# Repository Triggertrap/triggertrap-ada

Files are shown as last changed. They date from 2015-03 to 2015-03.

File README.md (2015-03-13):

# triggertrap-ada

Ada source code

##Contents

1. About Ada
2. Licence Information
3. About this document
4. Adafruit files
5. Atmel Libraries
6. Arduino Libraries
7. Ada project files
8. EEPROM addresses
9. Creating a new mode
10. Notes on building firmware

##1. About Ada

Ada is a project created by Triggertrap (triggertrap.com), designed to be the world's fastest and easiest to use high-speed camera trigger. An initial prototype was created for a Kickstarter project (tri.gg/kickstarter2), and a significant of additional work was completed in order to bring the product to market. 

Triggertrap was unsuccessful in putting Ada into production, but are releasing the work completed under a GPLv3 open source licence. For full information about where to find all open-source parts of Ada, please see: http://tri.gg/adasource

The electronics and firmware for Ada was developed by Cubik Innovation (cubik-innovation.co.uk). Some additional changes to the firmware was done by Nick Johnson of Arachnid Labs (arachnidlabs.com). 

For discussion about this source code, please see the Ada forum - http://forum.triggertrap.com/categories/triggertrap-ada

##2. Licence Information

For licence information, please see Licence.txt. 

Please note: 
* **Triggertrap**  is a trademark of Triggertrap Ltd, and may not be used without prior permission from Triggertrap. 
* **Timewarp**  is a trademark of Triggertrap Ltd, and may not be used without prior permission from Triggertrap. 
* **Ada** is a trademark of Triggertrap Ltd, and may not be used *commercially* without prior permission from Triggertrap. 
* **Arduino**, **Adafruit** and other trademarks may be present in the Ada source code. Please ensure that you respect the respective trademarks and trademark owners. 

##3. About this document

This project contains all the source files needed to compile the running code on the Ada device. An outline of what each file is and does is provided below

The project has been developed using files sourced from Atmel, Arduino, Adafruit and akafugu,  plus a number of application specific files written specially for this purpose.

##4. Adafruit files

Adafruit_PCD8544.cpp
Adafruit_PCD8544.h

* From lady ada and can be located at https://github.com/adafruit/Adafruit-PCD8544-Nokia-5110-LCD-library

Adafruit_GFX.cpp and Adafruit_GFX.h and glcdfont7x5.c

* From lady ada and can be located at https://github.com/adafruit/Adafruit-GFX-Library

## 5. Atmel Libraries

rtc.c
rtc.h

* Not used in project but included as an alternative to clock.c. Requires development

Iox128a3.h

* Chip specific header file

compiler.h and parts.h

* Compiler definitions and typedefs 

TC_driver.c
TC_driver.h

* Timer and counter driver files

## 6. Arduino Libraries

Arduino.h

* Holds defines used by Arduino 

binary.h

* Holds definitions for binary numbers used by Arduino

ByteBuffer.cpp
ByteBuffer.h

* Classes that handle buffer creation and use 

Client.h

* Arduino files for using internet protocols

HardwareSerial.h

* UART header file 

IPAddress.cpp

IPAddress.h

* Contains functions to handle IP addresses used by Arduino

main.cpp

* main program entry, just calls application main

new.cpp and new.h

* Contains new and delete operators for dynamic memory allocation

pins_arduino.h

* Pin mapping of the hardware against Arduino standard definitions

Print.cpp and Print.h

* Contains functions such as print() and println()

Printable.h

* Interface class that allows printing of complex types

Server.h

* Function headers for Ethernet related files

Stream.cpp

Stream.h

* adds parsing methods to Stream class

Tone.cpp

* Tone Generation

WCharacter.h

* Character utility functions for Wiring & Arduino

WInterupts.c

* Functions relating to interrupts of the device

Wire.h

* Two wire library for Arduino & wiring

wiring.c

* Contains low level drivers for delays initiating IO ports, ADCs etc

wiring_analog.c

* Contains functions relating to ADC and PWM

wiring_digital.c

* digital input and output functions

wiring_private.h

* definitions for wiring

EEPROM.cpp and EEPROM.h

* Arduino EEPROM library

Udp.h

* Arduino library to send/receive UDP packets
* 
* All files originated from http://arduino.cc/ but files have been modified to fit with the ATXMEGA and have therefore been based on files obtained from http://www.akafugu.jp/posts/products/akafuino_x/

###/debug (folder)

avrdude.exe

* avrdude compiler 

Makefile

* Project makefile

upload.bat

* bootloader upload batch file

## 6. Ada project files

glcdfont7x5.c

* Contains bitmaps for the 7x5 font used in the project.

AdvancedSensor.cpp

* Contains all functions relating to Advanced Sensor mode

BulbRamp.cpp

* Contains all functions relating to Bulb Ramp mode

Clock.cpp
Clock.h

* Contains all functions relating to the system clock time

eeprom_addresses.h

* Contains all addresses for the EEPROM used in the project

glcdfont.c

* Contains the pixel maps for the 5x5 font used in the project

guimenu.cpp

guimenu.h

* Contains all low level functions related to the graphical user interface

guimenu_pages.c

* Contains the data for the menu banners

guimenu_pages.h

* Contains the GUI page definitions

guimenupages.cpp

* Contains the Ada splash screen logo and the information for each page

HardwareGlobals.h

* Contains the definitions for the pins on the processor that are used in the project

Inputs.cpp
Inputs.h

* Contains all the functions related to user input from the buttons

LongExposureHDR.cpp

LongExposureHDR.h

* Contains all functions relating to the long exposure high dynamic range mode

Menu.h

* Contains all the prototypes for the functions accessed by the menu

MenuDefines.h

* Contains defines for the menu state machine along with some other misc defines

MobileTrigger.cpp

* Contains a function that sets up the PWM required for mobile out

NewMode.cpp

NewMode.h

* Contains examples for how to create your own mode within the unit

Sensor.cpp

* Contains functions relating to the sensor mode

SensorConfigs.cpp

* Contains functions for sending configurations to the sensors

SensorTimelapse.cpp

* Contains functions for sensor timelapse mode

SensorVideo.cpp

* Contains functions for sensor video mode

Settings.cpp

* Contains functions for the settings page

StarTrail.cpp

* Contains functions for startrail mode

StateMachine.cpp

* This file contains the main framework of the menu system. It must be called periodically in order to update the menu.

TriggerTrap.cppproj

* Atmel studio project file

TriggerTrap_main.cpp

* Main project entry file contains the high level operations of the system

tt_strings.dat

* Contains the strings used throughout the menu and the array that contains them

tt_strings.h

* Contains the definitions of the individual string location in the data array

Timelapse.cpp

Timelapse.h

* Contains the functions related to the timelapse mode

TimeWarp.cpp

* Contains the functions related to the timewarp mode
 
## 8. EEPROM addresses

EEPROM locations are referenced in the code using their labels, however the absolute addresses may be found in eeprom_addresses.h

###System Settings
EEPROM_STACK_CONFIG

* Data to determine if the stack is in AND/OR mode

EEPROM_LCD_CONTRAST_SET

* Determines if the contrast has been set by the user/factory yet

EEPROM_LCD_CONTRAST

* Data for the LCD contrast value

### Timelapse Settings
EEPROM_TIMELAPSE_INTERVAL_HI

EEPROM_TIMELAPSE_INTERVAL_LO

EEPROM_TIMELAPSE_INTERVAL_UNITS

* Setting for the delay between shots in timelapse mode

EEPROM_TIMELAPSE_COUNT_HI

EEPROM_TIMELAPSE_COUNT_LO

EEPROM_TIMELAPSE_COUNT_UNITS

* How many shots in the timelapse train

EEPROM_TIMELAPSE_STARTDELAY_HI

EEPROM_TIMELAPSE_STARTDELAY_LO

EEPROM_TIMELAPSE_STARTDELAY_UNITS

* Delay before the timelapse should start

EEPROM_TIMELAPSE_ACTIVE

* Defines if timelapse is limited by a time frame or not

###Timewarp Settings

EEPROM_TIMEWARP_COUNT_HI

EEPROM_TIMEWARP_COUNT_LO

* Holds data for how many shots are in timewarp

EEPROM_TIMEWARP_DURATION_HI

EEPROM_TIMEWARP_DURATION_LO

EEPROM_TIMEWARP_DURATION_UNITS

* Holds data for how the duration of the timewarp function

EEPROM_TIMEWARP_FUNCTION

* Defines if timewarp works as Quadratic/Quartic/Quintic

EEPROM_TIMEWARP_DIRECTION

* Defines the direction of the timewarp function

EEPROM_TIMEWARP_WAIT_HI

EEPROM_TIMEWARP_WAIT_LO

EEPROM_TIMEWARP_WAIT_UNITS

* Defines the wait before starting time

###Bulb Ramping
EEPROM_BULBRAMP_START_EXPOSURE

* Relates to Bulbramp start exposure value

EEPROM_BULBRAMP_END_EXPOSURE

* Relates to Bulbramp end exposure value

EEPROM_BULBRAMP_STARTDELAY_HI

EEPROM_BULBRAMP_STARTDELAY_LO

EEPROM_BULBRAMP_STARTDELAY_UNITS

* Holds data for the bulbramp start delay

EEPROM_BULBRAMP_COUNT_HI

EEPROM_BULBRAMP_COUNT_LO

* Holds data for the bulbramp count

EEPROM_BULBRAMP_DURATION_HI

EEPROM_BULBRAMP_DURATION_LO

EEPROM_BULBRAMP_DURATION_UNITS

* Holds data for the bulbramp duration

###Star Trail

EEPROM_STARTTRAIL_INTERVAL_HI

EEPROM_STARTTRAIL_INTERVAL_LO

EEPROM_STARTTRAIL_INTERVAL_UNITS

* Holds data for the interval time

EEPROM_STARTTRAIL_SHUTTERSPEED_HI

EEPROM_STARTTRAIL_SHUTTERSPEED_LO

EEPROM_STARTTRAIL_SHUTTERSPEED_UNITS

* Holds data for the star trail shutter speed

EEPROM_STARTTRAIL_COUNT_HI

EEPROM_STARTTRAIL_COUNT_LO

* Holds data for the startrail count

EEPROM_STARTTRAIL_WAIT_HI

EEPROM_STARTTRAIL_WAIT_LO

EEPROM_STARTTRAIL_WAIT_UNITS

* Holds data for Startrail wait time

###High Speed Flash
EEPROM_HSF_TRIGGERON

* Data for stack configuration for this mode

EEPROM_HSF_CLOSESHUTTER

* Data for determining if the shutter should close

EEPROM_HSF_SHUTTERCYCLE_HI

EEPROM_HSF_SHUTTERCYCLE_LO

EEPROM_HSF_SHUTTERCYCLE_UNITS

* Shutter cycle time

EEPROM_HSF_FLASHDELAY_HI

EEPROM_HSF_FLASHDELAY_LO

EEPROM_HSF_FLASHDELAY_UNITS

* Flash delay time

EEPROM_HSF_RESETDELAY_HI

EEPROM_HSF_RESETDELAY_LO

EEPROM_HSF_RESETDELAY_UNITS

* Reset delay time

EEPROM_HSF_TIMESACTIVE

* Determines if HSF mode is bound by a time window

EEPROM_HSF_START_HOURS

EEPROM_HSF_START_MINS

EEPROM_HSF_END_HOURS

EEPROM_HSF_END_MINS

* Start and end times for HSF times active

###Sensor

EEPROM_SENSOR_TRIGDELAY_HI

EEPROM_SENSOR_TRIGDELAY_LO

EEPROM_SENSOR_TRIGDELAY_UNITS

* Sensor trigger delay times

EEPROM_SENSOR_TRIGGERON

* Data for stack configuration for this mode

EEPROM_SENSOR_MOBILEIP

* Mobile input on/off indicator

EEPROM_SENSOR_MOBILEOP

* Mobile output on/off indicator

EEPROM_SENSOR_TIMESACTIVE

* Determines if sensor mode is bound by a time window

###Sensor Timelapse

EEPROM_SENSORTLAPSE_DELAY_HI

EEPROM_SENSORTLAPSE_DELAY_LO

EEPROM_SENSORTLAPSE_DELAY_UNITS

* Sensor time lapse delay time

EEPROM_SENSORTLAPSE_INTERVAL_HI

EEPROM_SENSORTLAPSE_INTERVAL_LO

EEPROM_SENSORTLAPSE_INTERVAL_UNITS

* Sensor timelapse interval time

EEPROM_SENSORTLAPSE_CONTINUE_HI

EEPROM_SENSORTLAPSE_CONTINUE_LO

* Determines how many shots to continue for

EEPROM_SENSORTLAPSE_TRIGGERON

* Data for stack configuration for this mode

EEPROM_SENSORTLAPSE_MOBILEIP

* Mobile input on/off indicator

EEPROM_SENSORTLAPSE_MOBILEOP

* Mobile output on/off indicator

EEPROM_SENSORTLAPSE_TIMESACTIVE

* Determines if sensor timelapse mode is bound by a time window

###Sensor Video
EEPROM_SENSORVIDEO_DELAY_HI

EEPROM_SENSORVIDEO_DELAY_LO

EEPROM_SENSORVIDEO_DELAY_UNITS

* Sensor video setup delay time

EEPROM_SENSORVIDEO_STOPAFTER_HI

EEPROM_SENSORVIDEO_STOPAFTER_LO

EEPROM_SENSORVIDEO_STOPAFTER_UNITS

* Sensor video stop after time setting

EEPROM_SENSORVIDEO_TRIGGER

* Camera/Mobile/Both setting

EEPROM_SENSORVIDEO_TIMESACTIVE

* Determines if sensor mode is bound by a time window

EEPROM_SENSORVIDEO_TRIGGERON

* Data for stack configuration for this mode

###Advanced Sensor

EEPROM_ADVSENSOR_CHAN1A

EEPROM_ADVSENSOR_CHAN1B

EEPROM_ADVSENSOR_CHAN2A

EEPROM_ADVSENSOR_CHAN2B

EEPROM_ADVSENSOR_CHAN3A

EEPROM_ADVSENSOR_CHAN3B

* Unused

EEPROM_ADVSENSOR_TRIGMOBILE

* Defines if the mobile output is enabled or not

###Settings

EEPROM_CAMERAPREFOCUS_HI

EEPROM_CAMERAPREFOCUS_LO

EEPROM_CAMERAPREFOCUS_UNITS

* Camera prefocus time 

EEPROM_FLASHPULSE_HI

EEPROM_FLASHPULSE_LO

EEPROM_FLASHPULSE_UNITS

* Camera flash pulse time

EEPROM_SHUTTERPULSE_HI

EEPROM_SHUTTERPULSE_LO

EEPROM_SHUTTERPULSE_UNITS

* Shutter open time

EEPROM_TIMELAPSE_STARTHOURS

EEPROM_TIMELAPSE_STARTMINS

EEPROM_TIMELAPSE_ENDHOURS

EEPROM_TIMELAPSE_ENDMINS

* Timelapse start and end times for times active mode

EEPROM_SENSORVIDEO_START_HOURS

EEPROM_SENSORVIDEO_START_MINS

EEPROM_SENSORVIDEO_END_HOURS

EEPROM_SENSORVIDEO_END_MINS

* Sensor video start and end times for times active mode

###LE_HDR
EEPROM_LEHDR_MID_EXP

* LEHDR middle exposure length

EEPROM_LEHDR_SHOTS

* LEHDR number of shots

EEPROM_LEHDR_EVPERSHOT

* The amount at which the exposure should change between shots

EEPROM_LEHDR_TIMELAPSE_HI

EEPROM_LEHDR_TIMELAPSE_LO

EEPROM_LEHDR_TIMELAPSE_UNITS

* LEHDR timelapseinterval time

EEPROM_SENSOR_TL_START_HOURS

EEPROM_SENSOR_TL_START_MINS

EEPROM_SENSOR_TL_END_HOURS

EEPROM_SENSOR_TL_END_MINS

* Sensor Timelapse start and end times

EEPROM_SENSORTLAPSE_CONTINUE

* Defines if sensor timelapse mode will stop on absence of sensor activity/infinite shots/x shots

EEPROM_SENSOR_REST_DELAY_HI

EEPROM_SENSOR_REST_DELAY_LO

EEPROM_SENSOR_RESET_UNITS

* Sensor reset delay time

EEPROM_SENSOR_START_HOURS

EEPROM_SENSOR_START_MINS

EEPROM_SENSOR_END_HOURS

EEPROM_SENSOR_END_MINS

* Sensor start and end times for times active mode

###Advanced Sensor

EEPROM_ADVSENSOR_CHAN1A_DELAY_HI

EEPROM_ADVSENSOR_CHAN1A_DELAY_LO

EEPROM_ADVSENSOR_CHAN1A_DELAY_UNITS

* Advanced Sensor channel 1A delay time

EEPROM_ADVSENSOR_CHAN1B_DELAY_HI

EEPROM_ADVSENSOR_CHAN1B_DELAY_LO

EEPROM_ADVSENSOR_CHAN1B_DELAY_UNITS

* Advanced Sensor channel 1B delay time

EEPROM_ADVSENSOR_CHAN2A_DELAY_HI

EEPROM_ADVSENSOR_CHAN2A_DELAY_LO

EEPROM_ADVSENSOR_CHAN2A_DELAY_UNITS

* Advanced Sensor channel 2A delay time

EEPROM_ADVSENSOR_CHAN2B_DELAY_HI

EEPROM_ADVSENSOR_CHAN2B_DELAY_LO

EEPROM_ADVSENSOR_CHAN2B_DELAY_UNITS

* Advanced Sensor channel 2B delay time

EEPROM_ADVSENSOR_CHAN3A_DELAY_HI

EEPROM_ADVSENSOR_CHAN3A_DELAY_LO

EEPROM_ADVSENSOR_CHAN3A_DELAY_UNITS

* Advanced Sensor channel 3A delay time

EEPROM_ADVSENSOR_CHAN3B_DELAY_HI

EEPROM_ADVSENSOR_CHAN3B_DELAY_LO

EEPROM_ADVSENSOR_CHAN3B_DELAY_UNITS

* Advanced Sensor channel 1A delay time

###pulse duration

EEPROM_ADVSENSOR_CHAN1A_PULSE_HI

EEPROM_ADVSENSOR_CHAN1A_PULSE_LO

EEPROM_ADVSENSOR_CHAN1A_PULSE_UNITS

* Advanced Sensor channel 1A pulse length

EEPROM_ADVSENSOR_CHAN1B_PULSE_HI

EEPROM_ADVSENSOR_CHAN1B_PULSE_LO

EEPROM_ADVSENSOR_CHAN1B_PULSE_UNITS

* Advanced Sensor channel 1B pulse length

EEPROM_ADVSENSOR_CHAN2A_PULSE_HI

EEPROM_ADVSENSOR_CHAN2A_PULSE_LO

EEPROM_ADVSENSOR_CHAN2A_PULSE_UNITS

* Advanced Sensor channel 2A pulse length

EEPROM_ADVSENSOR_CHAN2B_PULSE_HI

EEPROM_ADVSENSOR_CHAN2B_PULSE_LO

EEPROM_ADVSENSOR_CHAN2B_PULSE_UNITS

* Advanced Sensor channel 2B pulse length

EEPROM_ADVSENSOR_CHAN3A_PULSE_HI

EEPROM_ADVSENSOR_CHAN3A_PULSE_LO

EEPROM_ADVSENSOR_CHAN3A_PULSE_UNITS

* Advanced Sensor channel 3A pulse length

EEPROM_ADVSENSOR_CHAN3B_PULSE_HI

EEPROM_ADVSENSOR_CHAN3B_PULSE_LO

EEPROM_ADVSENSOR_CHAN3B_PULSE_UNITS

* Advanced Sensor channel 3B pulse length

EEPROM_ADVSENSOR_REST_DELAY_HI

EEPROM_ADVSENSOR_REST_DELAY_LO

EEPROM_ADVSENSOR_REST_DELAY_UNITS

* Advanced Sensor reset delay time

EEPROM_ADVSENSOR_TRIGGER_ON

* Data for stack configuration for this mode

EEPROM_TIME_HOURS

EEPROM_TIME_MINS

EEPROM_TIME_SECS

* RTC has a roll-over of approx. 18hrs. Alarm is configured to wake the micro before then, save the current time here and reset the counter

EEPROM_NEWMODE_TRIGGERON

EEPROM_NEWMODE_DELAY_HI

EEPROM_NEWMODE_DELAY_LO

EEPROM_NEWMODE_DELAY_UNITS

* Delay times for new mode example

EEPROM_NONE

* Null

##9. Creating a new mode

* Examples on how to include a new mode have been given in this project. The user must add in the definition: 

define INCLUDE_NEWMODE 

* This could either be defined in a file such as MenuDefines.h or it could be added as a symbol in the project properties. This will allow an example mode to appear on the device. This can be modified at will for experimentation. 

* Further information on how to make your own mode can be found in the comments of NewMode.cpp

##10. Notes on building firmware
The Baseblock firmware has been updated so it can be built using avr-gcc and make, however both the Bootloader and the Sensor firmware have not been converted to allow for this process.

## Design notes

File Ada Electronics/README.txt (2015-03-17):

IMPORTANT NOTE

To facilitate expediency in releasing these files, these are the actual production files that were to be use for Ada's production run. 

As such, they may include 'Triggertrap', 'Ada' and 'Tt' logos, and references to 'TimeWarp', all of which are trademarked. If you intend to use these files, ensure that the logos are removed from the models, PCB, and source code etc before they are used. 

The files may also include references to FCC and CE marking and certification. These tests were completed with prototypes, but the certifications may not apply to you. As such, please ensure that the FCC and CE markings are removed, or that your device is re-certified, before you use these files.

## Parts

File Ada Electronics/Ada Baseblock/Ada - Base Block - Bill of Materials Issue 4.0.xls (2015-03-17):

Project Number | TRI002
Variant: | Var1 of TRI002 Base Unit Issue 4.0
Creation Date: | 10/13/2014 |  | 5:43:55 PM
Print Date: | 2014-10-13 |  | 17:44:30
BOM VERSION | Issue 4.0
Designator | Fitted | Value | Voltage | Footprint | Quantity | Supplier | Part No. | Qty to Order | Manufacturer | Manuf Part #
C1, C2 | Fitted | 18pF | 50V | C0603 | 2 | FEC | 1414620 |  | KEMET | C0603C180J5GAC
C3, C4, C8, C16, C20 | Fitted | 100nF | 50V | C0603 | 5 | Rapid | 71-1964 |  | TruCap | U0603R103
C5, C6, C18, C19 | Fitted | 10nF | 50V | C0603 | 4 | Rapid | 71-1964 |  | MULTICOMP | MCCA000238
C7, C10, C11 | Fitted | 1uF | 16V | C0603 | 3 | FEC | 1288256 |  | KEMET | C0603C105K4PAC
C9 | Fitted | 4u7F | 10V | KEMET CASE A | 1 | FEC | 1457427 |  | KEMET | T491A475K010AT
C12 | Fitted | 47uF | 16V | CAP6.8/6.8 | 1 | FEC | 8823200 |  | NICHICON | UUT1C470MCL1GS
C13, C17 | Fitted | 2u2F | 16V | C0603 | 2 | FEC | 1658871 |  | AVX | 0603YD225KAT2A
C15 | Fitted | 220uF | 16V | CAP6.8/6.8 | 1 | FEC | 1539479 |  | PANASONIC | EEEFPC221XAP
D1, D2 | Fitted | SS12 E3 | 20V | DO214-AA | 2 | Rapid | 47-0988 |  | Taiwan Semiconductor | SS12 E3
D3 | Fitted | MBRM110LT3G | ?V | POWERMITE | 1 | FEC | 1459062 |  | ON SEMICONDUCTOR | MBRM110LT3G
F1 | Fitted | polyfuse | 24V max | 1210 FUSE | 1 | FEC | 1822208 |  | LITTELFUSE | 1210L050YR
J2 | Fitted | Daughter Board Con |  | sip3 | 1
J3, J6, J7, J9 | Fitted | 2.5mm |  | 2.5mm socket TRI001 | 4 | FEC | 1280745 |  | PRO SIGNAL | PSG01539
J4 | Fitted | JTAG Header |  | HDR2X3 | 1 | Rapid | 22-0500 |  | TruConnect
J5 | Fitted | FFC 6 way top contact |  | HLW6R-2C7LF | 1 | MOUSER | 649-HLW6R-2C7LF |  | FCI | HLW6R-2C7LF
J8 | Fitted | 22-05-7025 |  | Molex 0022057025 | 1 | FEC | 9979670 |  | MOLEX | 22-05-7025
J10 | Fitted | micro USB Female |  | micro usb receptacle | 1 | MOUSER | 649-10118192-0001LF |  | FCI | 10118192-0001LF
J11 | Fitted | 3.5MM 4 pole Socket |  | Cliff 3.5mm 4 pole socket | 1 | FEC | 2309468 |  | CLIFF ELECTRONIC | FC68125
J12 | Fitted | Stack Con |  | sip3 | 1
L1, L3, L4, L5, L6 | Fitted | BLM18EG221TN1D |  | L0603 | 5 | FEC | 1515717 |  | MURATA | BLM18EG221TN1D
L2 | Fitted | 10µH |  | WE-PD2_5848 | 1 | FEC | 1636014 |  | Würth Elektronik eiSos GmbH | 74477410
LCD1 | Fitted | LPH7366-1 |  | LPH-7366 | 1 | www.008620.net | LPH7366-1 |  | Na | na
LED1, LED2, LED3, LED4 | Fitted | MCL-S270SRC |  | LED, RED, 0805 | 4 | FEC | 1581239 |  | MULTICOMP | MCL-S270SRC
Q1 | Fitted | FDN335N |  | SOT-23 | 1 | FEC | 9845348RL |  | FAIRCHILD SEMICONDUCTOR | FDN335N
Q2 | Fitted |  | 8V | SOT-23 DIODE - duplicate | 1 | FEC | NTR2101PT1G |  | ON SEMICONDUCTOR | NTR2101PT1G
Q3 | Fitted | BC847B |  | SOT-23T | 1
Q4 | Fitted | NTGS3446T1G |  | TSOP6 | 1 | RS | 802-4221 |  | ON Semiconductor | NTGS3446T1G
R1, R2, R3, R4, R5, R6, R8, R25, R27, R28, R36 | Fitted | 10k |  | R0603 | 11
R7, R12 | Fitted | 1M |  | R0603 | 2
R9, R11, R30, R31 | Fitted | 100R |  | R0603 | 4
R10, R13, R15, R16, R17, R18, R19, R20, R26 | Fitted | 1K |  | R0603 | 9
R14, R29 | Fitted | 220R |  | R0603 | 2
R21, R23 | Fitted | 22R |  | R0603 | 2
R22, R24 | Fitted | 4K7 |  | R0603 | 2
R32, R35 | Fitted | 0R |  | R0603 | 2
U1 | Fitted | ATXMEGA128A3-AU |  | 64A_N | 1 | FEC | 1748550 |  | ATMEL | ATXMEGA128A3-AU
U2, U3, U5, U6, U7, U8 | Fitted | LTV-357T |  | SMD-4 | 6 | MOUSER | 859-LTV-357T |  | Lite-on | LTV-357T
U4 | Fitted | AAT3221IGV-3.3-T1 |  | TSOT 5 pin | 1 | MOUSER | 873-AAT3221IGV-33T1 |  | Skyworks Solutions | AAT3221IGV-3.3-T1
U9 | Fitted | NCP1450ASN50T1G |  | SOT23-5AN | 1 | FEC | 1460676 |  | ON SEMICONDUCTOR | NCP1450ASN50T1G
U10 | Fitted | FT230X |  | SSOP-16_N | 1 | MOUSER | 895-FT230XS-R |  | FTDI | FT230XS-R
X1 | Fitted | 32.768KHz |  | FC 13F | 1 | FEC | 1712821 |  | EPSON TOYOCOM | FC-13F,32.768KHZ, 12.5PF
C14 | Not Fitted | 100nF | 50V | C0603 | 0 | Rapid | 71-1964 |  | TruCap | U0603R103
R33, R34 | Not Fitted | 0R |  | R0603 | 0

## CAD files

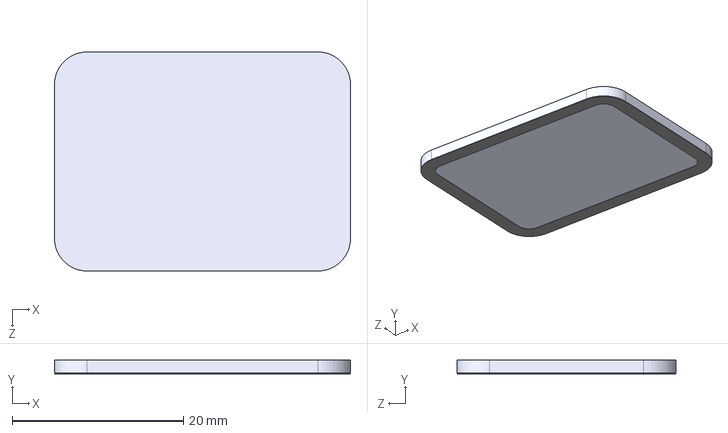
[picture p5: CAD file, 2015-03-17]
Ada Casing/TT-Issue-A_STP_files/TT-113-A_ADA_LCD_SCREEN.STEP
34.6 x 1.60 x 25.6 mm

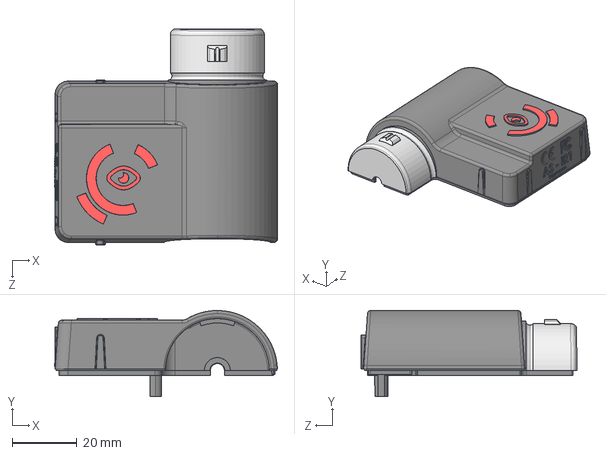
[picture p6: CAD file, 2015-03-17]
Ada Casing/TT-Issue-A_STP_files/TT-221-A_SENSOR_FRONT_CASE_PIR.STEP
68.7 x 26.5 x 66.5 mm

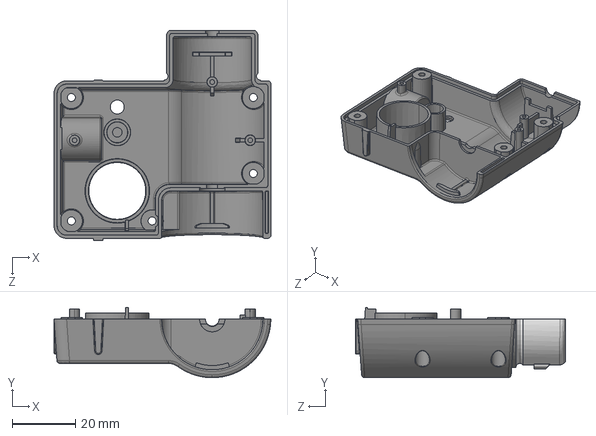
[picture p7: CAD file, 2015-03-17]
Ada Casing/TT-Issue-A_STP_files/TT-211-A_SENSOR_BACK_CASE_PIR_SOUND_LIGHT.STEP
68.6 x 22.3 x 66.5 mm

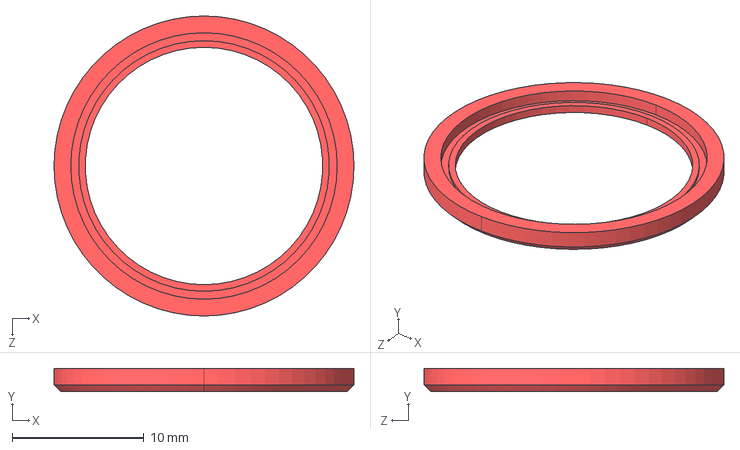
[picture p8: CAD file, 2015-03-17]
Ada Casing/TT-Issue-A_STP_files/TT-231-A_LENS_RETAINING_RING.STEP
22.8 x 1.75 x 22.8 mm

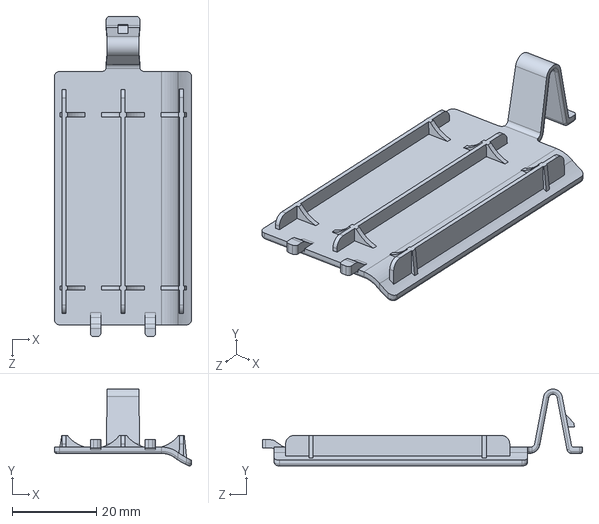
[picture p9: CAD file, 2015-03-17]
Ada Casing/TT-Issue-A_STP_files/TT-120-A_ADA_BASE_BATTERY_COVER.STEP
32.5 x 18.2 x 75.8 mm

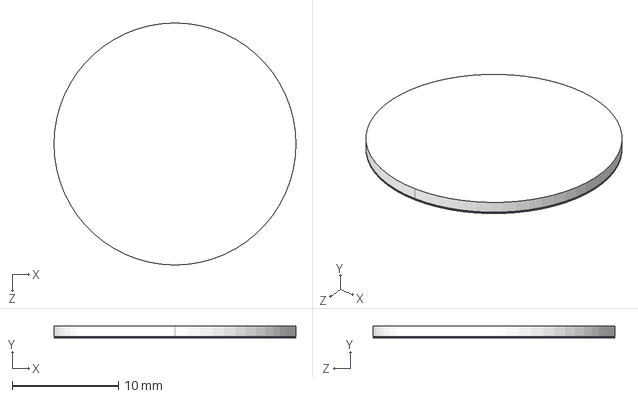
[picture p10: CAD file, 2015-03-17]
Ada Casing/TT-Issue-A_STP_files/TT-230-A_SENSOR_DISC_LASER_LIGHT.STEP
22.8 x 1.15 x 22.8 mm

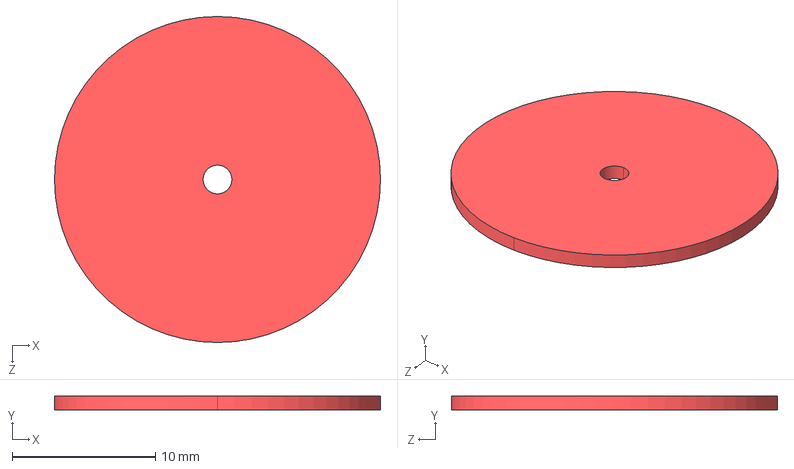
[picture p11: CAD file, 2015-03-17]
Ada Casing/TT-Issue-A_STP_files/TT-232-A_SENSOR_DISC_SOUND.STEP
22.8 x 1.00 x 22.8 mm

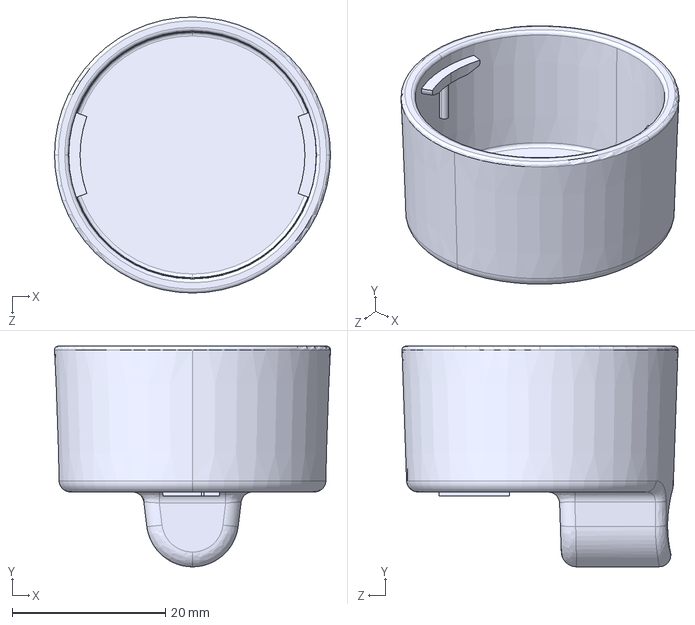
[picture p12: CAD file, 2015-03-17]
Ada Casing/TT-Issue-A_STP_files/TT-260-A_ADA_MIRROR_BODY.STEP
36.0 x 28.7 x 36.0 mm

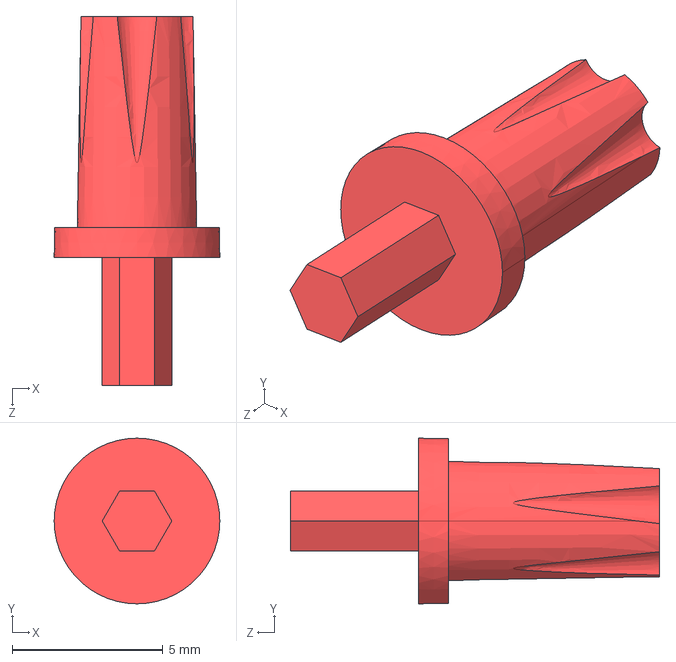
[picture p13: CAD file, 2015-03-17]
Ada Casing/TT-Issue-A_STP_files/TT-250-A_SENSOR_pot_knob.STEP
5.50 x 5.50 x 12.2 mm

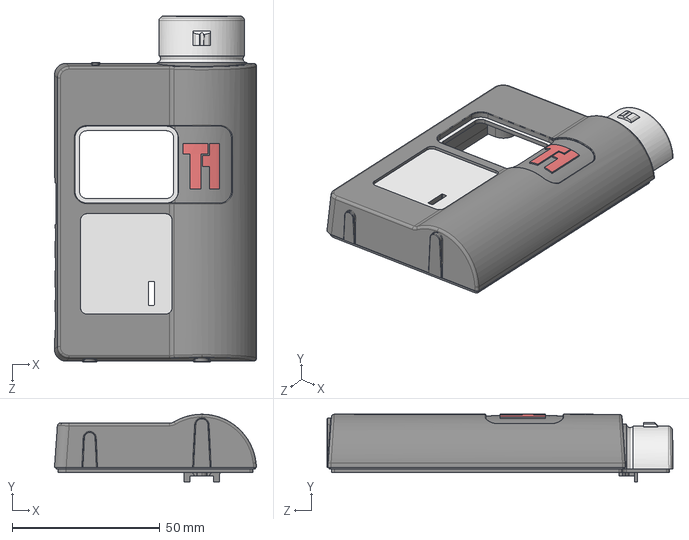
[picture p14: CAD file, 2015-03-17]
Ada Casing/TT-Issue-A_STP_files/TT-110-A_ADA_BASE_FRONT_CASE.STEP
68.5 x 22.9 x 117.2 mm

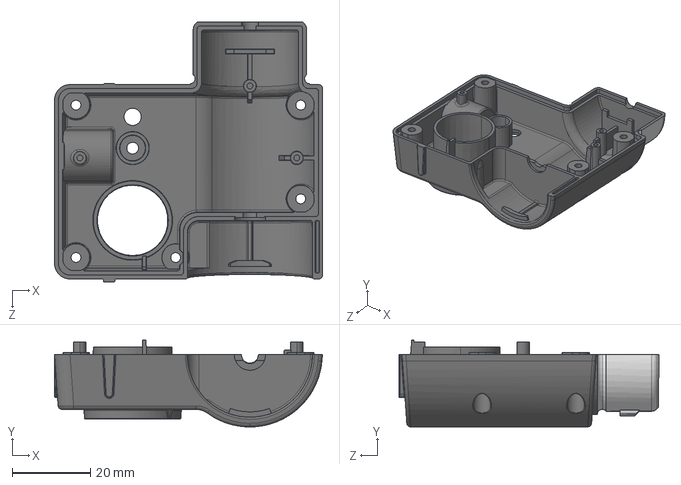
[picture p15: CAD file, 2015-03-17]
Ada Casing/TT-Issue-A_STP_files/TT-210-A_SENSOR_BACK_CASE_LASER.STEP
68.6 x 22.3 x 66.5 mm

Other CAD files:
Triggertrap Sensors/TRIG.X/dist/default/production/TRIG.X.production.obj
Triggertrap Sensors/TRIG.X/l.obj
Ada Casing/TT-Issue-A_STP_files/TT-222-A_SENSOR_FRONT_CASE_SOUND.STEP
Ada Casing/TT-Issue-A_STP_files/TT-225-A_SENSOR_FRONT_CASE_LIGHT.STEP
Ada Casing/TT-Issue-A_STP_files/TT-220-A_SENSOR_FRONT_CASE_LASER.STEP

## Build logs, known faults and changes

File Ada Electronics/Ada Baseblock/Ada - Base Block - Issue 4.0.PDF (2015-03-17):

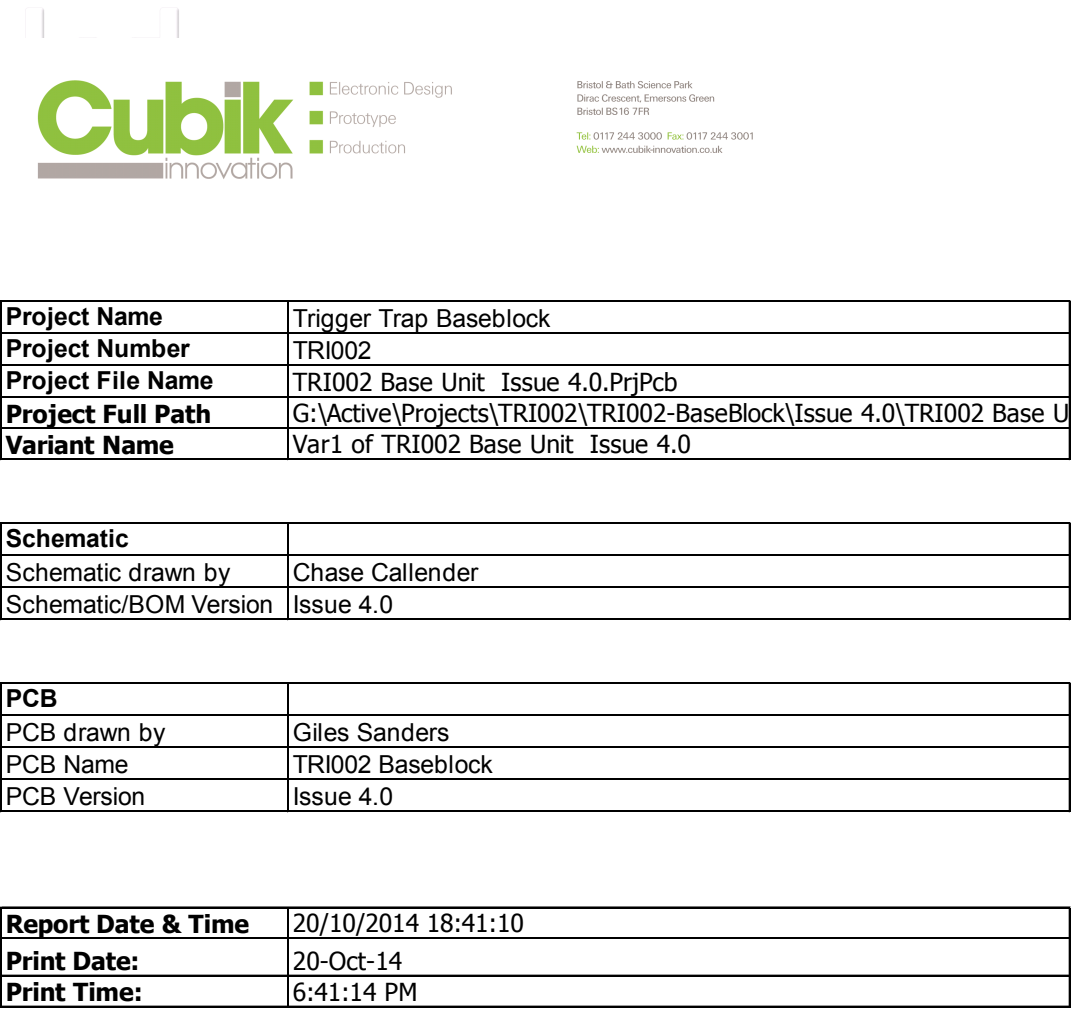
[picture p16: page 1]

Project Name | Trigger Trap Baseblock
Project Number | TRI002
Project File Name | TRI002 Base Unit Issue 4.0.PrjPcb
Project Full Path | G:\Active\Projects\TRI002\TRI002-BaseBlock\Issue 4.0\TRI002 Base U
Variant Name | Var1 of TRI002 Base Unit Issue 4.0

Schematic
Schematic drawn by | Chase Callender
Schematic/BOM Version | Issue 4.0

PCB
PCB drawn by | Giles Sanders
PCB Name | TRI002 Baseblock
PCB Version | Issue 4.0

Report Date & Time | 20/10/2014 18:41:10
Print Date: | 20-Oct-14
Print Time: | 6:41:14 PM

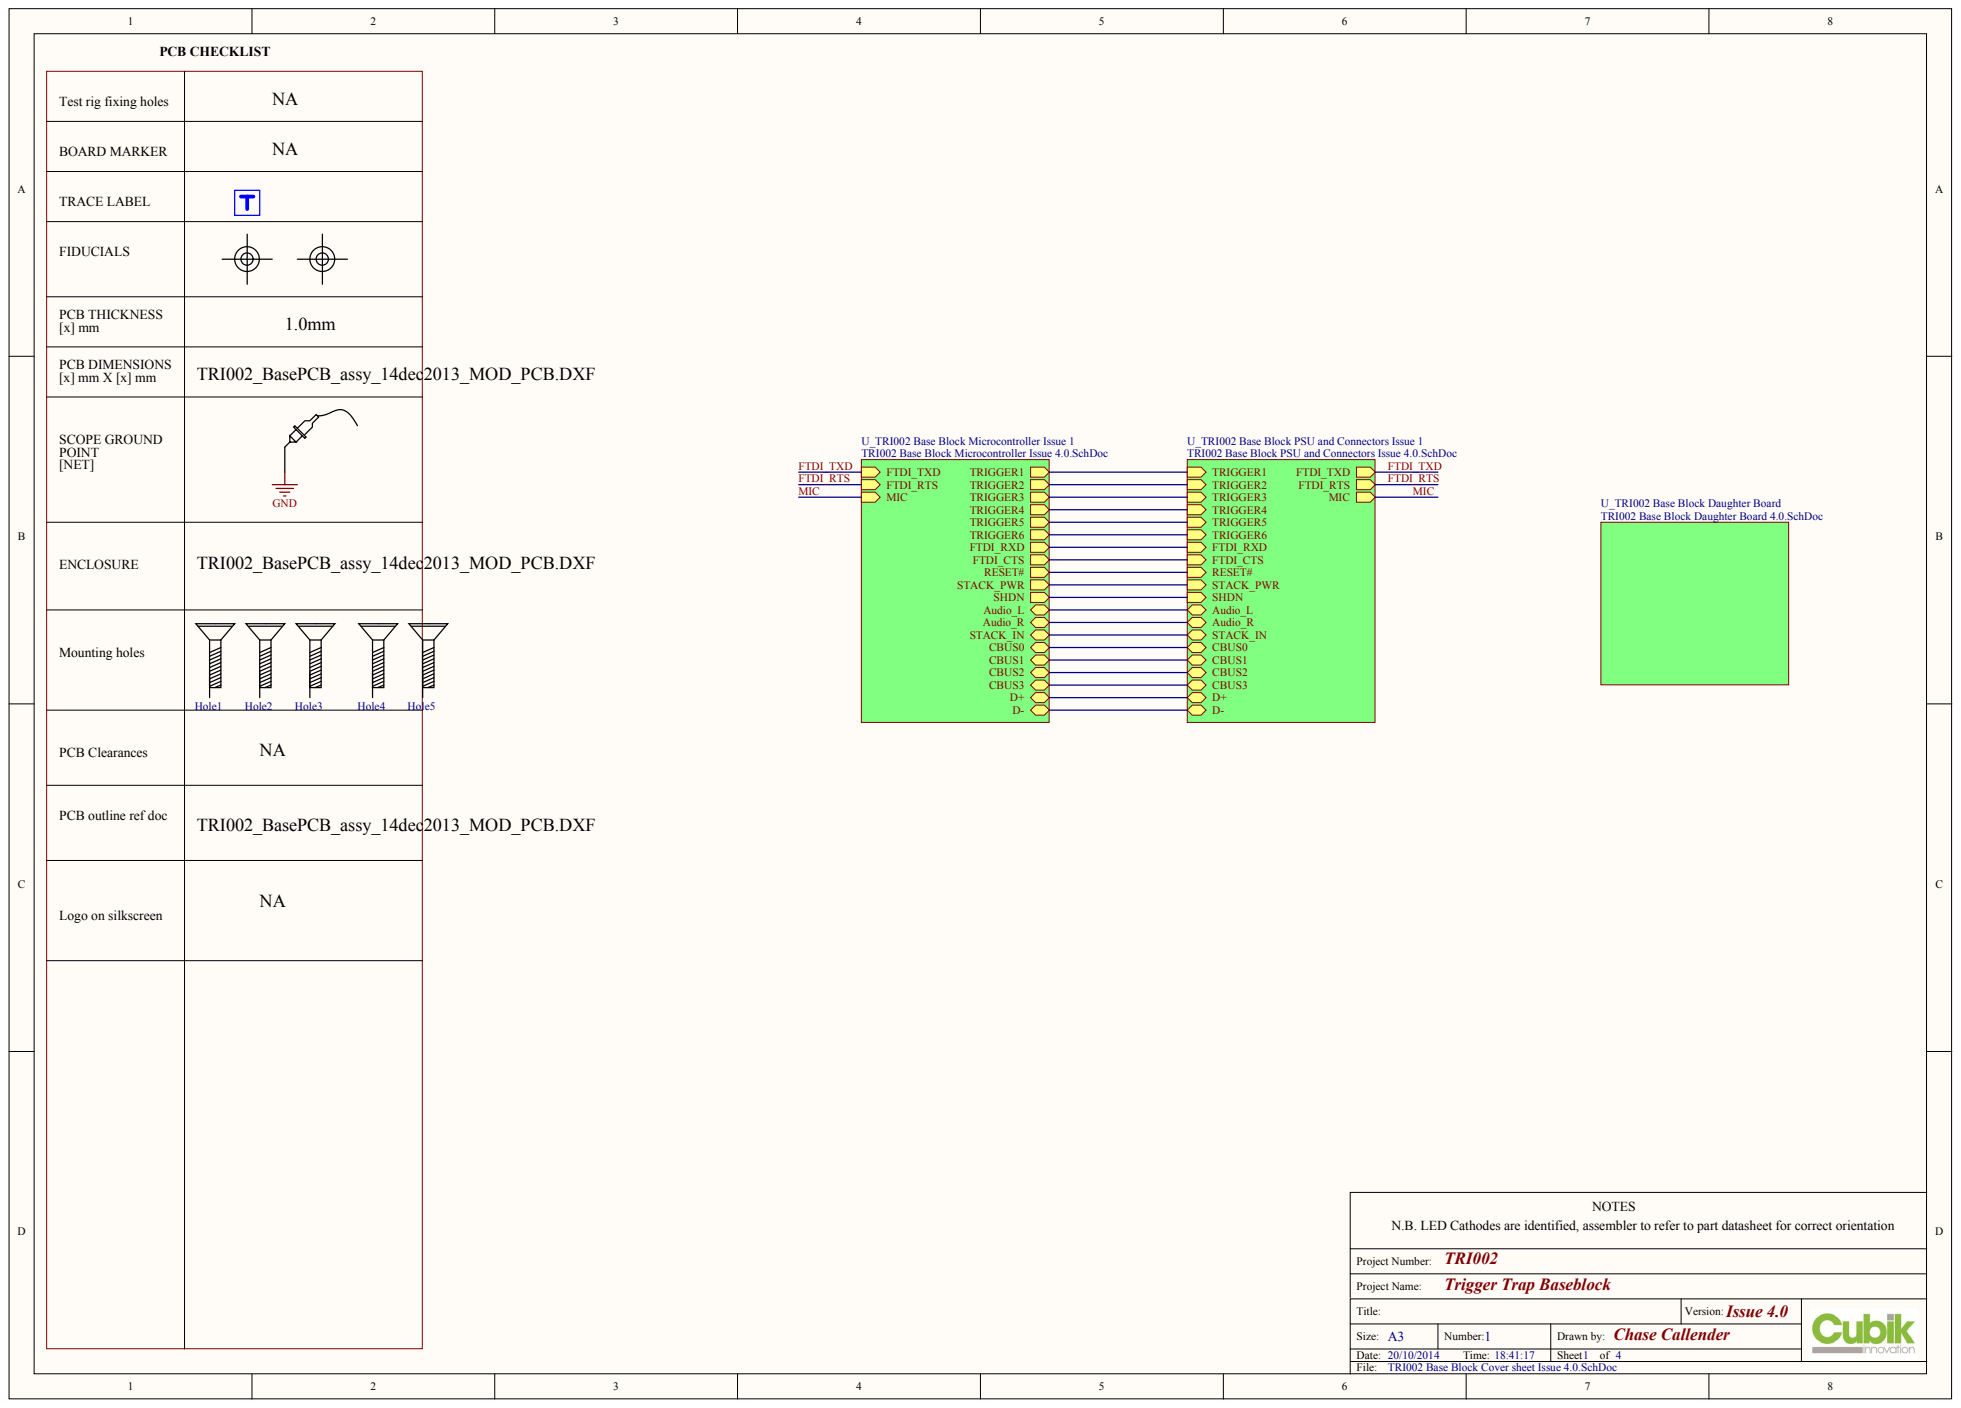
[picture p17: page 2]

Test rig fixing holes | NA

BOARD MARKER | NA

TRACE LABEL

FIDUCIALS

PCB THICKNESS [x] mm | 1.0mm

PCB DIMENSIONS [x] mm X [x] mm

SCOPE GROUND POINT [NET]

U_TRI002 Base Block Microcontroller Issue 1
TRI002 Base Block Microcontroller Issue 4.0.SchDoc
FTDI_TXD
FTDI_RTS
MIC

U_TRI002 Base Block Daughter Board
TRI002 Base Block Daughter Board 4.0.SchDoc

ENCLOSURE | TRI002_BasePCB_assy_14dec2013_MOD_PCB.DXF

Mounting holes

PCB Clearances | NA

PCB outline ref doc

Logo on silkscreen | NA

N.B. LED Cathodes are identified, assembler to refer to part datasheet for correct orientation

Title: | Issue 4.0 Version:
Size: A3 | Number: 1 | Drawn by: Chase Callender

Date: 20/10/2014 Time: 18:41:17 | | Sheet 1 of 4

TRI002 Base Block Cover sheet Issue 4.0.SchDoc

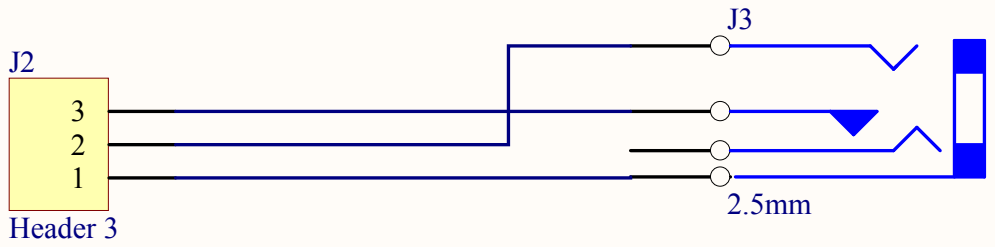
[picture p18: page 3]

Title: | Issue 4.0 Version:
Size: A | Number: 2 | Chase Callende r

Date: Time: | | Sheet 2 of 4

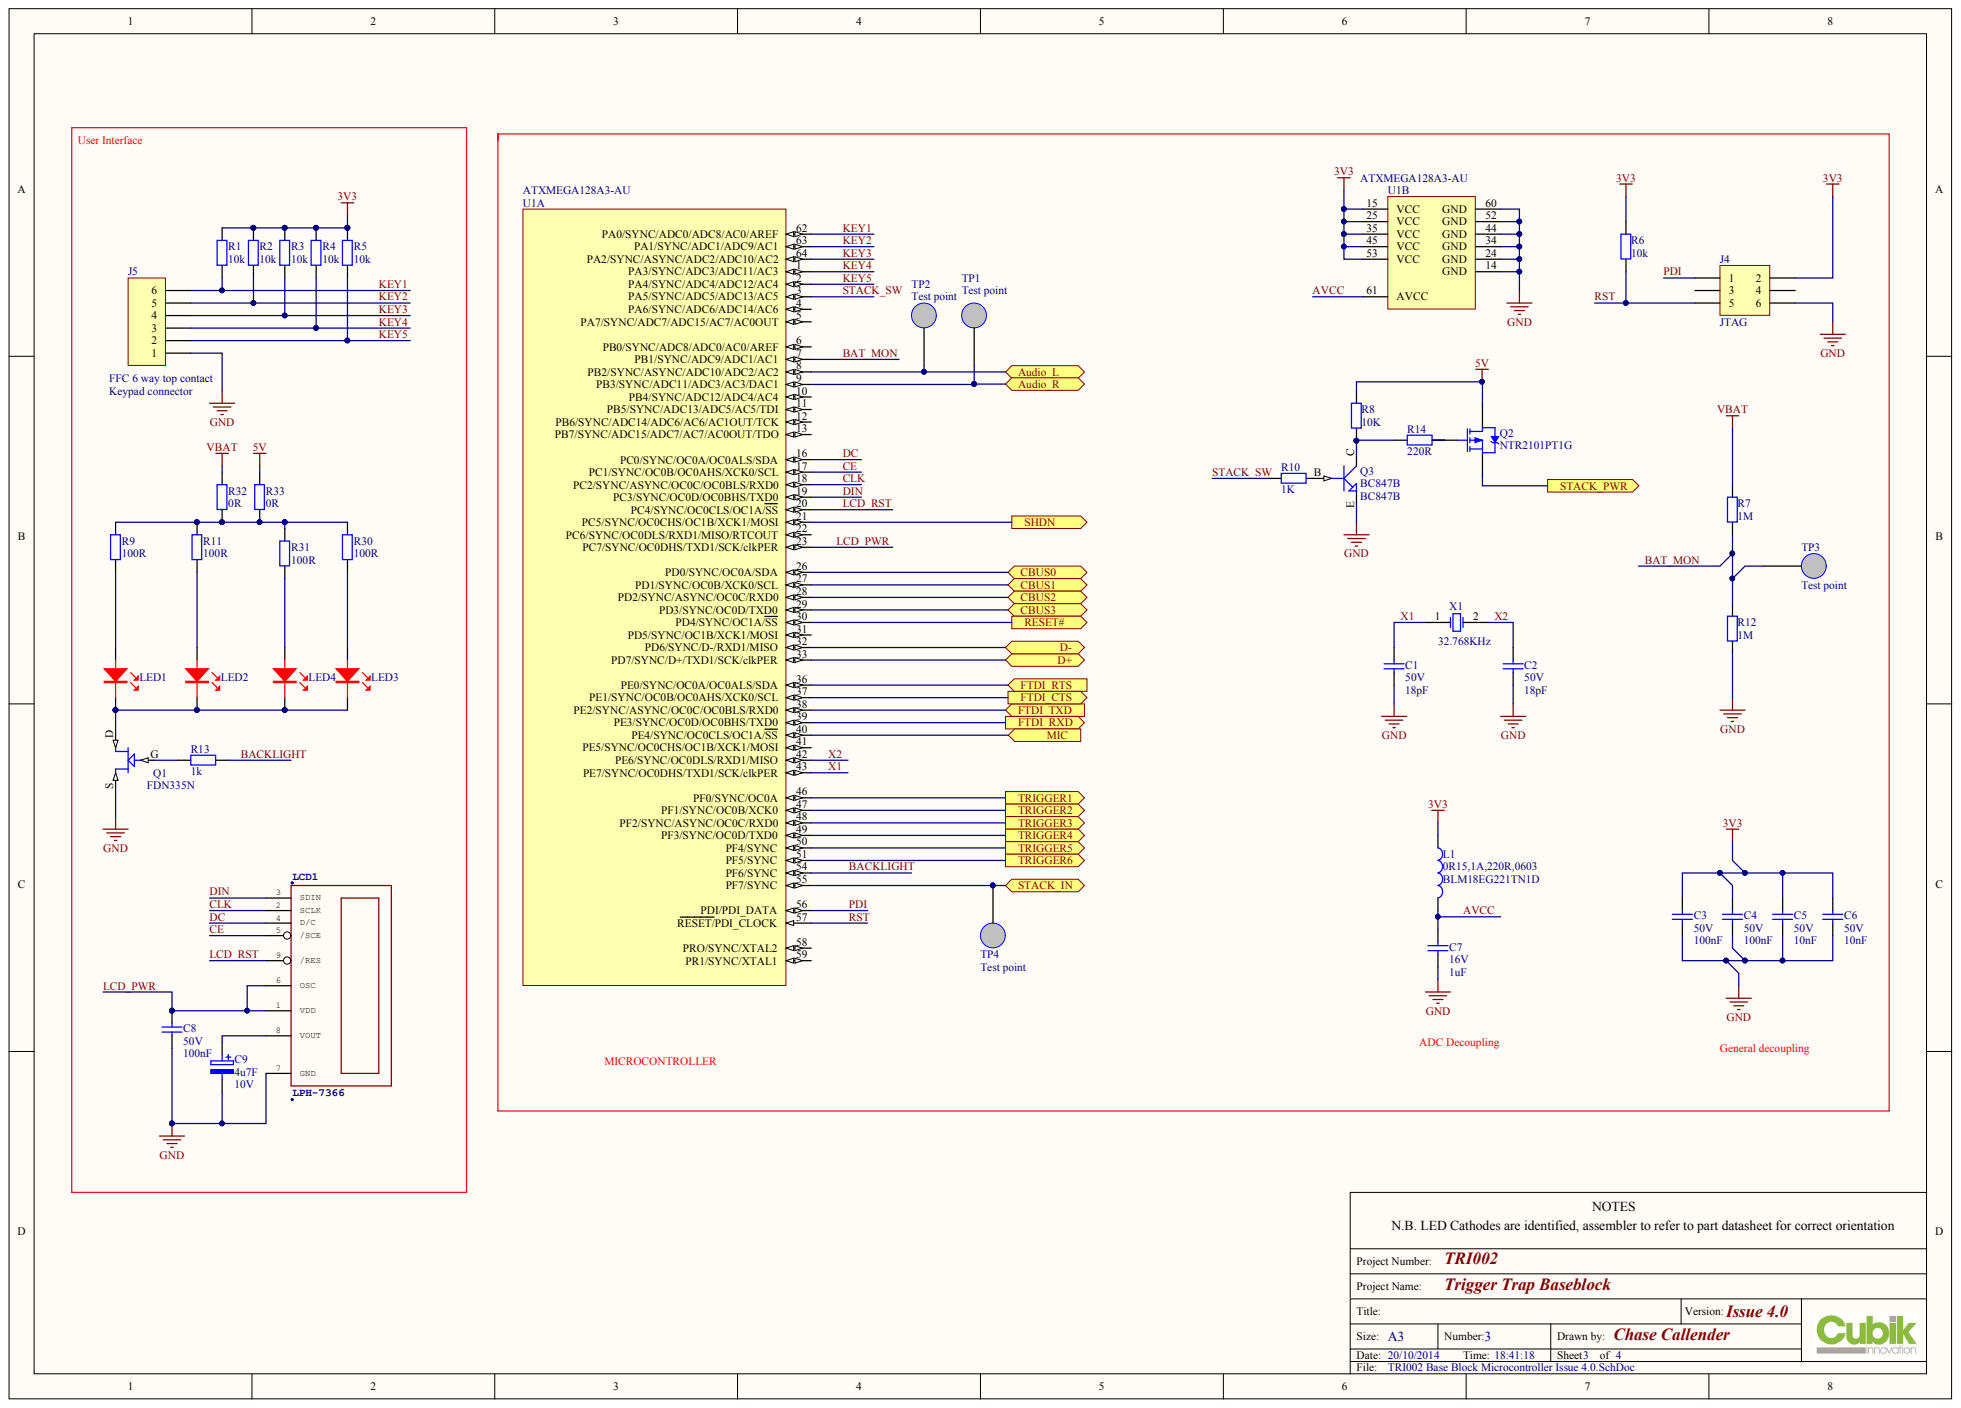
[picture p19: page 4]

FFC 6 way top contact 123456 J5

General decoupling ADC Decoupling

Title: | Issue 4.0 Version:
Size: A | Number: 3 | Chase Callende r

Date: Time: | | Sheet 3 of 4

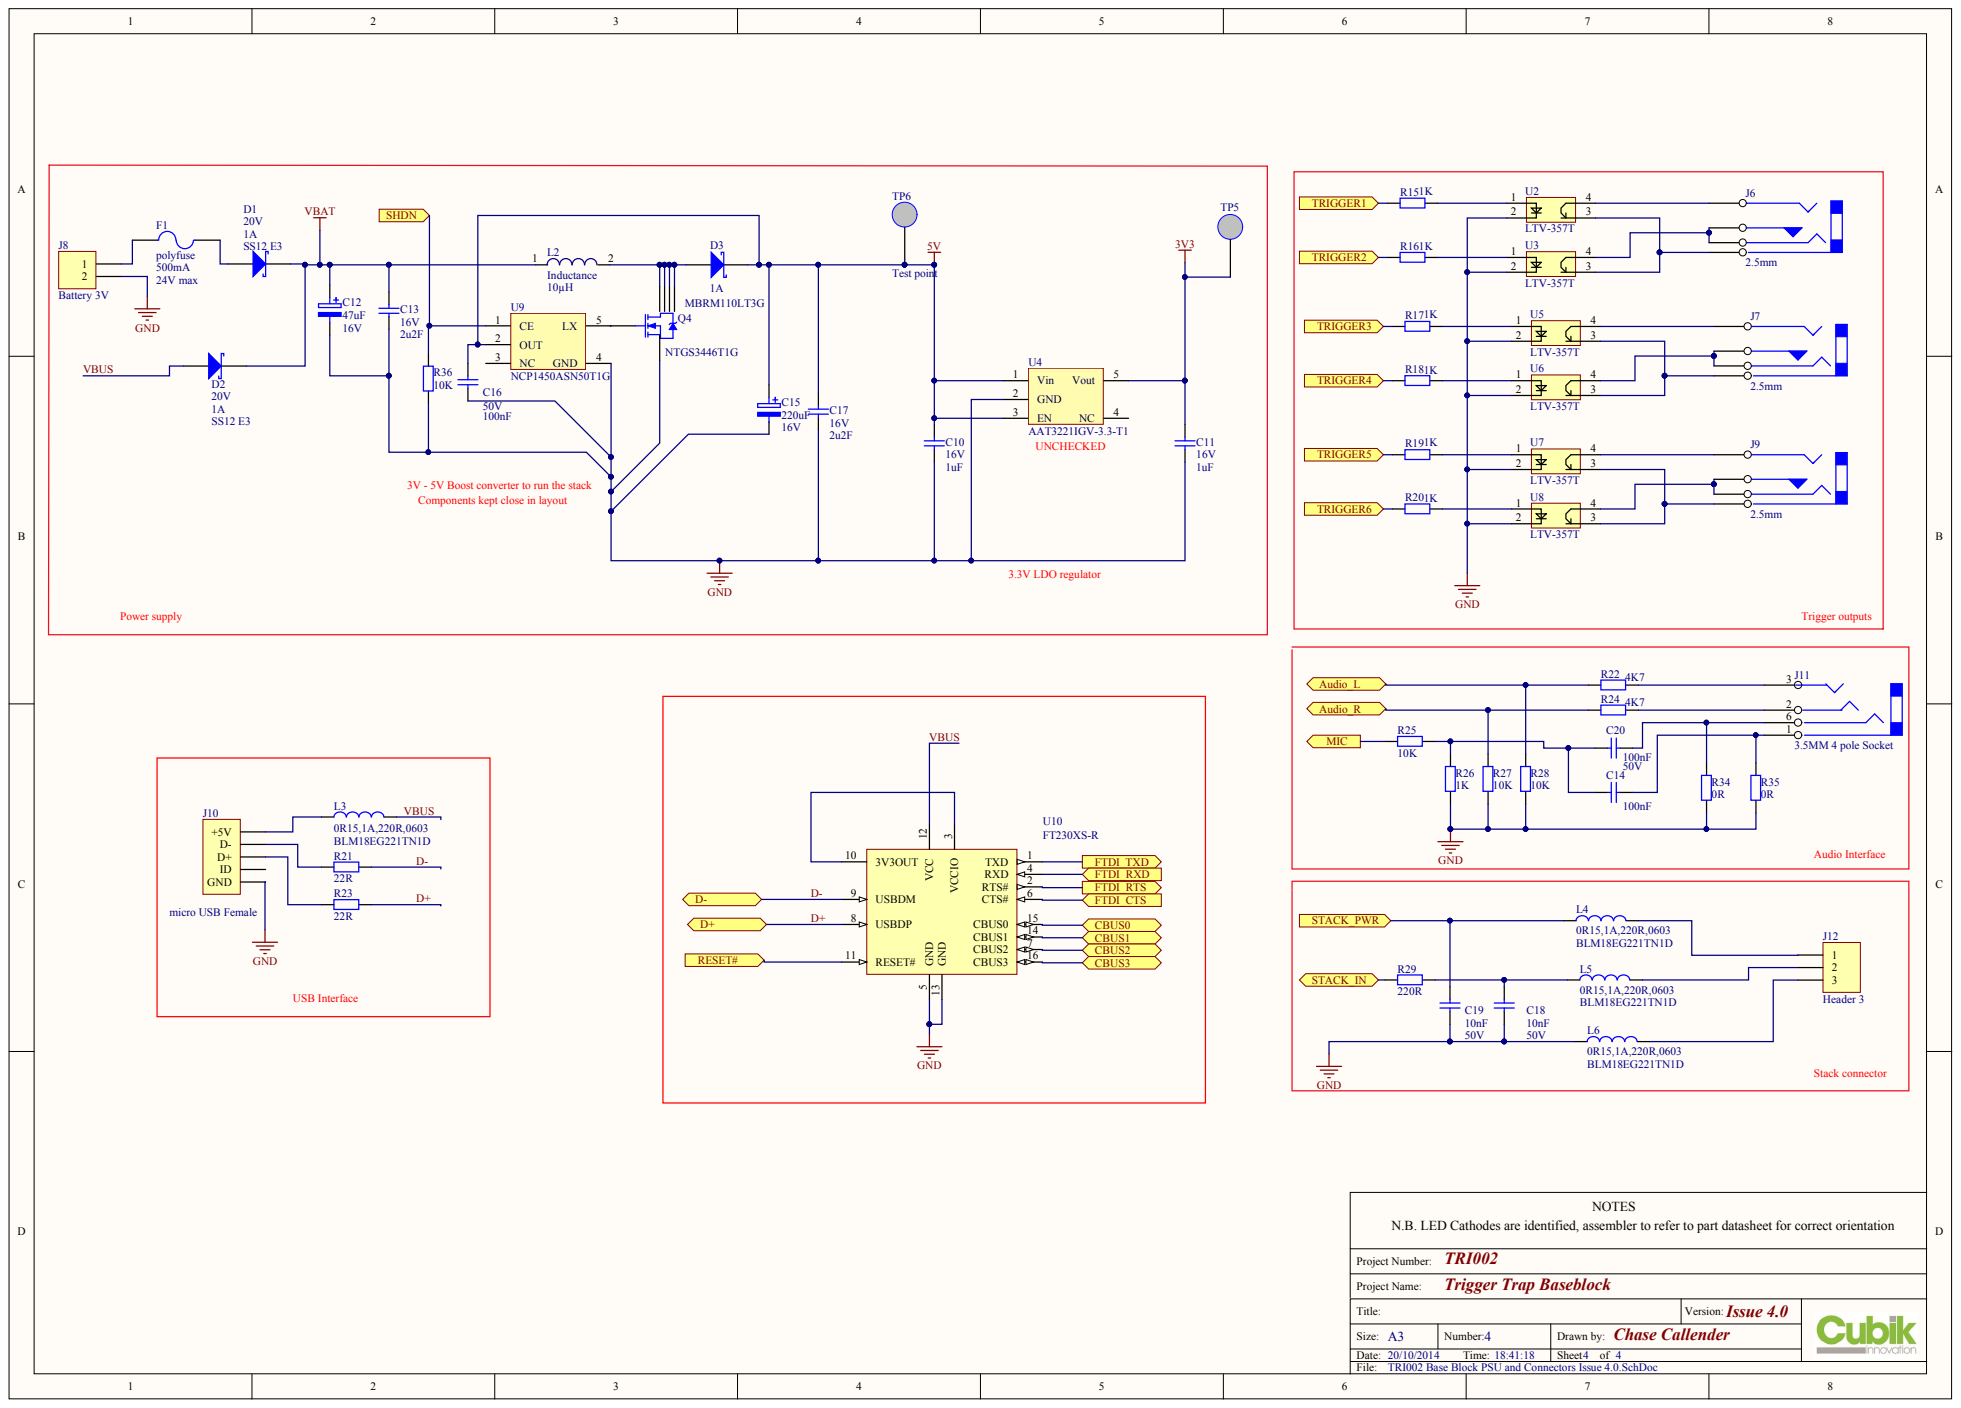
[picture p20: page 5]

3V - 5V Boost converter to run the stack
Components kept close in layout

Audio Interface

N.B. LED Cathodes are identified, assembler to refer to part datasheet for correct orientation

Title: | Issue 4.0 Version:
Size: A3 | Number: 4 | Drawn by: Chase Callender

Date: 20/10/2014 Time: 18:41:18 | | Sheet 4 of 4

TRI002 Base Block PSU and Connectors Issue 4.0.SchDoc

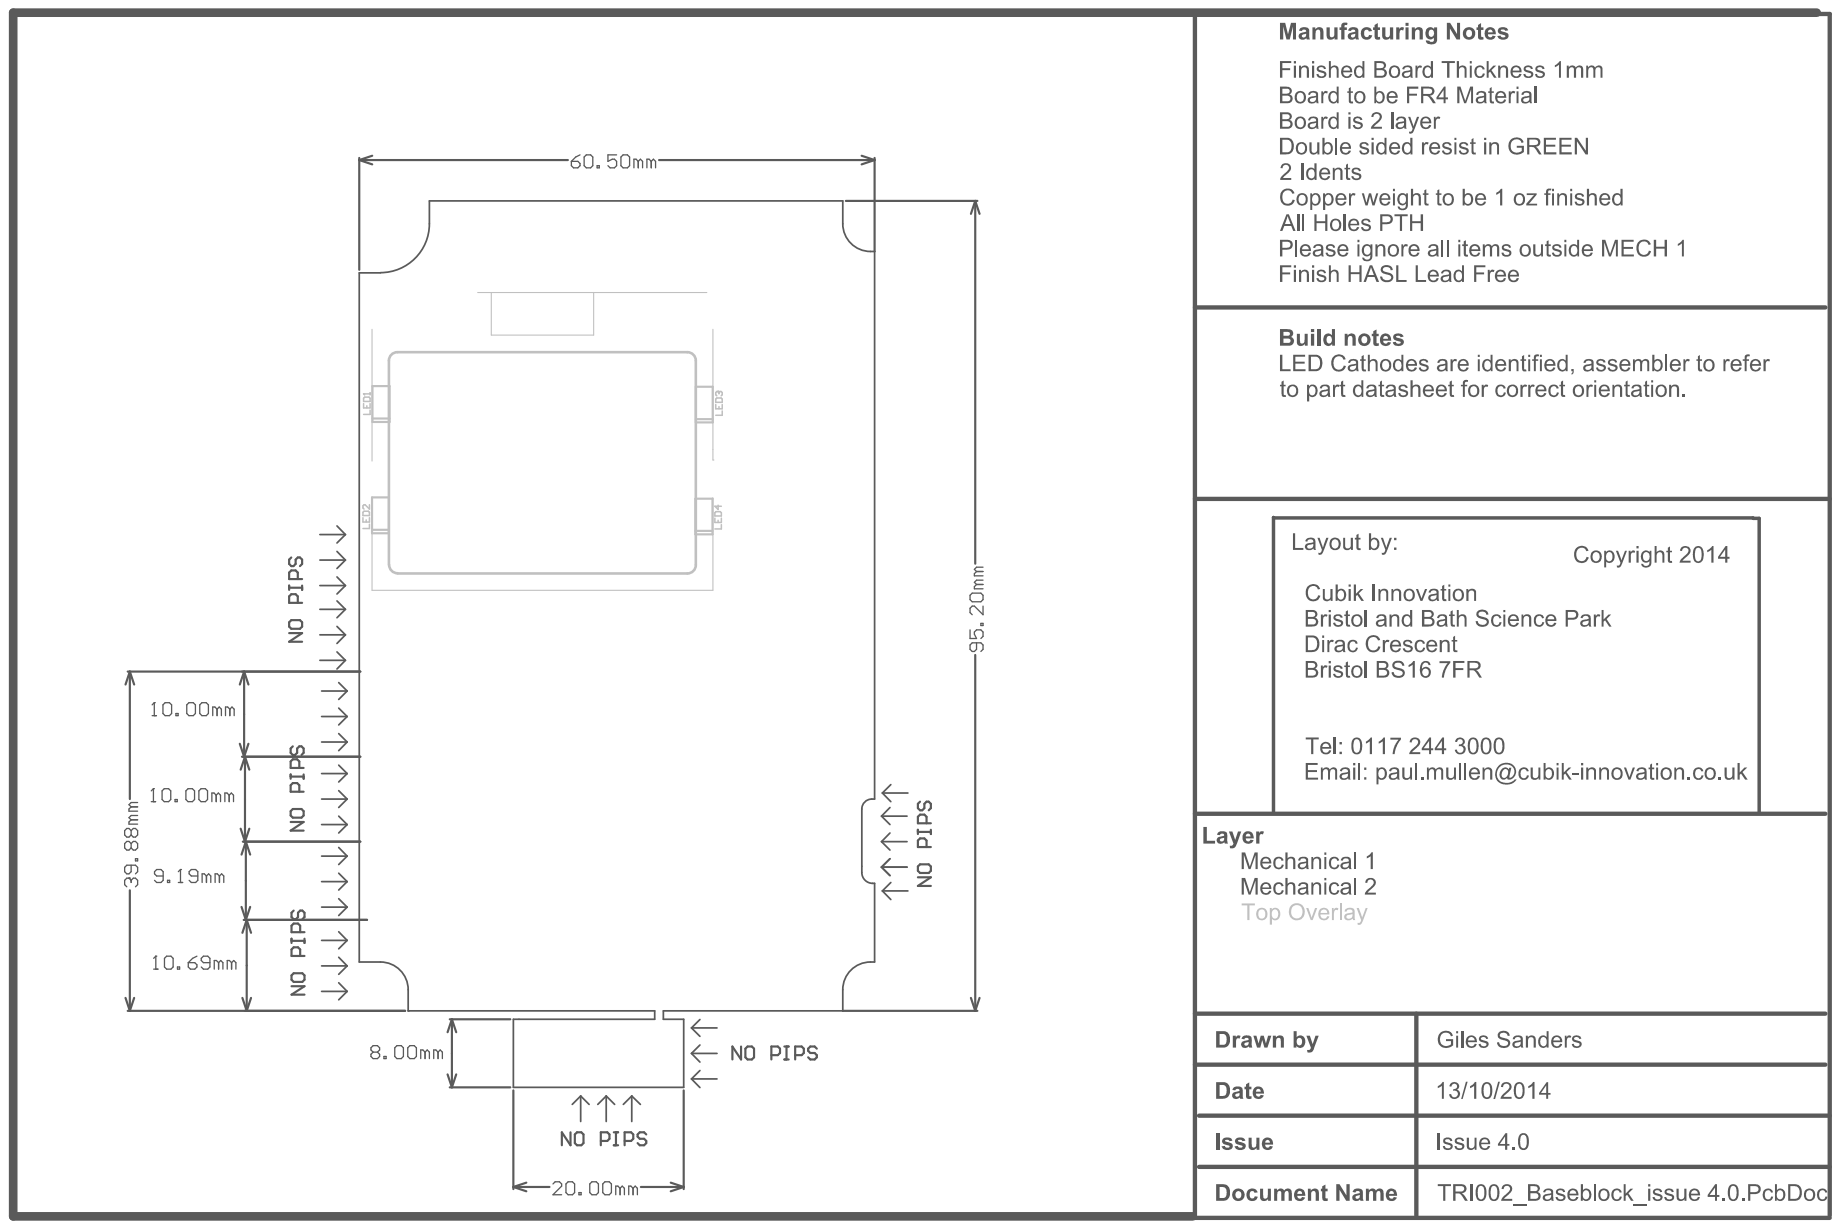
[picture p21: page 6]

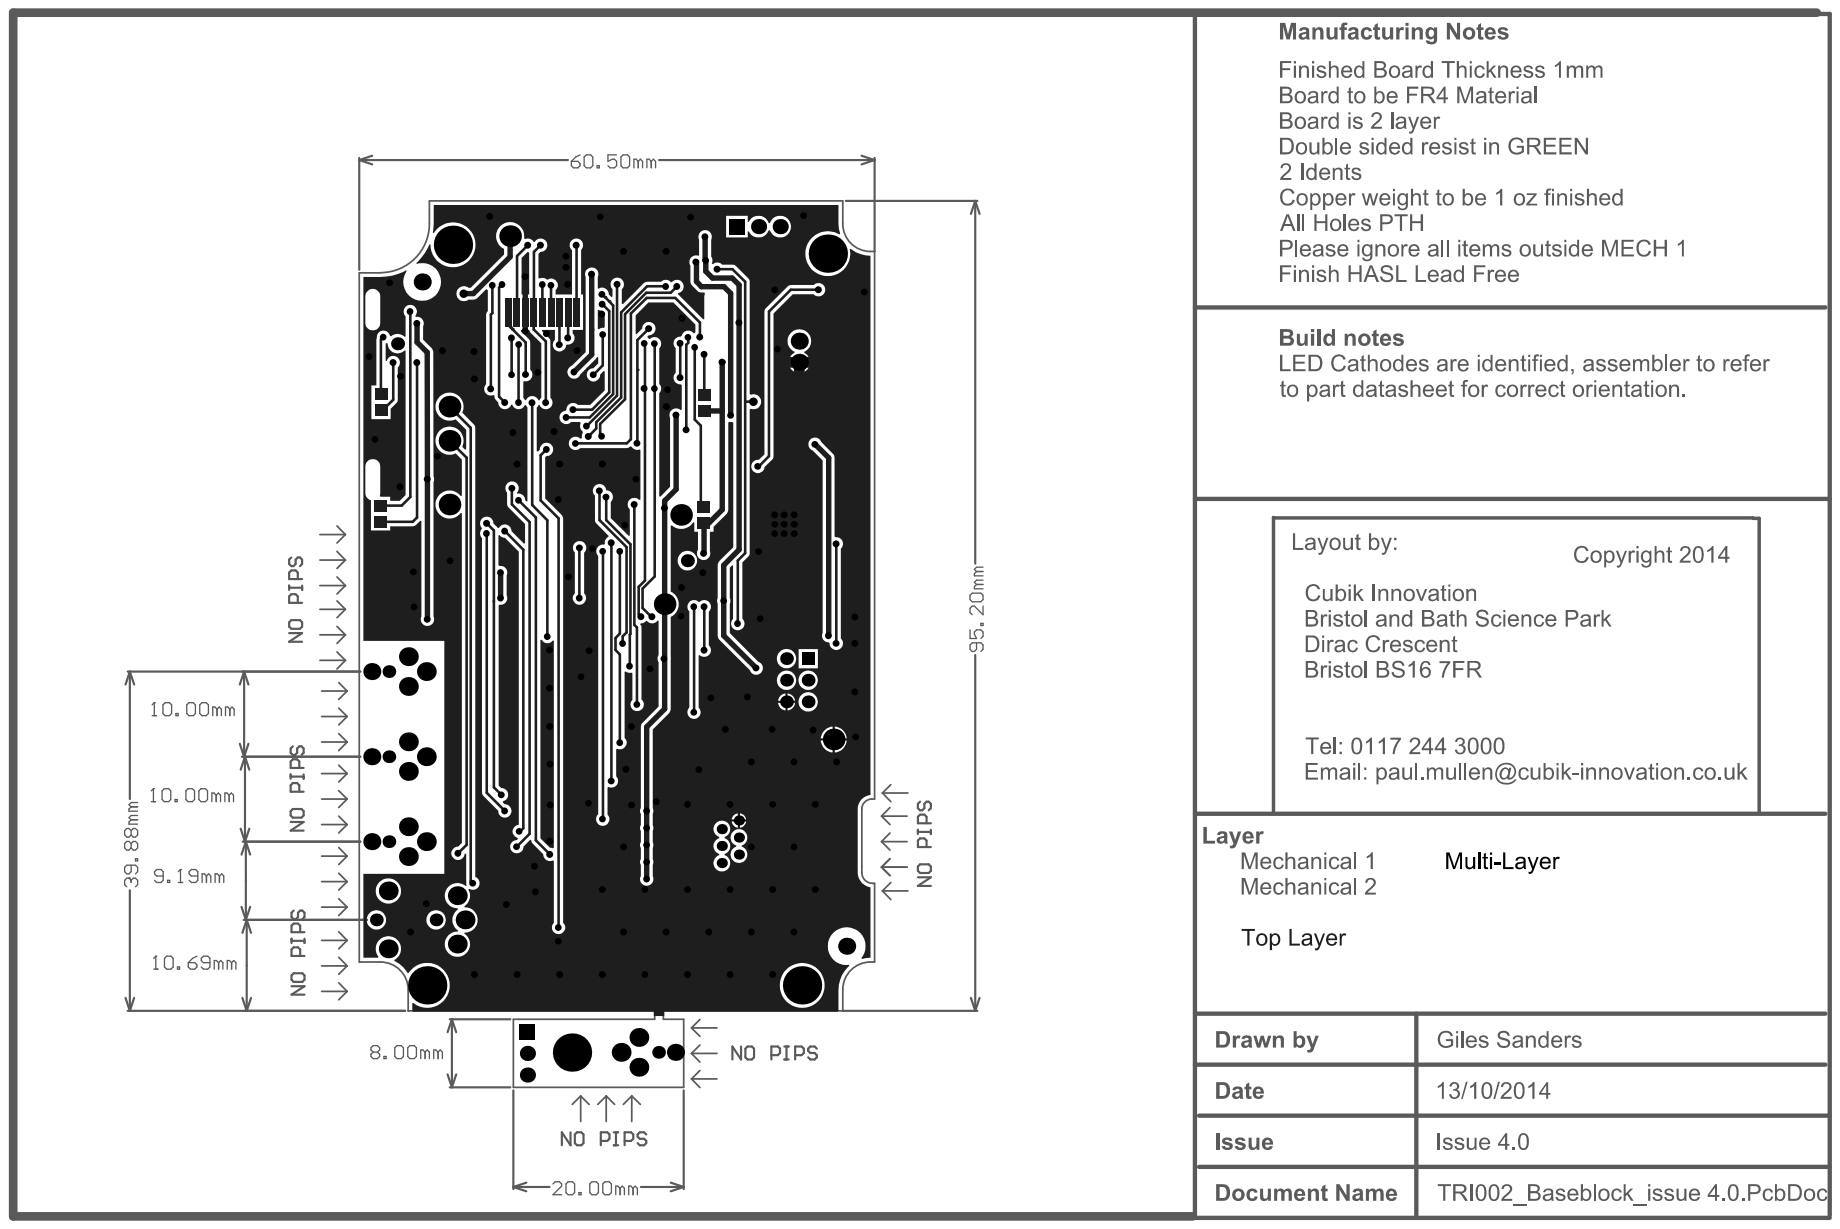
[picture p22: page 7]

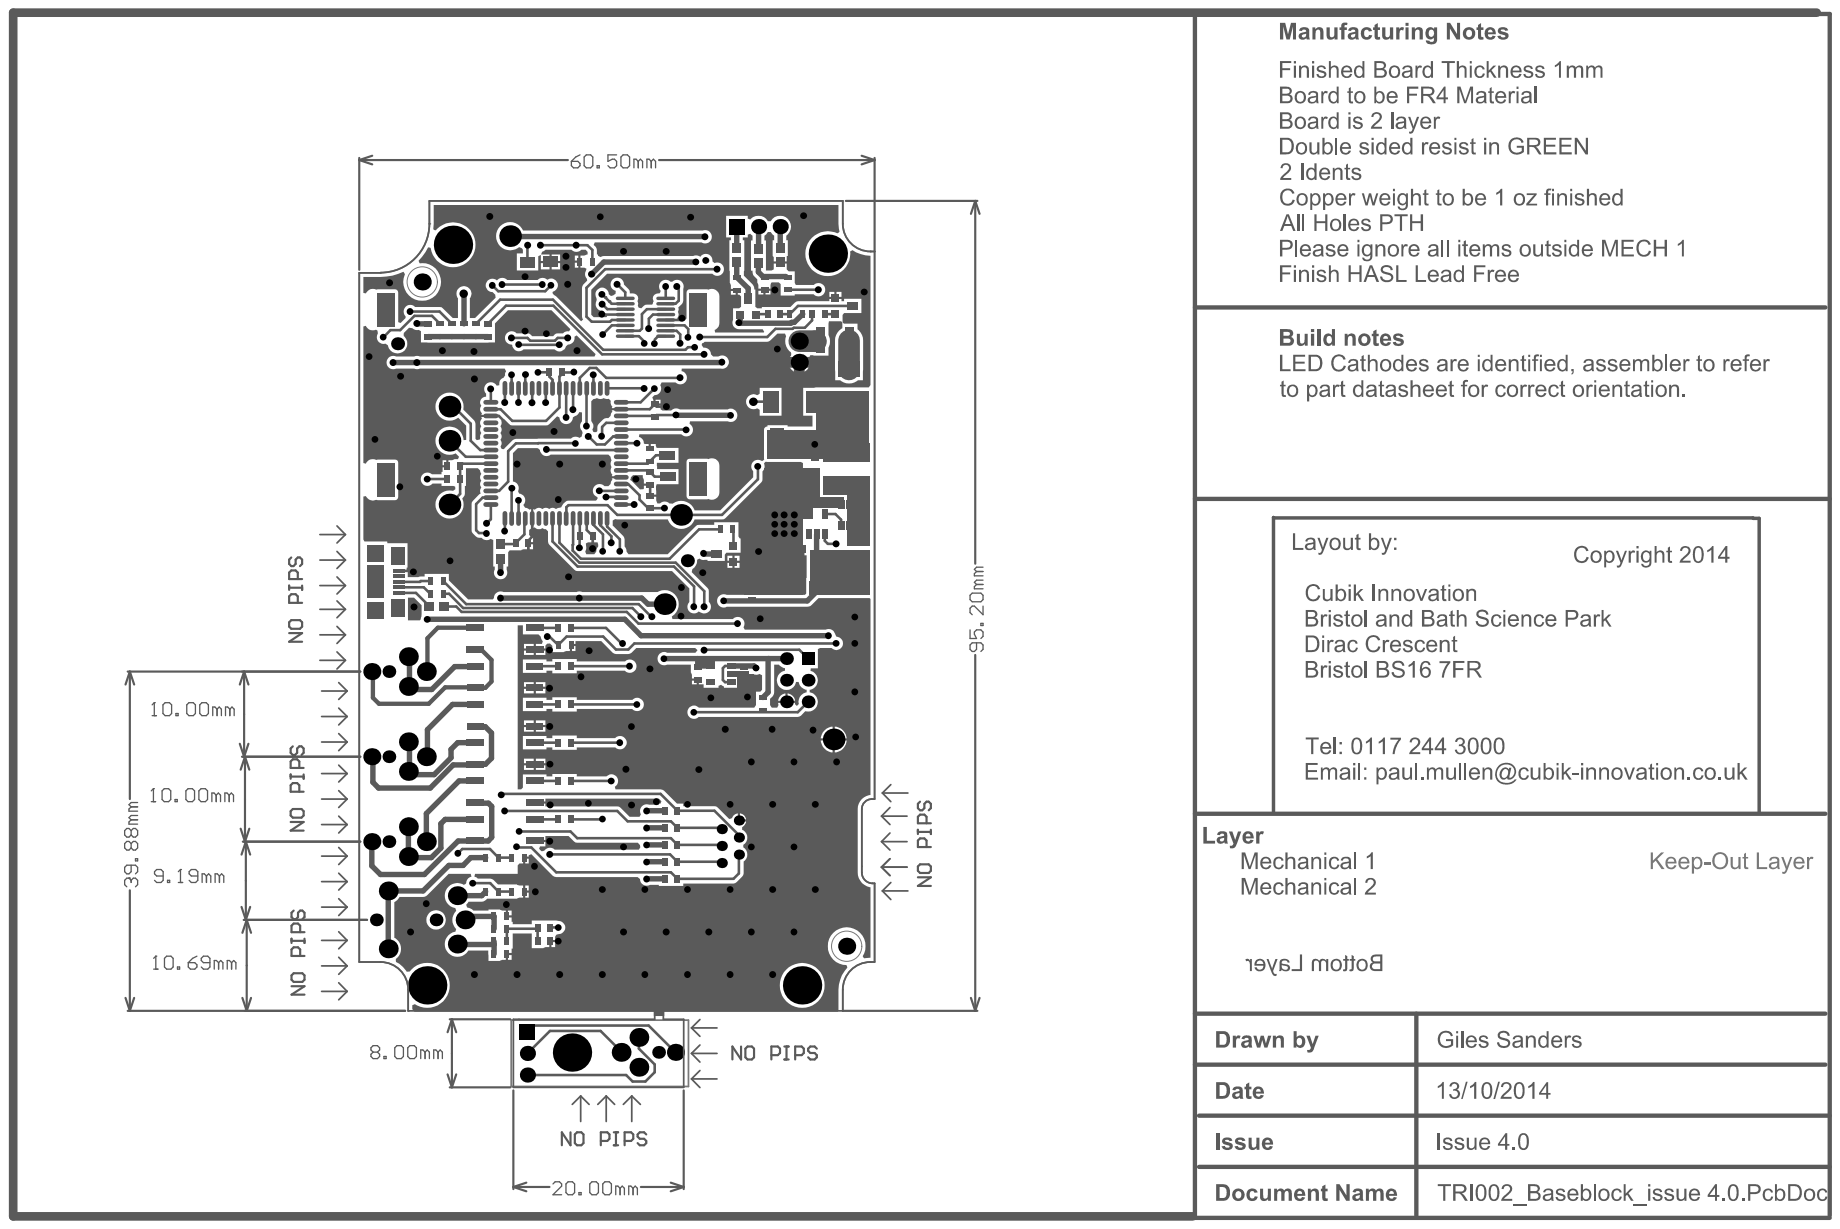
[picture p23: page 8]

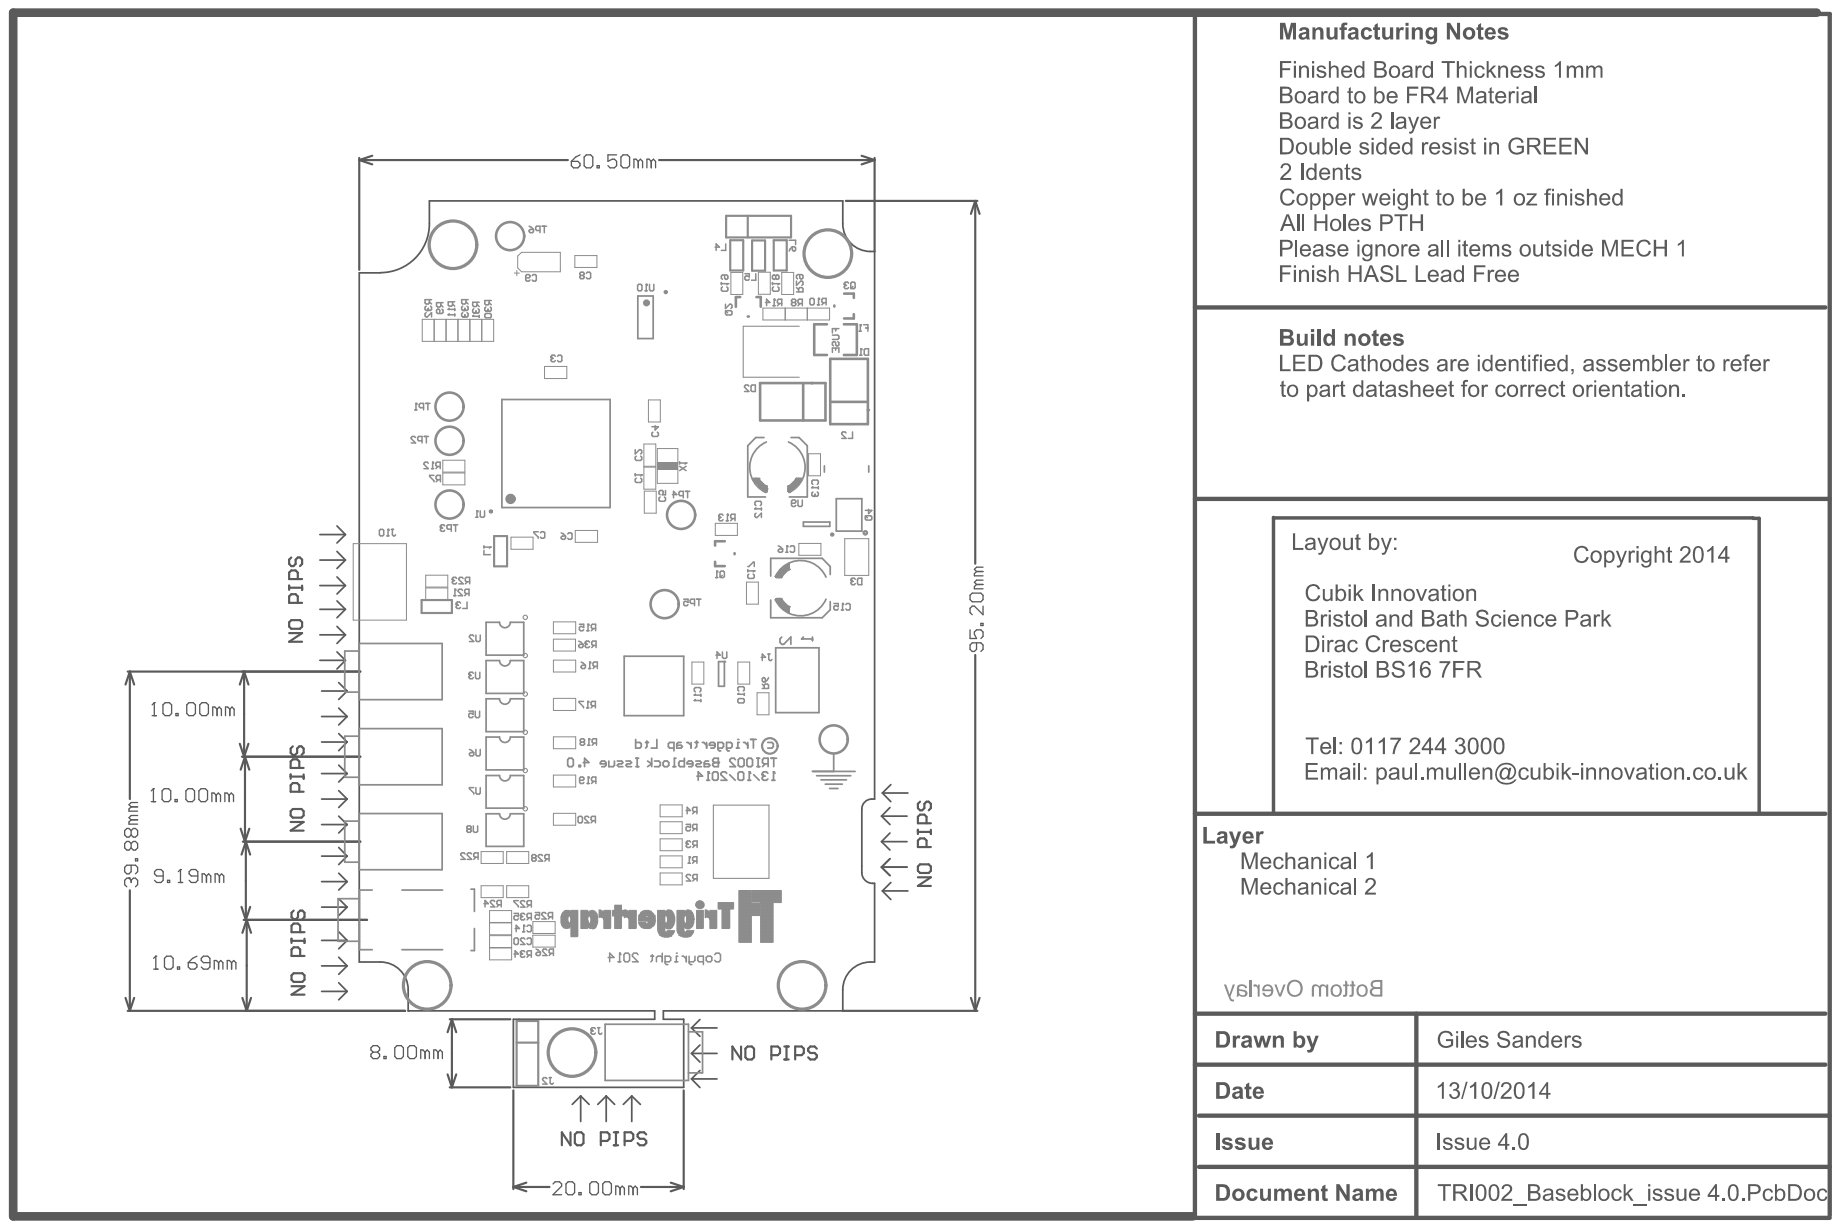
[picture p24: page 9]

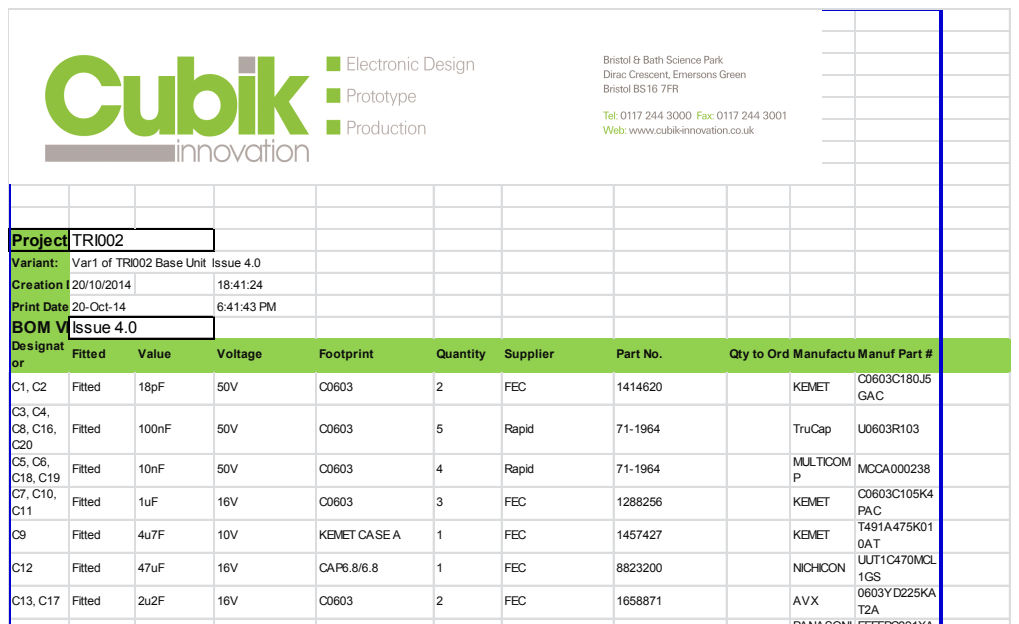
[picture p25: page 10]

Project | TRI002

Variant: Print Date | Var1 of TRI002 Base Unit Issue 4.0

20-Oct-14 | 6:41:43 PM
BOM VER | Issue 4.0
Designat or Fitted Value Voltage Footprint Quantity Supplier Part No. Qty to OrdeM anufactuManuf Part #

C1, C2 | Fitted | 18pF | 50V | C0603 | 2 | FEC | 1414620 | KEMET | C0603C180J5 GAC

C3, C4, C8, C16, C20 | Fitted | 100nF | 50V | C0603 | 5 | Rapid | 71-1964 | TruCap | U0603R103

C5, C6, C18, C19 | Fitted | 10nF | 50V | C0603 | 4 | Rapid | 71-1964 | MULTICOM P | MCCA000238

C7, C10, C11 | Fitted | 1uF | 16V | C0603 | 3 | FEC | 1288256 | KEMET | C0603C105K4 PAC

C9 | Fitted | 4u7F | 10V | KEMET CASE A | 1 | FEC | 1457427 | KEMET | T491A475K01 0AT

C12 | Fitted | 47uF | 16V | CAP6.8/6.8 | 1 | FEC | 8823200 | NICHICON | UUT1C470MCL 1GS

C13, C17 | Fitted | 2u2F | 16V | C0603 | 2 | FEC | 1658871 | AVX | 0603YD225KA T2A

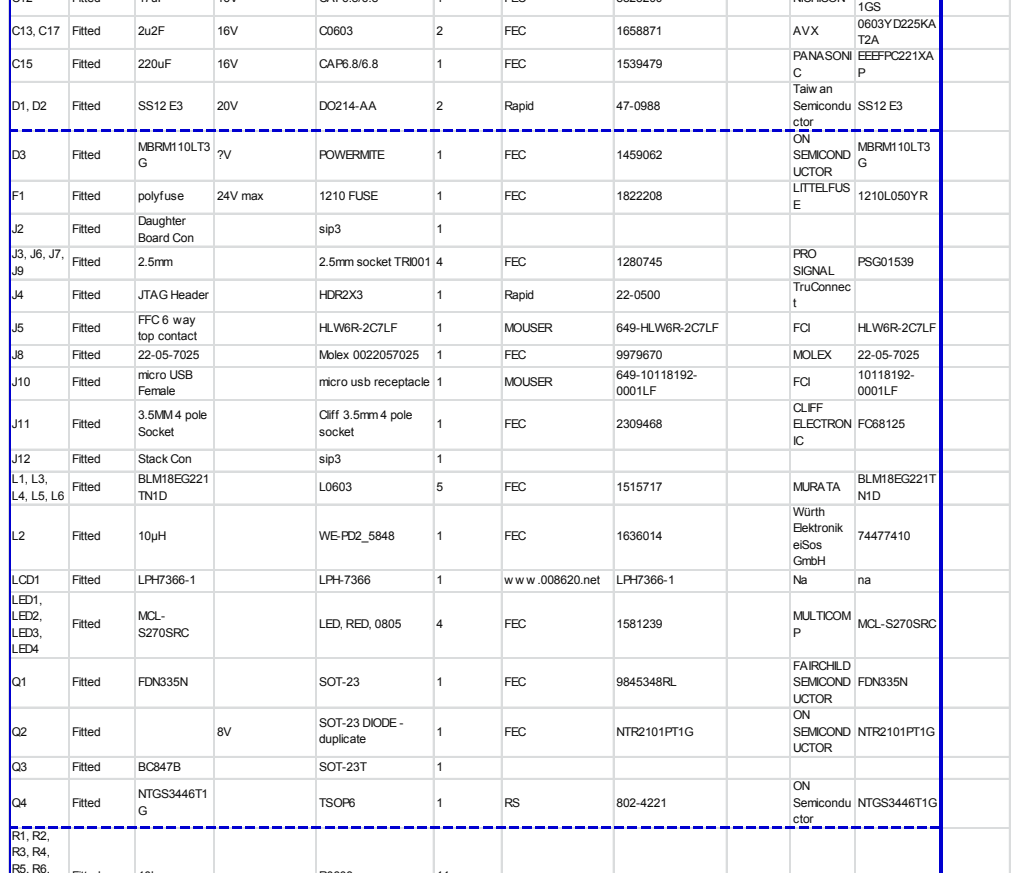
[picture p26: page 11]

C13, C17 | Fitted | 2u2F | 16V | C0603 | 2 | FEC | 1658871 | AVX | 0603YD225KA T2A

C15 | Fitted | 220uF | 16V | CAP6.8/6.8 | 1 | FEC | 1539479 | PANASONI C | EEEFPC221XA P

D1, D2 | Fitted | SS12 E3 | 20V | DO214-AA | 2 | Rapid | 47-0988 | Taiw an Semicondu ctor | SS12 E3

D3 | Fitted | MBRM110LT3 G | ?V | POWERMITE | 1 | FEC | 1459062 | ON SEMICOND UCTOR | MBRM110LT3 G

F1 | Fitted | polyfuse | 24V max | 1210 FUSE | 1 | FEC | 1822208 | LITTELFUS E | 1210L050YR

J2 | Fitted | Daughter Board Con | | sip3 | 1

J3, J6, J7, J9 | Fitted | 2.5mm | | 2.5mm socket TRI001 | 4 | FEC | 1280745 | PRO SIGNAL | PSG01539

J4 | Fitted | JTAG Header | | HDR2X3 | 1 | Rapid | 22-0500 | TruConnec t

J5 | Fitted | FFC 6 way top contact | | HLW6R-2C7LF | 1 | MOUSER | 649-HLW6R-2C7LF | FCI | HLW6R-2C7LF

J8 | Fitted | 22-05-7025 | | Molex 0022057025 | 1 | FEC | 9979670 | MOLEX | 22-05-7025
J10 | Fitted | micro USB Female | | micro usb receptacle | 1 | MOUSER | 649-10118192-0001LF | FCI | 10118192-0001LF

J11 | Fitted | 3.5MM 4 pole Socket | | Cliff 3.5mm 4 pole socket | 1 | FEC | 2309468 | CLIFF ELECTRON IC | FC68125

J12 | Fitted | Stack Con | | sip3 | 1
L1, L3, L4, L5, L6 | Fitted | BLM18EG221 TN1D | | L0603 | 5 | FEC | 1515717 | MURATA | BLM18EG221T N1D

L2 | Fitted | 10µH | | WE-PD2_5848 | 1 | FEC | 1636014 | Würth Elektronik eiSos GmbH | 74477410

LCD1 | Fitted | LPH7366-1 | | LPH-7366 | 1 | w w w .008620.net | LPH7366-1 | Na | na
LED1, LED2, LED3, LED4 | Fitted | MCL-S270SRC | | LED, RED, 0805 | 4 | FEC | 1581239 | MULTICOM P | MCL-S270SRC

Q1 | Fitted | FDN335N | | SOT-23 | 1 | FEC | 9845348RL | FAIRCHILD SEMICOND UCTOR | FDN335N

Q2 | Fitted | | 8V | SOT-23 DIODE -duplicate | 1 | FEC | NTR2101PT1G | ON SEMICOND UCTOR | NTR2101PT1G

Q3 | Fitted | BC847B | | SOT-23T | 1
Q4 | Fitted | NTGS3446T1 G | | TSOP6 | 1 | RS | 802-4221 | ON Semicondu ctor | NTGS3446T1G

## ctor

R1, R2, R3, R4, R5, R6, R8, R25, R27, R28, R36 | Fitted | 10k | | R0603 | 11
R7, R12 | Fitted | 1M | | R0603 | 2
R9, R11, R30, R31 | Fitted | 100R | | R0603 | 4
R10, R13, R15, R16, R17, R18, R19, R20, R26 | Fitted | 1K | | R0603 | 9
R14, R29 | Fitted | 220R | | R0603 | 2
R21, R23 | Fitted | 22R | | R0603 | 2
R22, R24 | Fitted | 4K7 | | R0603 | 2
R32, R35 | Fitted | 0R | | R0603 | 2
U1 | Fitted | ATXMEGA12 8A3-AU | | 64A_N | 1 | FEC | 1748550 | ATMEL | ATXMEGA128 A3-AU
U2, U3, U5, U6, U7, U8 | Fitted | LTV-357T | | SMD-4 | 6 | MOUSER | 859-LTV-357T | Lite-on | LTV-357T
U4 | Fitted | AAT3221IGV-3.3-T1 | | TSOT 5 pin | 1 | MOUSER | 873-AAT3221IGV-33T1 | Skyw orks Solutions | AAT3221IGV-3.3-T1
U9 | Fitted | NCP1450ASN 50T1G | | SOT23-5AN | 1 | FEC | 1460676 | ON SEMICOND UCTOR | NCP1450ASN5 0T1G
U10 | Fitted | FT230X | | SSOP-16_N | 1 | MOUSER | 895-FT230XS-R | FTDI | FT230XS-R
X1 | Fitted | 32.768KHz | | FC 13F | 1 | FEC | 1712821 | EPSON TOYOCOM | FC-13F,32.768KH Z, 12.5PF
C14 | Not Fitted | 100nF | 50V | C0603 | 0 | Rapid | 71-1964 | TruCap | U0603R103
R33, R34 | Not Fitted | 0R | | R0603 | 0

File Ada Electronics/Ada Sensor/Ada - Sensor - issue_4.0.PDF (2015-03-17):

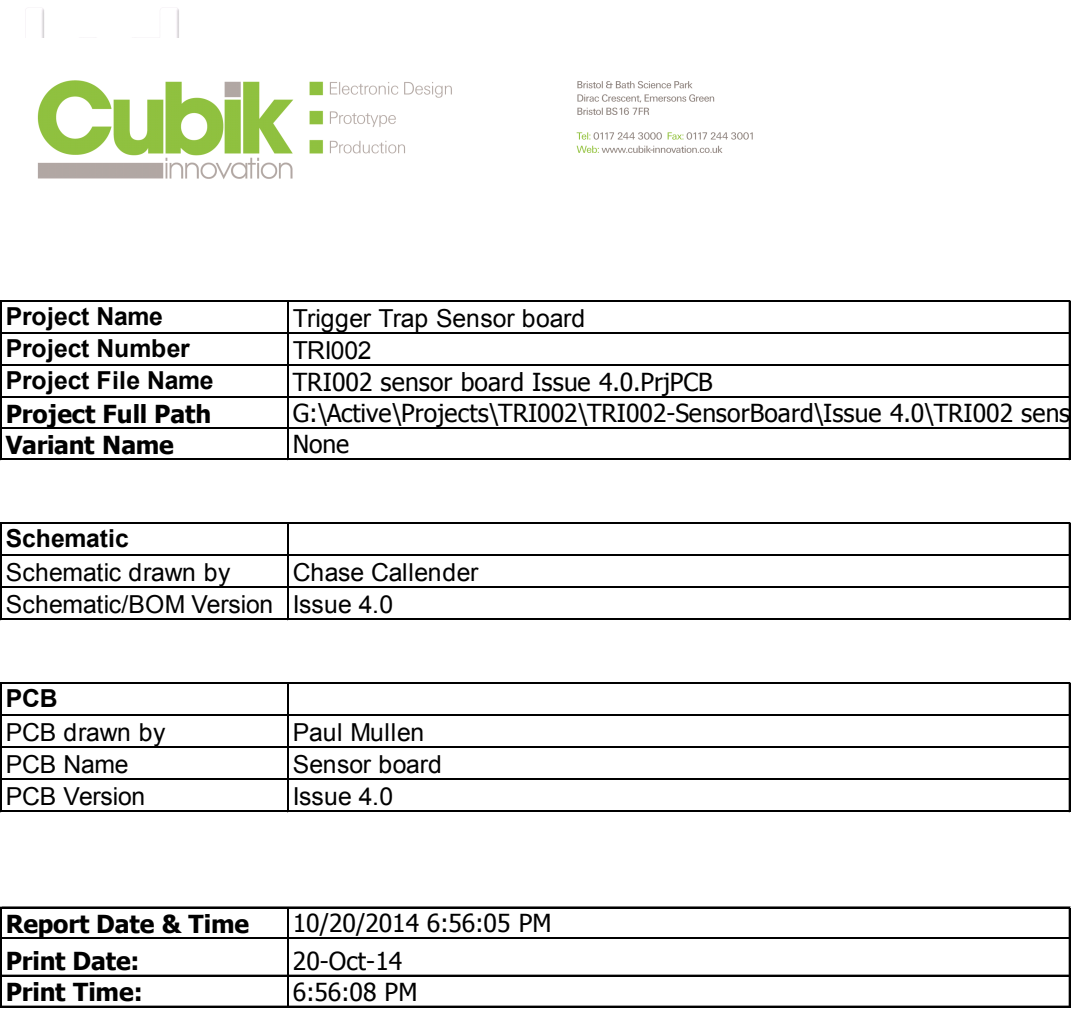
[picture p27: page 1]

Project Name | Trigger Trap Sensor board
Project Number | TRI002
Project File Name | TRI002 sensor board Issue 4.0.PrjPCB
Project Full Path | G:\Active\Projects\TRI002\TRI002-SensorBoard\Issue 4.0\TRI002 sens
Variant Name | None

Schematic
Schematic drawn by | Chase Callender
Schematic/BOM Version | Issue 4.0

PCB
PCB drawn by | Paul Mullen
PCB Name | Sensor board
PCB Version | Issue 4.0

Report Date & Time | 10/20/2014 6:56:05 PM
Print Date: | 20-Oct-14
Print Time: | 6:56:08 PM

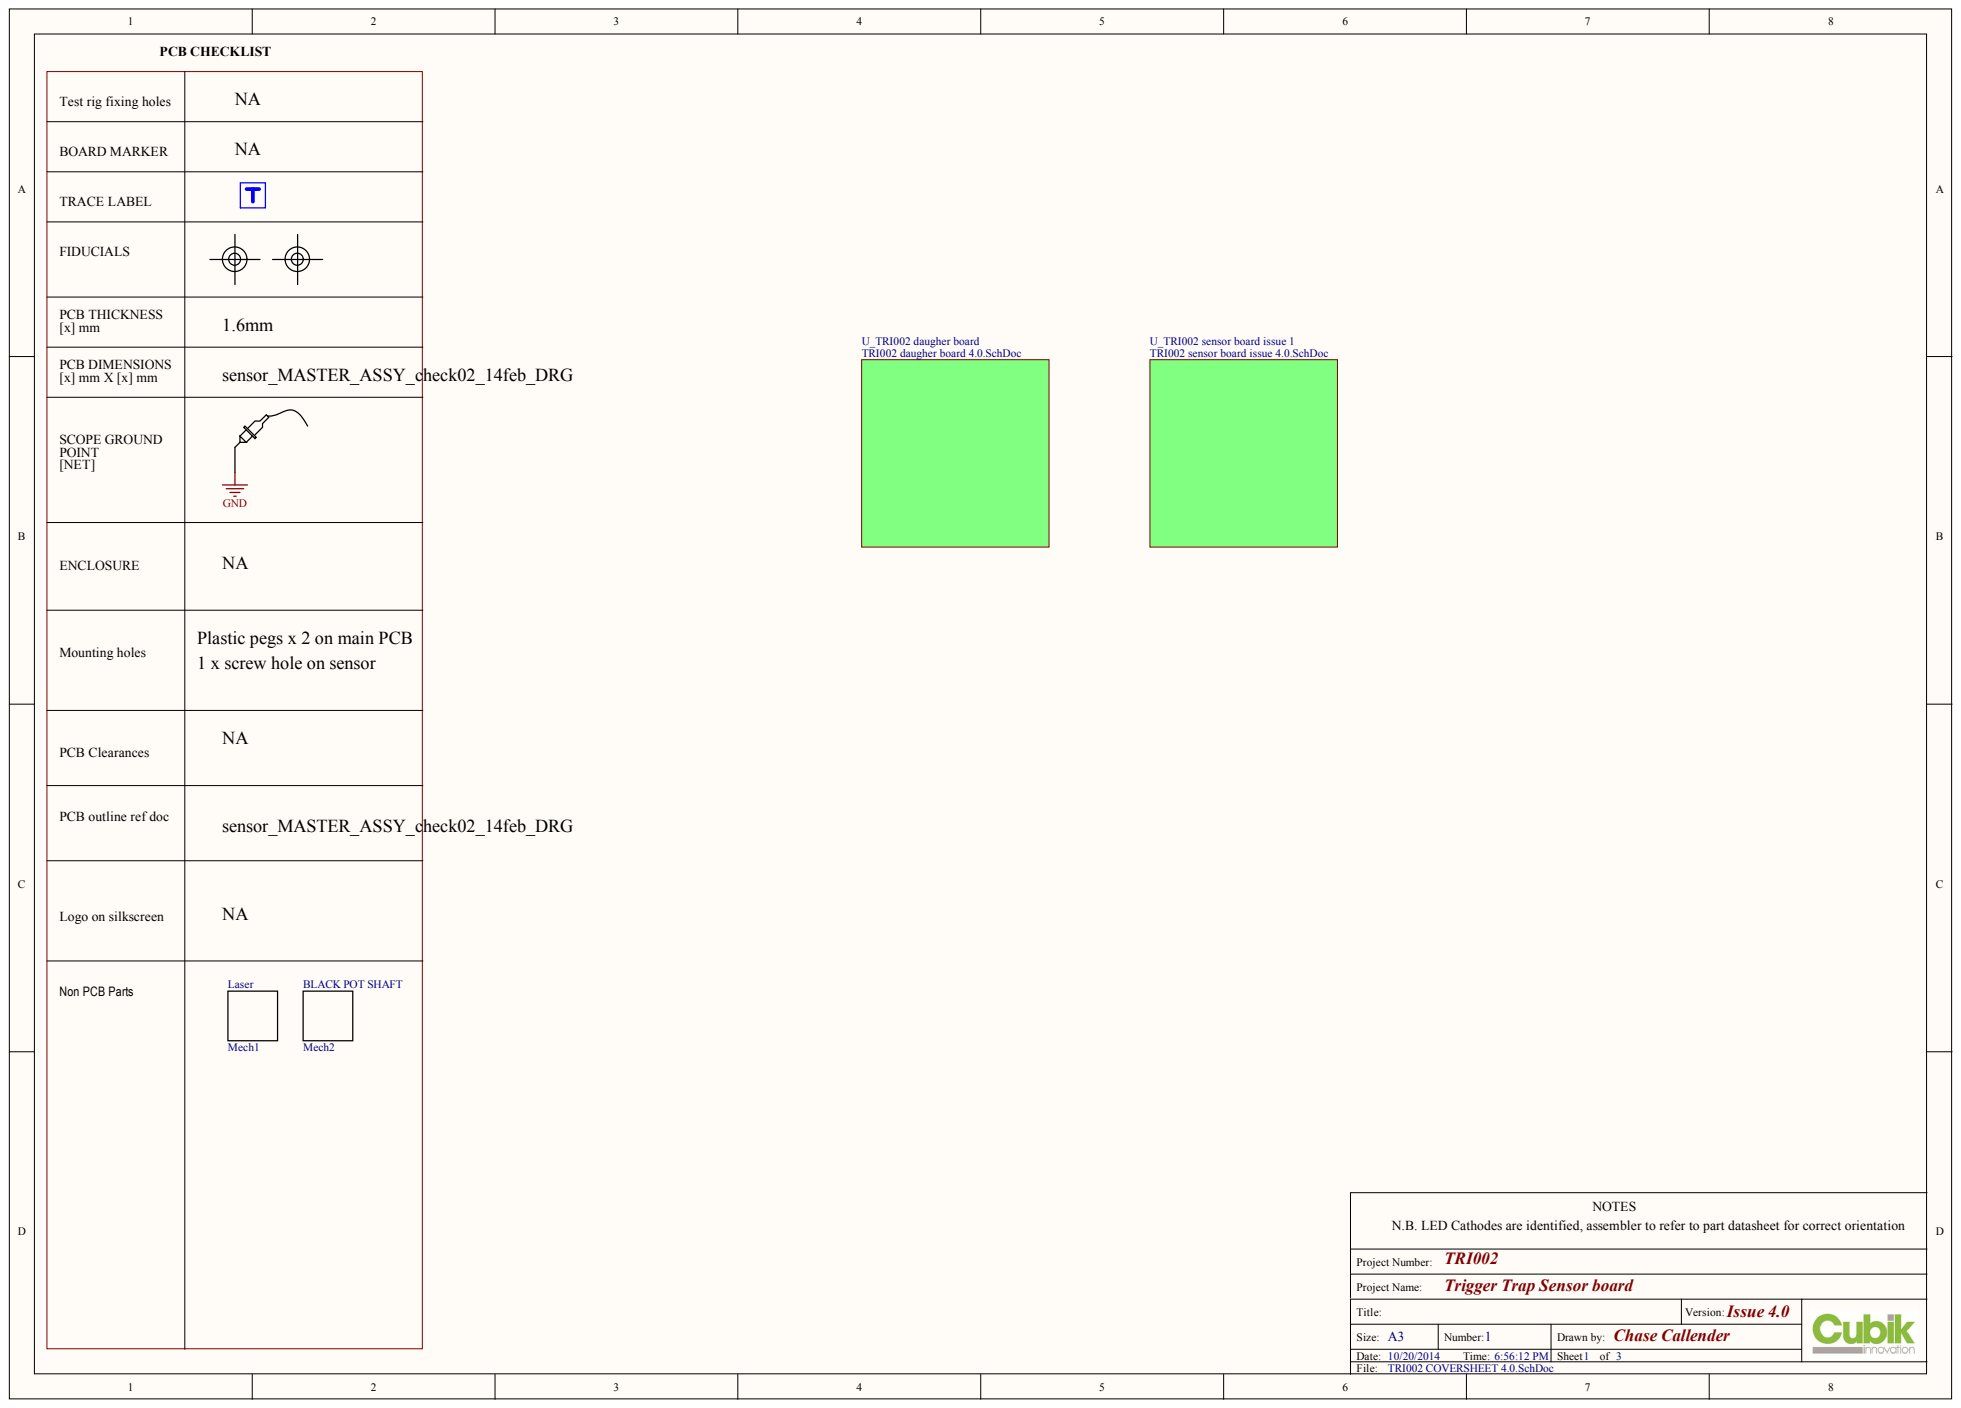
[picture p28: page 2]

Test rig fixing holes | NA

BOARD MARKER | NA

TRACE LABEL

FIDUCIALS

PCB THICKNESS [x] mm | 1.6mm

U_TRI002 sensor board issue 1
TRI002 sensor board issue 4.0.SchDoc

PCB DIMENSIONS [x] mm X [x] mm

SCOPE GROUND POINT [NET]

ENCLOSURE | NA

Mounting holes | Plastic pegs x 2 on main PCB 1 x screw hole on sensor

PCB Clearances | NA

PCB outline ref doc

Logo on silkscreen | NA

BLACK POT SHAFT

N.B. LED Cathodes are identified, assembler to refer to part datasheet for correct orientation

Trigger Trap Sensor board

Title: | Issue 4.0 Version:
Size: A3 | Number: 1 | Drawn by: Chase Callender

Date: 10/20/2014 Time: 6:56:12 PM | | Sheet 1 of 3

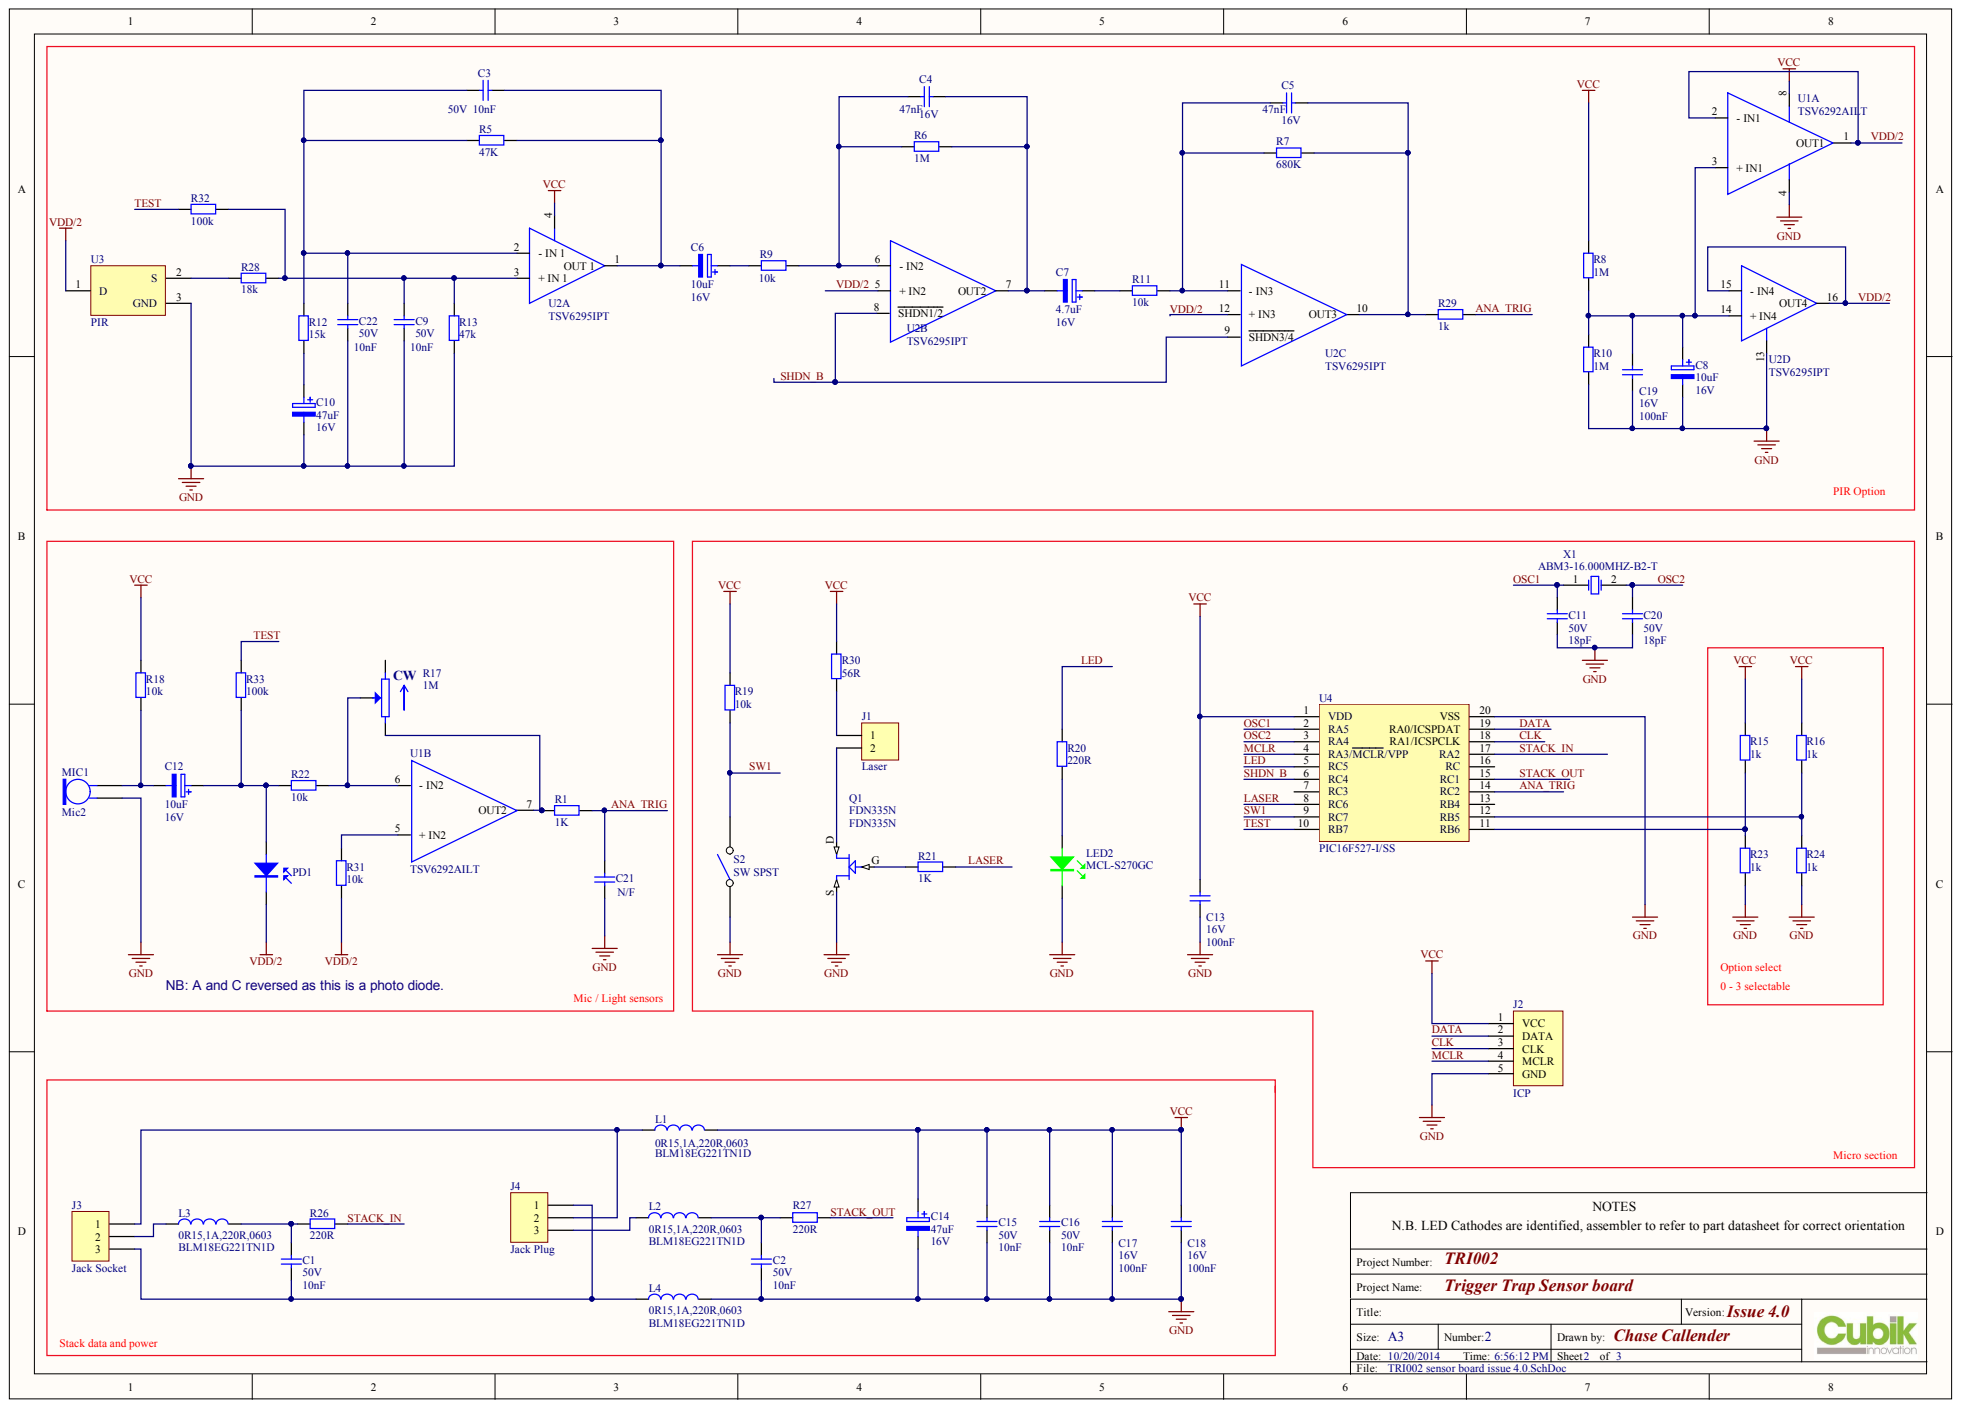
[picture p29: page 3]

GND
NB: A and C reversed as this is a photo diode.

N.B. LED Cathodes are identified, assembler to refer to part datasheet for correct orientation

Trigger Trap Sensor board

Date:
TRI002 sensor board issue 4.0.SchDoc

Stack data and power

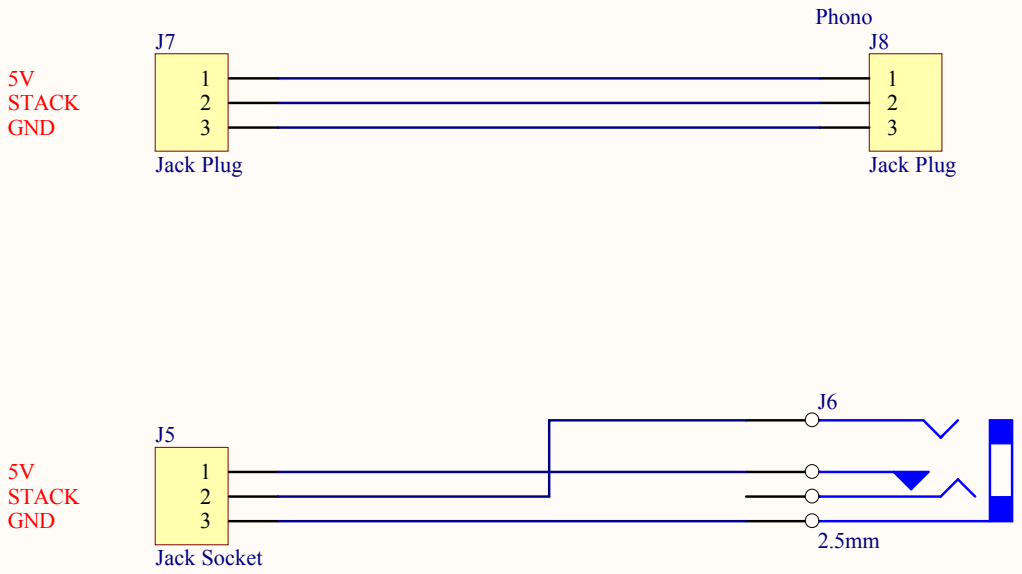
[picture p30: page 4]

N.B. LED Cathodes are identified, assembler to refer to part datasheet for correct orientation

Trigger Trap Sensor board

Title: | Issue 4.0 Version:
Size: A3 | Number: 3 | Drawn by: Chase Callender

Date: 10/20/2014 Time: 6:56:12 PM | | Sheet 3 of 3

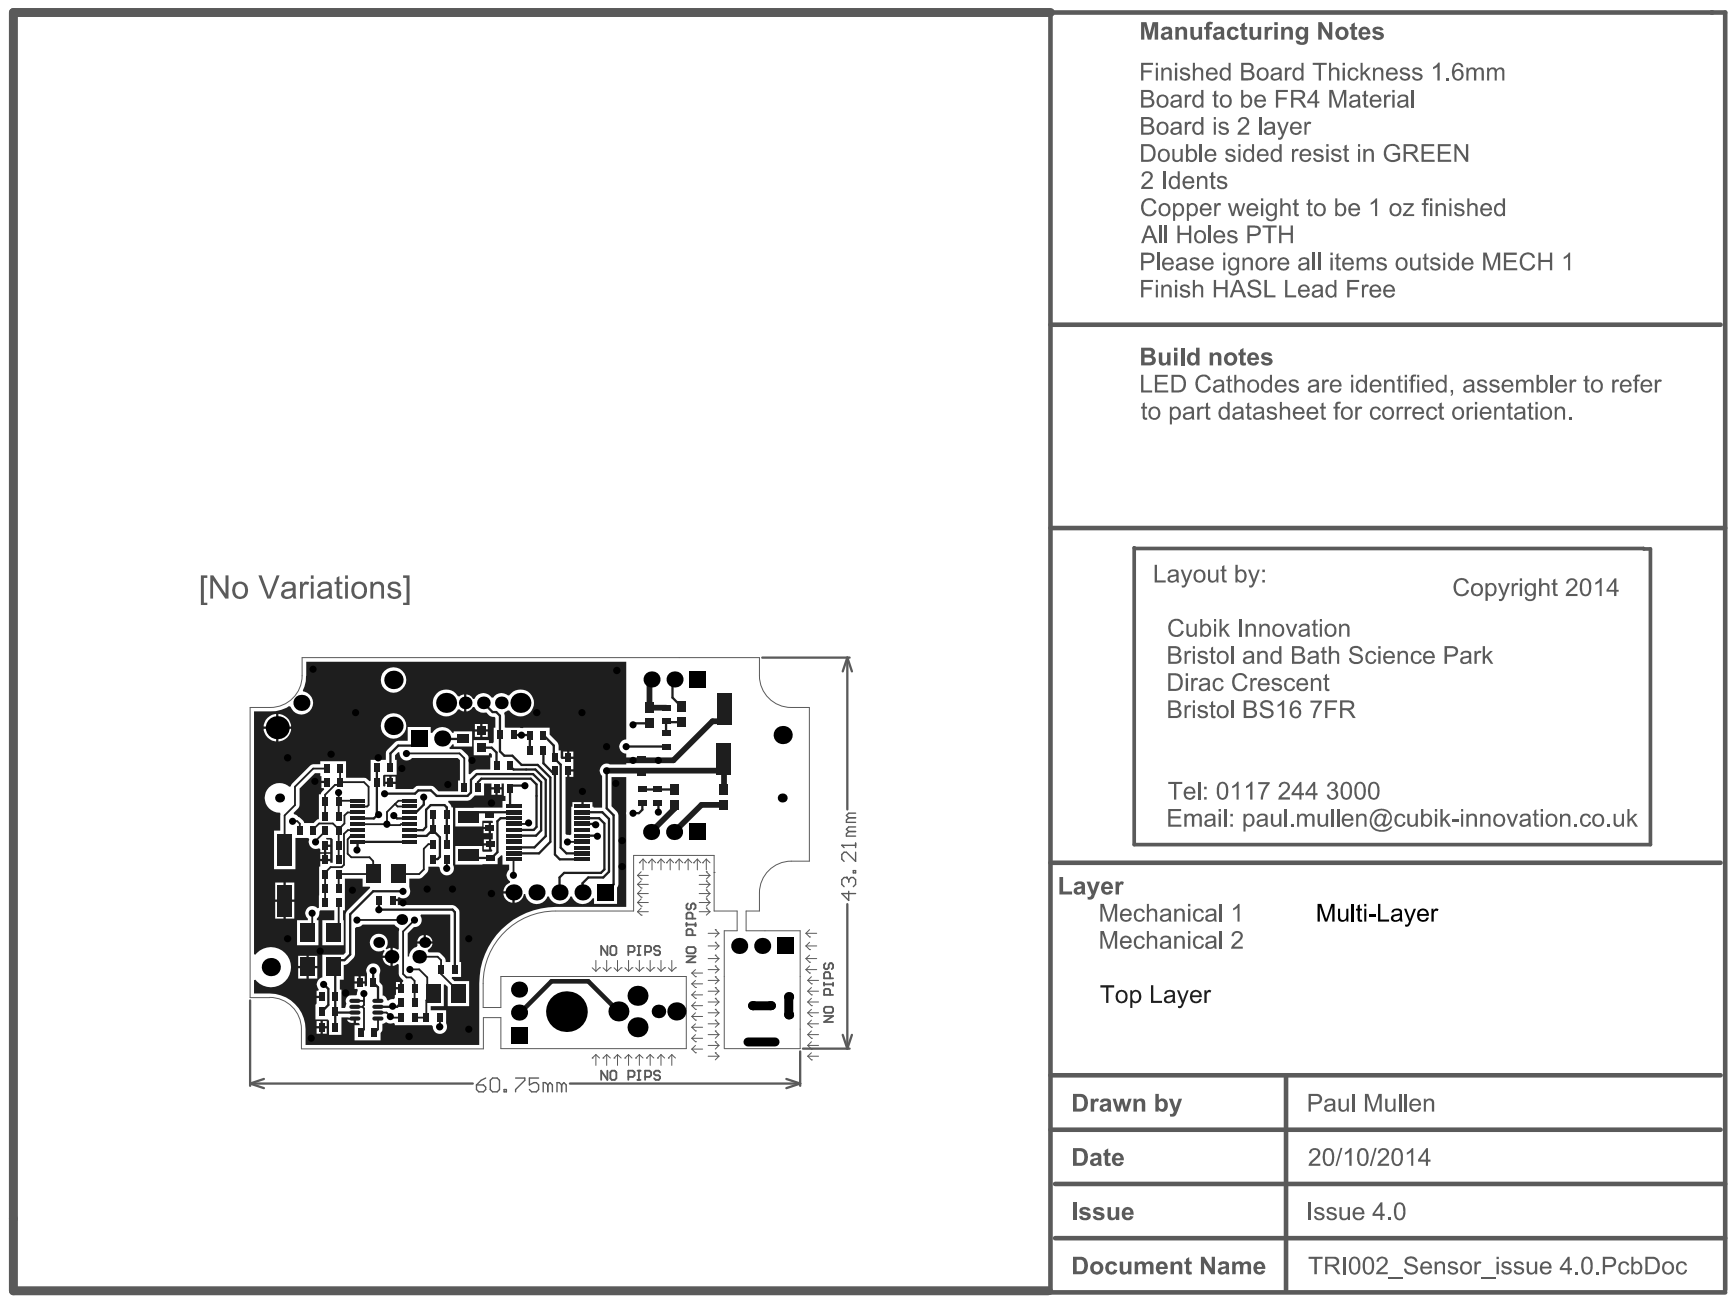
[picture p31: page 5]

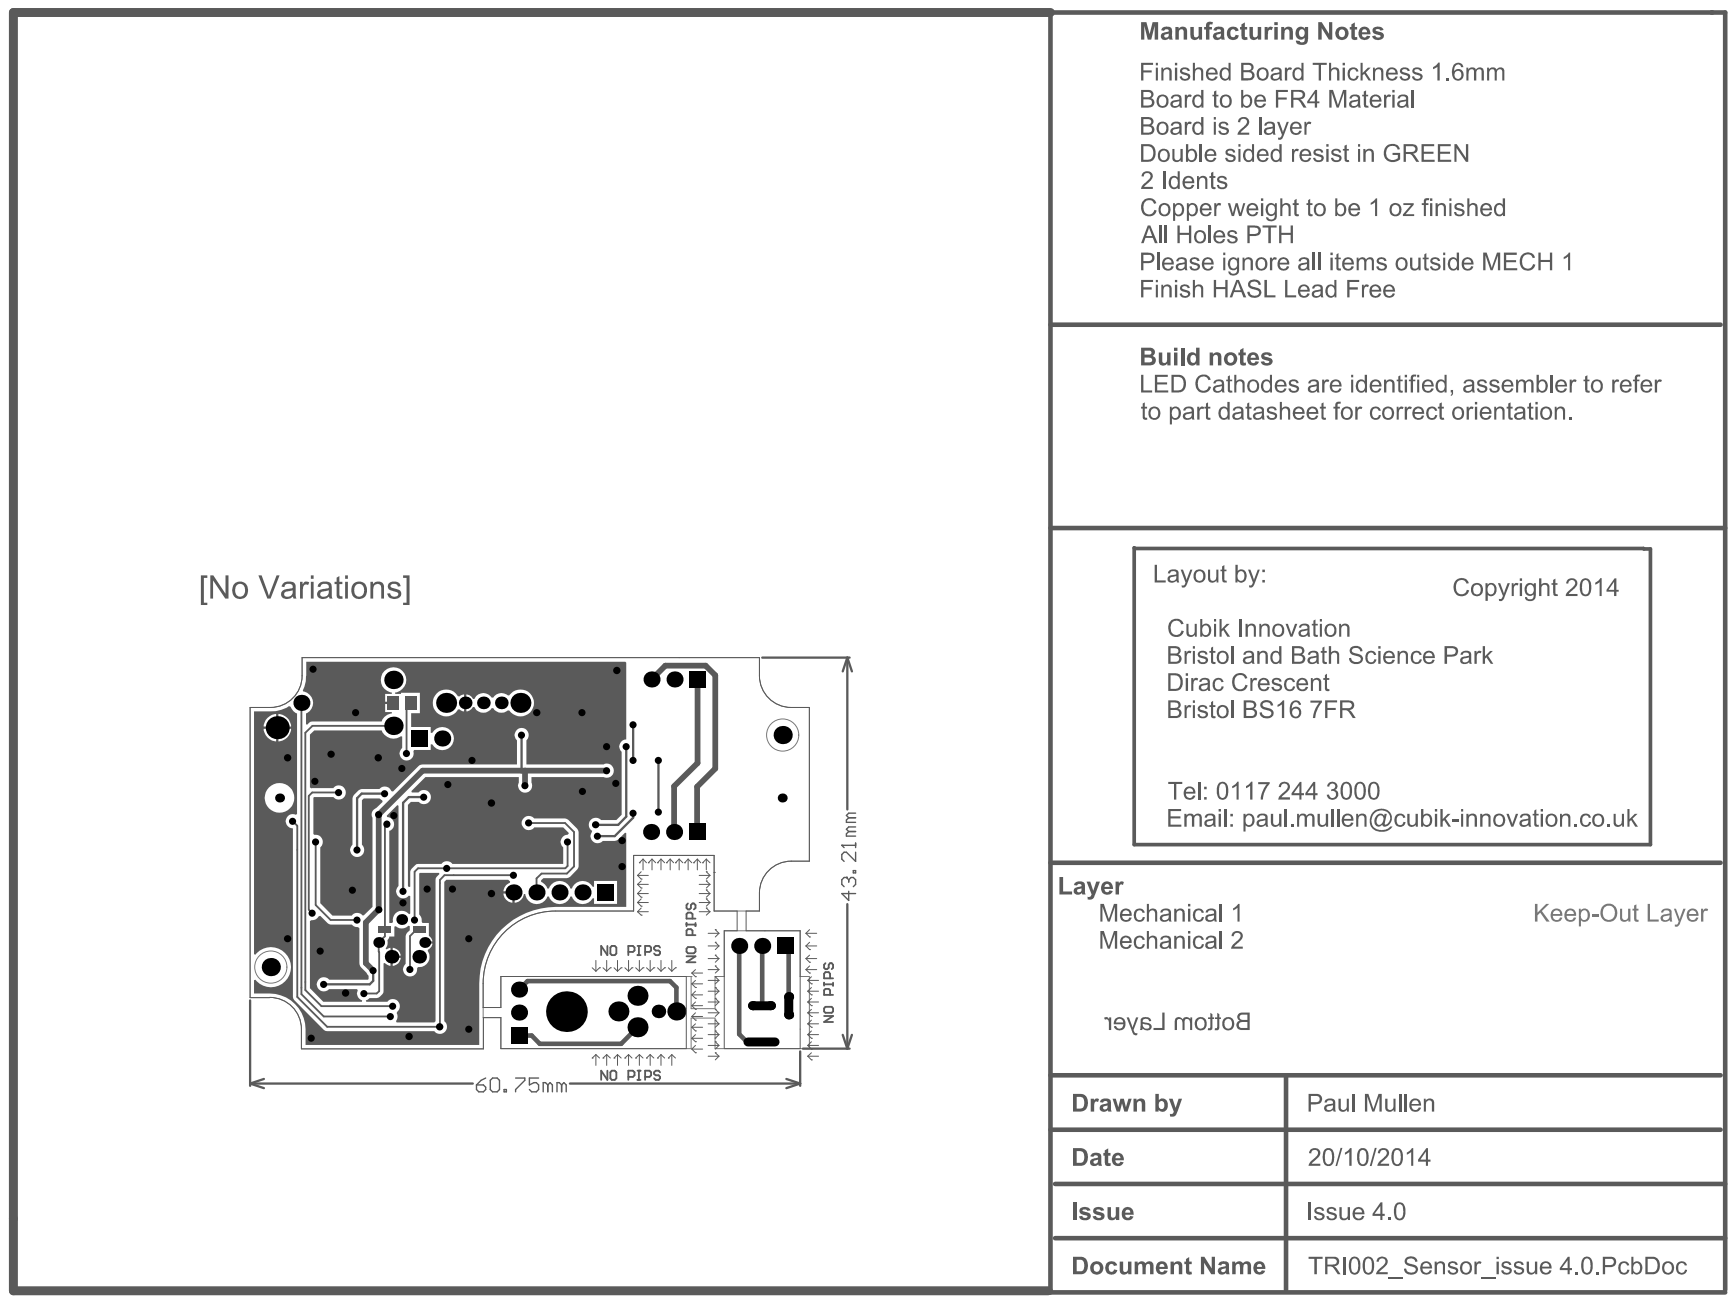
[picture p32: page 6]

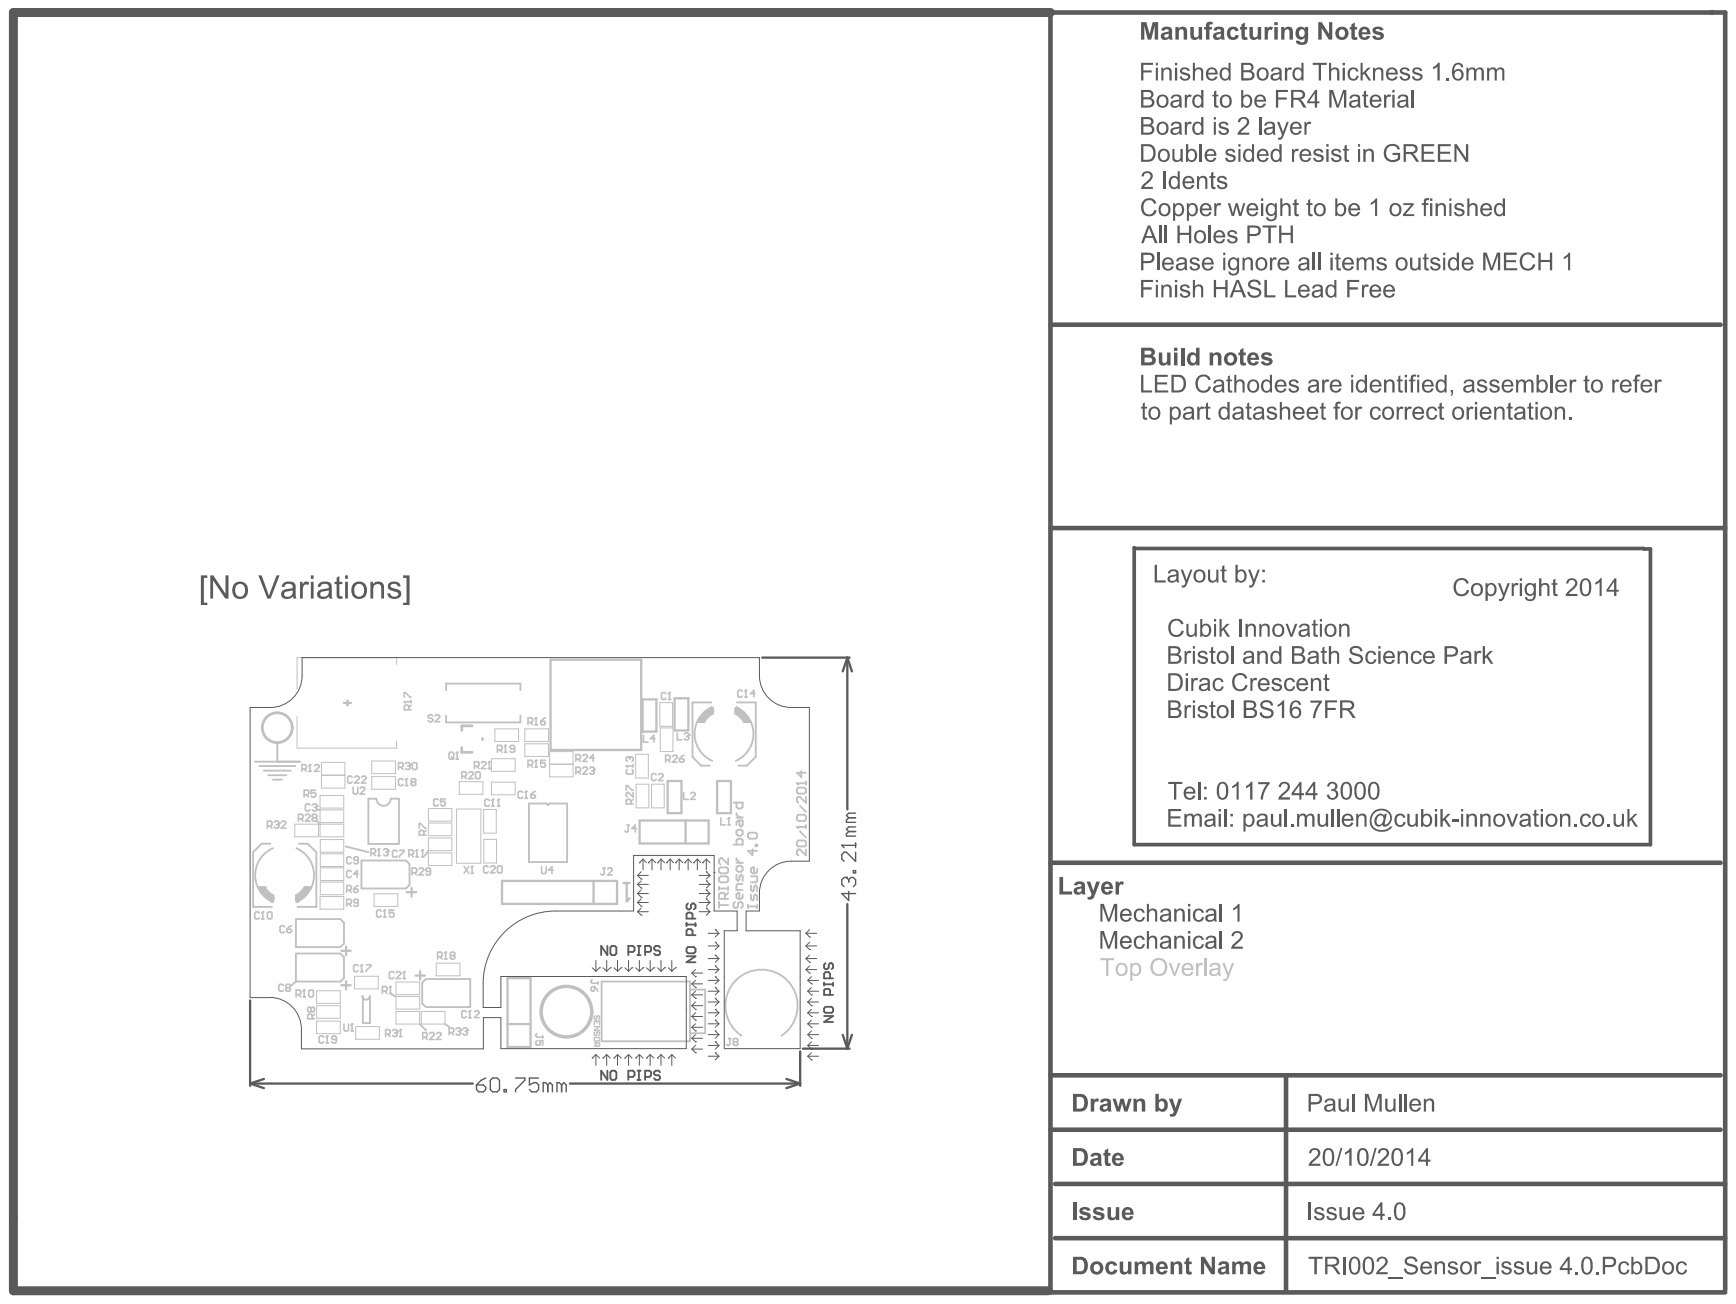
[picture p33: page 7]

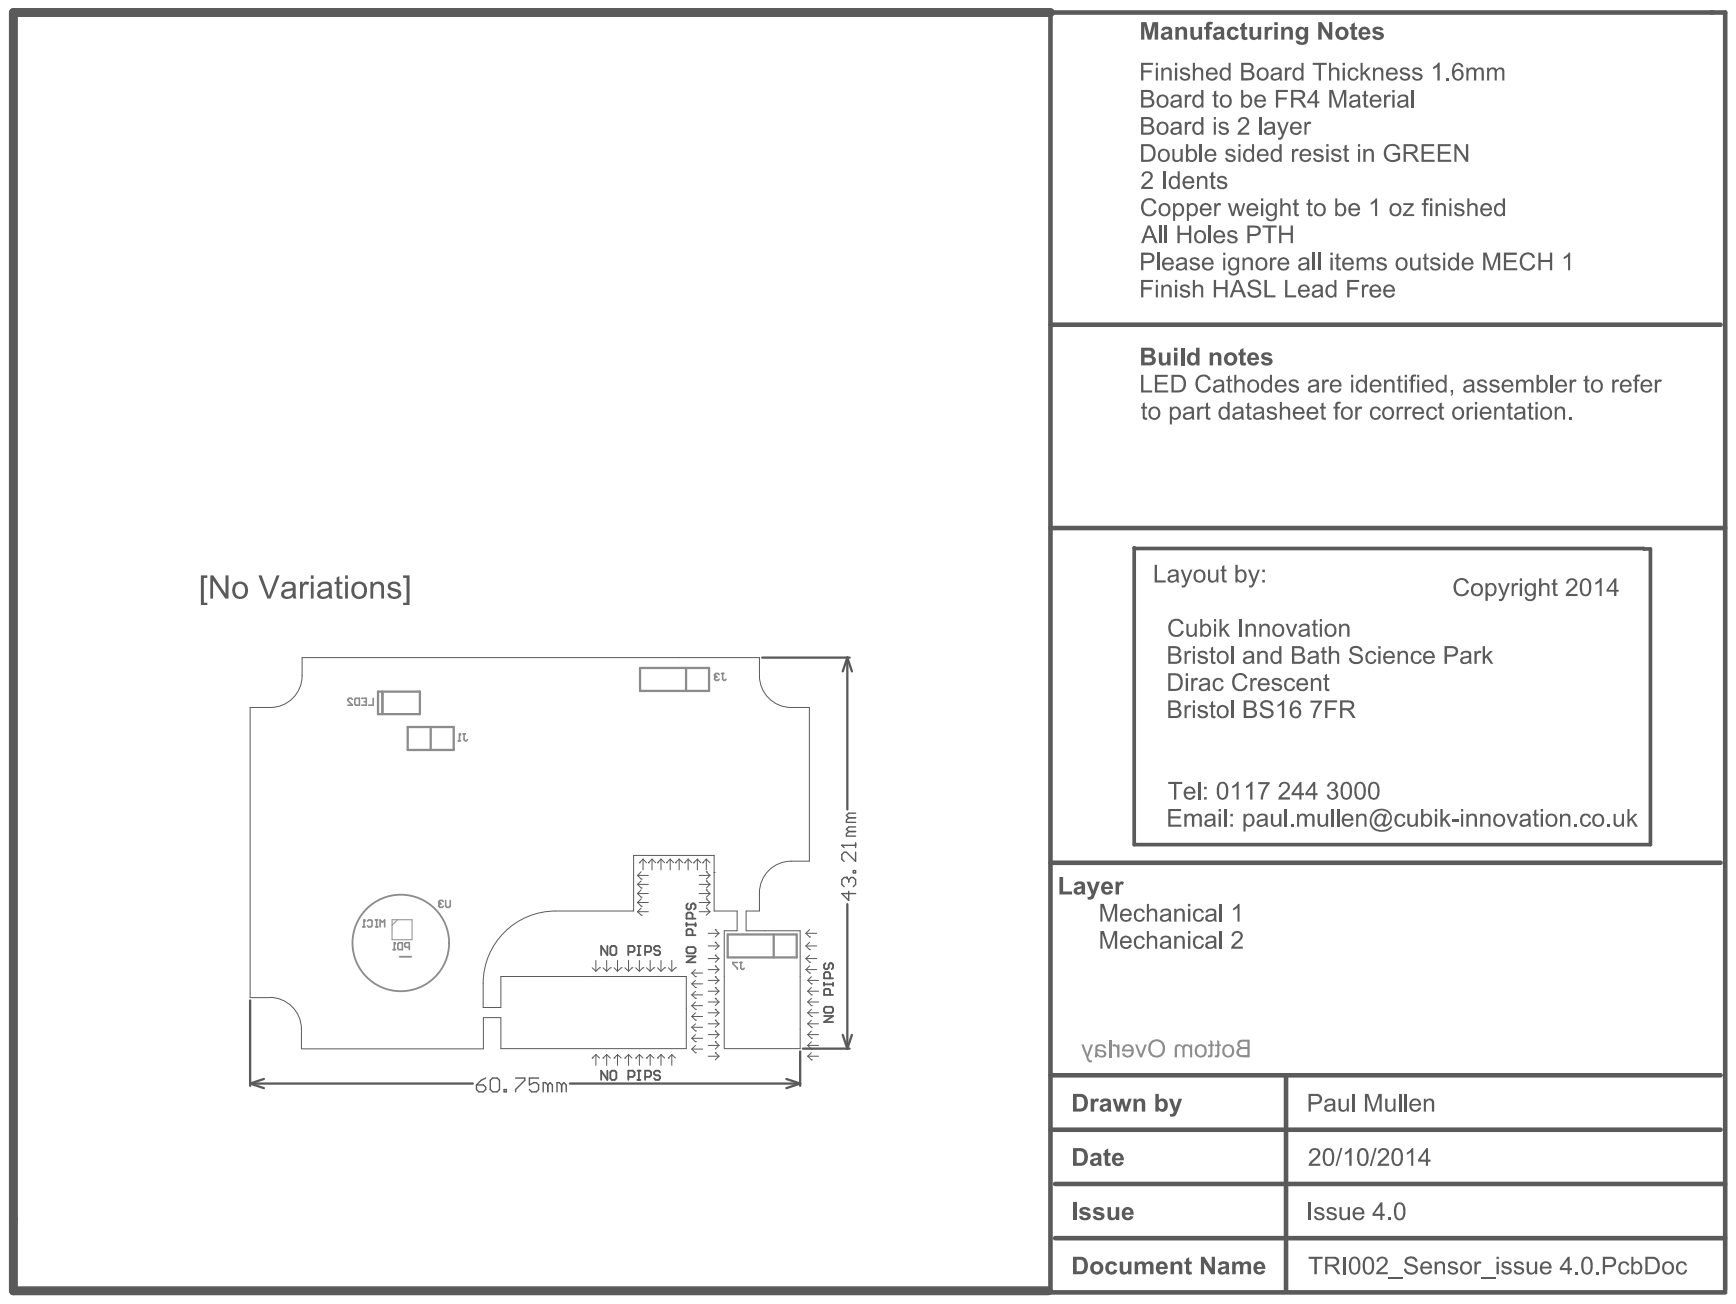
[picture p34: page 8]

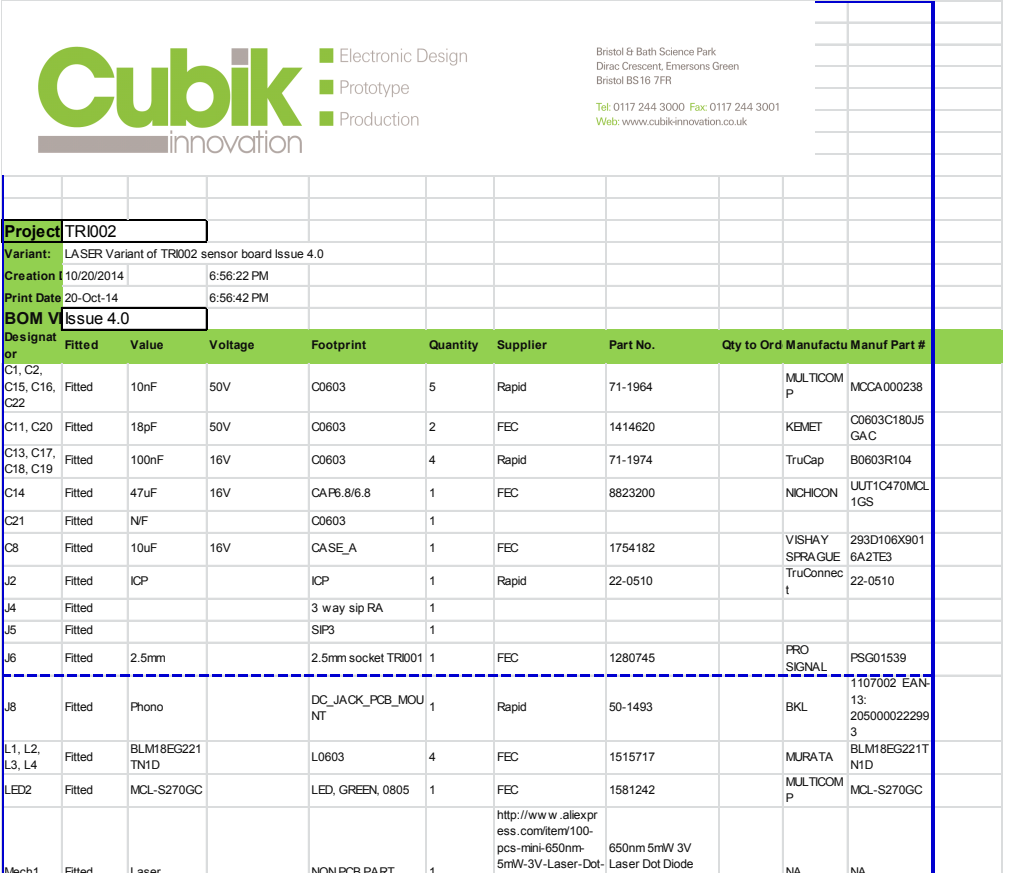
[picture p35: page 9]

Project | TRI002

Variant: Print Date | LASER Variant of TRI002 sensor board Issue 4.0

20-Oct-14 | 6:56:42 PM
BOM VER | Issue 4.0
Designat or Fitted Value Voltage Footprint Quantity Supplier Part No. Qty to OrdeM anufactuManuf Part #

C1, C2, C15, C16, C22 | Fitted | 10nF | 50V | C0603 | 5 | Rapid | 71-1964 | MULTICOM P | MCCA000238

C11, C20 | Fitted | 18pF | 50V | C0603 | 2 | FEC | 1414620 | KEMET | C0603C180J5 GAC

C13, C17, C18, C19 | Fitted | 100nF | 16V | C0603 | 4 | Rapid | 71-1974 | TruCap | B0603R104

C14 | Fitted | 47uF | 16V | CAP6.8/6.8 | 1 | FEC | 8823200 | NICHICON | UUT1C470MCL 1GS

C21 | Fitted | N/F | | C0603 | 1
C8 | Fitted | 10uF | 16V | CASE_A | 1 | FEC | 1754182 | VISHAY SPRAGUE | 293D106X901 6A2TE3

J2 | Fitted | ICP | | ICP | 1 | Rapid | 22-0510 | TruConnec t | 22-0510

J4 | Fitted | | | 3 way sip RA | 1

J5 | Fitted | | | SIP3 | 1
J6 | Fitted | 2.5mm | | 2.5mm socket TRI001 | 1 | FEC | 1280745 | PRO SIGNAL | PSG01539

J8 | Fitted | Phono | | DC_JACK_PCB_MOU NT | 1 | Rapid | 50-1493 | BKL | 1107002 EAN-13: 205000022299 3

L1, L2, L3, L4 | Fitted | BLM18EG221 TN1D | | L0603 | 4 | FEC | 1515717 | MURATA | BLM18EG221T N1D

LED2 | Fitted | MCL-S270GC | | LED, GREEN, 0805 | 1 | FEC | 1581242 | MULTICOM P | MCL-S270GC

Mech1 | Fitted | Laser | NON PCB PART | 1

ess.com/item/100-
pcs-mini-650nm-5mW-3V-Laser-Dot-Diode-Module-Head-WL-Red/896433799.htm
l

650nm 5mW 3V
Laser Dot Diode
Module Head WL
Red
NA | NA
Mech2 | Fitted | BLACK POT SHAFT | | NON PCB PART | 1 | Rapid | 67-0480 | Iskra | 88 131 387
PD1 | Fitted | VEMD2520X0 1 | | DOME LENS | 1 | | 1870779 | VISHAY | VEMD2520X01
Q1 | Fitted | FDN335N | | SOT-23 | 1 | FEC | 9845348RL | FAIRCHILD SEMICOND UCTOR | FDN335N
R1, R15, R16, R21 | Fitted | 1K | | R0603 | 4
R17 | Fitted | PNZ10ZA 1M | | preset_Iskra square | 1 | Rapid | 67-0478 | Iskra | PNZ10ZA 1M
R19, R22, R31 | Fitted | 10k | | R0603 | 3
R20, R26, R27 | Fitted | 220R | | R0603 | 3
R30 | Fitted | 56R | | R0603 | 1
R33 | Fitted | 100k | | R0603 | 1
R8, R10 | Fitted | 1M | | R0603 | 2
S2 | Fitted | MFP113D | | MFP113D | 1 | RS | 702-3634 | KNITTER-SWITCH | MFP113D
U1 | Fitted | TSV6292AILT | | SOT23 8 pin | 1 | FEC | 2067873 | STMICROE LECTRONI CS | TSV6292AILT
U4 | Fitted | PIC16F527-I/SS | 5V | SSOP20 | 1 | FEC | 2301100 | MICROCHIP | PIC16F527-I/SS
X1 | Fitted | ABM3-16.000MHZ-B2-T | | ABS10 | 1 | FEC | 1611806 | ABRACON | ABM3-16.000MHZ-B2-T
C10 | Not Fitted | 47uF | 16V | CAP6.8/6.8 | 0 | FEC | 8823200 | NICHICON | UUT1C470MCL 1GS
C3, C9 | Not Fitted | 10nF | 50V | C0603 | 0 | Rapid | 71-1964 | MULTICOM P | MCCA000238
C4, C5 | Not Fitted | 47nF | 16V | C0603 | 0 | FEC | 432027 | YAGEO | CC0603KRX7R 7BB473
C6, C12 | Not Fitted | 10uF | 16V | CASE_A | 0 | FEC | 1754182 | VISHAY SPRAGUE | 293D106X901 6A2TE3
C7 | Not Fitted | 4.7uF | 16V | CASE_A | 0 | FEC | 1754181 | VISHAY SPRAGUE | 293D475X901 6A2TE3
J1 | Not Fitted | SIP 2 | | SIP2 | 0
J3, J7 | Not Fitted | N/F | | sip3 | 0
MIC1 | Not Fitted | AOM-4542P-R | | ECM | 0 | FEC | 1193029 | PROJECTS UNLIMITED | AOM-4542P-R
R12 | Not Fitted | 15k | | R0603 | 0

R23, R24,
R29
Not Fitted | 1k | R0603 | 0

R

UNLIMITED
R12 | Not Fitted | 15k | | R0603 | 0
R23, R24, R29 | Not Fitted | 1k | | R0603 | 0
R28 | Not Fitted | 18k | | R0603 | 0
R32 | Not Fitted | 100k | | R0603 | 0
R5, R13 | Not Fitted | 47K | | R0603 | 0
R6 | Not Fitted | 1M | | R0603 | 0
R7 | Not Fitted | 680K | | R0603 | 0
R9, R11, R18 | Not Fitted | 10k | | R0603 | 0
U2 | Not Fitted | TSV6295IPT | | TSSOP16 | 0 | FEC | 1842580 | STMICROE LECTRONI CS | TSV6295IPT
U3 | Not Fitted | PIR | 2V - 12V | PIR_TO-5 | 0 | FEC | 2293504 | EXCELITA S TECH | LHI_968

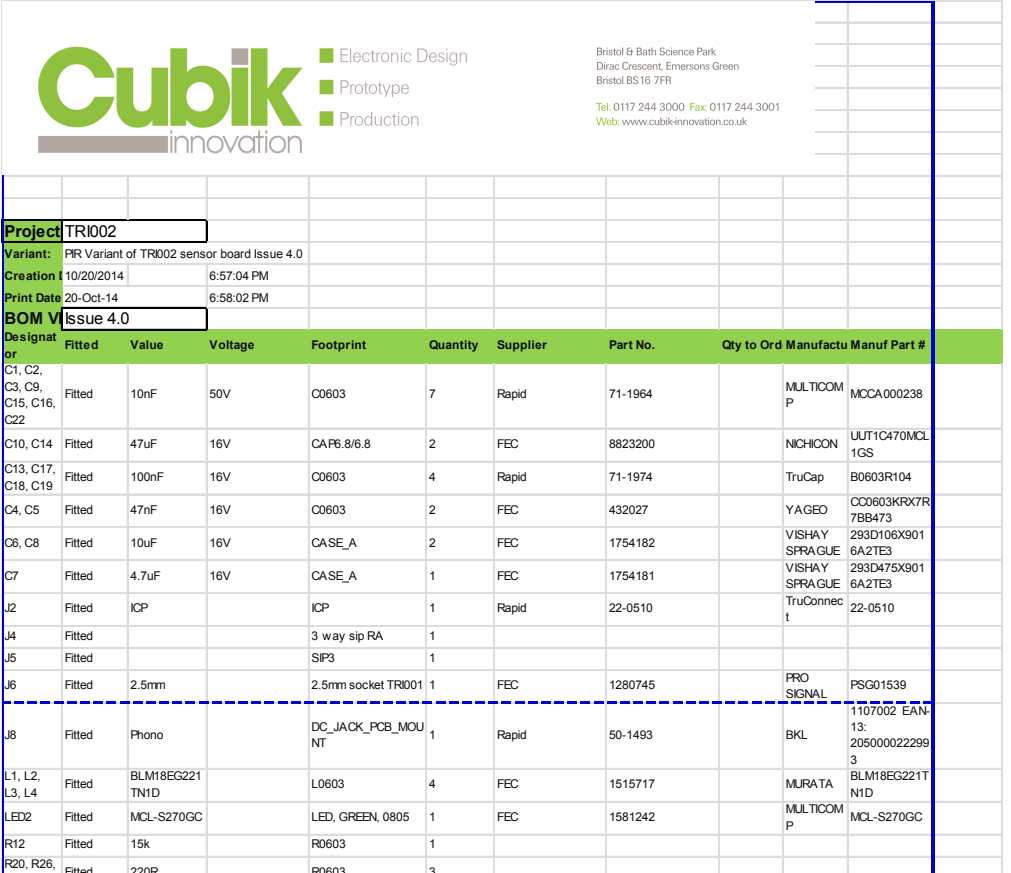
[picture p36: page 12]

Project | TRI002

Variant: Print Date | PIR Variant of TRI002 sensor board Issue 4.0

20-Oct-14 | 6:58:02 PM
BOM VER | Issue 4.0
Designat or Fitted Value Voltage Footprint Quantity Supplier Part No. Qty to OrdeM anufactuManuf Part #

C1, C2, C3, C9, C15, C16, C22 | Fitted | 10nF | 50V | C0603 | 7 | Rapid | 71-1964 | MULTICOM P | MCCA000238

C10, C14 | Fitted | 47uF | 16V | CAP6.8/6.8 | 2 | FEC | 8823200 | NICHICON | UUT1C470MCL 1GS

C13, C17, C18, C19 | Fitted | 100nF | 16V | C0603 | 4 | Rapid | 71-1974 | TruCap | B0603R104

C4, C5 | Fitted | 47nF | 16V | C0603 | 2 | FEC | 432027 | YAGEO | CC0603KRX7R 7BB473

C6, C8 | Fitted | 10uF | 16V | CASE_A | 2 | FEC | 1754182 | VISHAY SPRAGUE | 293D106X901 6A2TE3

C7 | Fitted | 4.7uF | 16V | CASE_A | 1 | FEC | 1754181 | VISHAY SPRAGUE | 293D475X901 6A2TE3

J2 | Fitted | ICP | | ICP | 1 | Rapid | 22-0510 | TruConnec t | 22-0510

J4 | Fitted | | | 3 way sip RA | 1

J5 | Fitted | | | SIP3 | 1
J6 | Fitted | 2.5mm | | 2.5mm socket TRI001 | 1 | FEC | 1280745 | PRO SIGNAL | PSG01539

J8 | Fitted | Phono | | DC_JACK_PCB_MOU NT | 1 | Rapid | 50-1493 | BKL | 1107002 EAN-13: 205000022299 3

L1, L2, L3, L4 | Fitted | BLM18EG221 TN1D | | L0603 | 4 | FEC | 1515717 | MURATA | BLM18EG221T N1D

LED2 | Fitted | MCL-S270GC | | LED, GREEN, 0805 | 1 | FEC | 1581242 | MULTICOM P | MCL-S270GC

R12 | Fitted | 15k | | R0603 | 1

LED2 | Fitted | MCL-S270GC | LED, GREEN, 0805 | 1 | FEC | 1581242
P

MCL-S270GC

R12 | Fitted | 15k | | R0603 | 1
R20, R26, R27 | Fitted | 220R | | R0603 | 3
R23, R24, R29 | Fitted | 1k | | R0603 | 3
R28 | Fitted | 18k | | R0603 | 1
R32 | Fitted | 100k | | R0603 | 1
R5, R13 | Fitted | 47K | | R0603 | 2
R6, R8, R10 | Fitted | 1M | | R0603 | 3
R7 | Fitted | 680K | | R0603 | 1
R9, R11 | Fitted | 10k | | R0603 | 2
U2 | Fitted | TSV6295IPT | | TSSOP16 | 1 | FEC | 1842580 | STMICROE LECTRONI CS | TSV6295IPT
U3 | Fitted | PIR | 2V - 12V | PIR_TO-5 | 1 | FEC | 2293504 | EXCELITA S TECH | LHI_968
U4 | Fitted | PIC16F527-I/SS | 5V | SSOP20 | 1 | FEC | 2301100 | MICROCHIP | PIC16F527-I/SS
C11, C20 | Not Fitted | 18pF | 50V | C0603 | 0 | FEC | 1414620 | KEMET | C0603C180J5 GAC
C12 | Not Fitted | 10uF | 16V | CASE_A | 0 | FEC | 1754182 | VISHAY SPRAGUE | 293D106X901 6A2TE3
C21 | Not Fitted | N/F | | C0603 | 0
J1 | Not Fitted | SIP 2 | | SIP2 | 0
J3, J7 | Not Fitted | N/F | | sip3 | 0
Mech1 | Not Fitted | Laser | | NON PCB PART | 0 | http://ww w .aliexpr ess.com/item/100-pcs-mini-650nm-5mW-3V-Laser-Dot-Diode-Module-Head-WL-Red/896433799.htm l | 650nm 5mW 3V Laser Dot Diode Module Head WL Red | NA | NA
Mech2 | Not Fitted | BLACK POT SHAFT | | NON PCB PART | 0 | Rapid | 67-0480 | Iskra | 88 131 387
MIC1 | Not Fitted | AOM-4542P-R | | ECM | 0 | FEC | 1193029 | PROJECTS UNLIMITED | AOM-4542P-R
PD1 | Not Fitted | VEMD2520X0 1 | | DOME LENS | 0 | | 1870779 | VISHAY | VEMD2520X01
Q1 | Not Fitted | FDN335N | | SOT-23 | 0 | FEC | 9845348RL | FAIRCHILD SEMICOND UCTOR | FDN335N
R1, R15, R16, R21 | Not Fitted | 1K | | R0603 | 0
R17 | Not Fitted | PNZ10ZA 1M | | preset_Iskra square | 0 | Rapid | 67-0478 | Iskra | PNZ10ZA 1M
R18, R19, R22, R31 | Not Fitted | 10k | | R0603 | 0
R30 | Not Fitted | 56R | R0603 | 0

R17 | Not Fitted | PNZ10ZA 1M | preset_Iskra square 0 | Rapid | 67-0478 | Iskra | PNZ10ZA 1M
R18, R19, R22, R31 | Not Fitted | 10k | R0603 | 0
R30 | Not Fitted | 56R | R0603 | 0
R33 | Not Fitted | 100k | R0603 | 0
S2 | Not Fitted | MFP113D | MFP113D | 0 | RS | 702-3634 | KNITTER-SWITCH | MFP113D
U1 | Not Fitted | TSV6292AILT | SOT23 8 pin | 0 | FEC | 2067873 | STMICROE LECTRONI CS | TSV6292AILT
X1 | Not Fitted | ABM3-16.000MHZ-B2-T | ABS10 | 0 | FEC | 1611806 | ABRACON | ABM3-16.000MHZ-B2-T

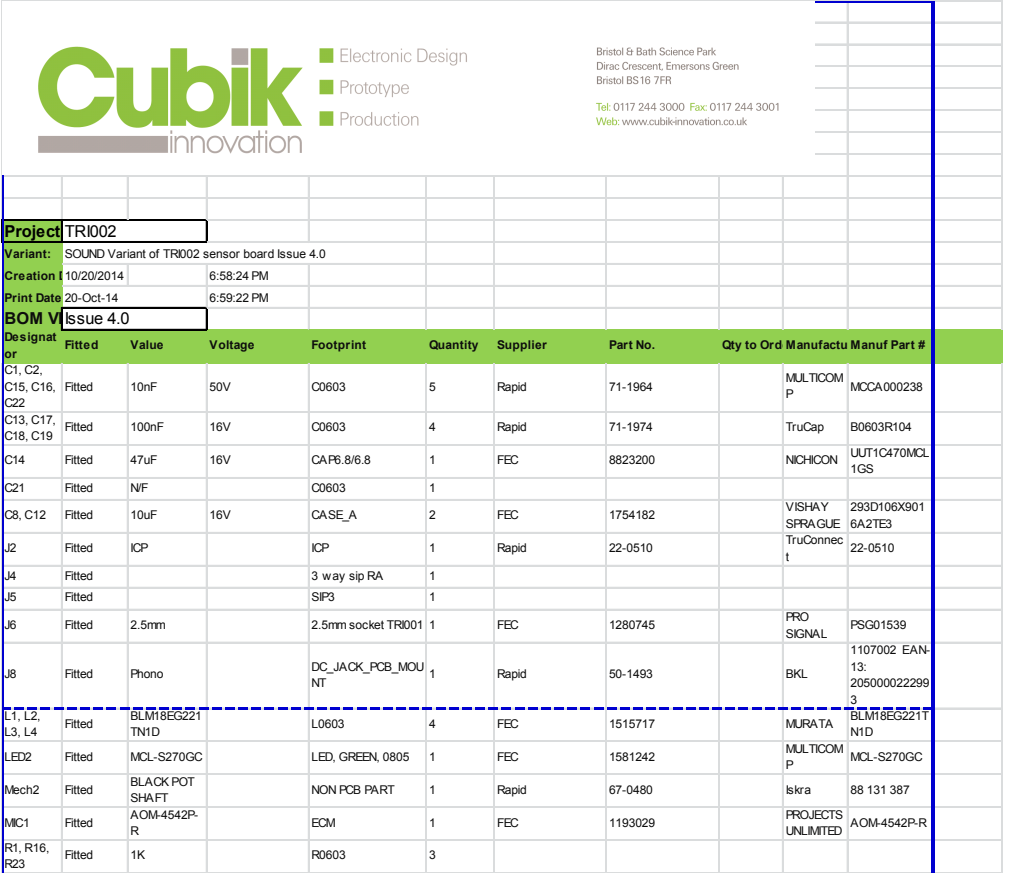
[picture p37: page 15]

Project | TRI002

Variant: Print Date | SOUND Variant of TRI002 sensor board Issue 4.0

20-Oct-14 | 6:59:22 PM
BOM VER | Issue 4.0
Designat or Fitted Value Voltage Footprint Quantity Supplier Part No. Qty to OrdeM anufactuManuf Part #

C1, C2, C15, C16, C22 | Fitted | 10nF | 50V | C0603 | 5 | Rapid | 71-1964 | MULTICOM P | MCCA000238

C13, C17, C18, C19 | Fitted | 100nF | 16V | C0603 | 4 | Rapid | 71-1974 | TruCap | B0603R104

C14 | Fitted | 47uF | 16V | CAP6.8/6.8 | 1 | FEC | 8823200 | NICHICON | UUT1C470MCL 1GS

C21 | Fitted | N/F | | C0603 | 1
C8, C12 | Fitted | 10uF | 16V | CASE_A | 2 | FEC | 1754182 | VISHAY SPRAGUE | 293D106X901 6A2TE3

J2 | Fitted | ICP | | ICP | 1 | Rapid | 22-0510 | TruConnec t | 22-0510

J4 | Fitted | | | 3 way sip RA | 1

J5 | Fitted | | | SIP3 | 1
J6 | Fitted | 2.5mm | | 2.5mm socket TRI001 | 1 | FEC | 1280745 | PRO SIGNAL | PSG01539

J8 | Fitted | Phono | | DC_JACK_PCB_MOU NT | 1 | Rapid | 50-1493 | BKL | 1107002 EAN-13: 205000022299 3

L1, L2, L3, L4 | Fitted | BLM18EG221 TN1D | | L0603 | 4 | FEC | 1515717 | MURATA | BLM18EG221T N1D

LED2 | Fitted | MCL-S270GC | | LED, GREEN, 0805 | 1 | FEC | 1581242 | MULTICOM P | MCL-S270GC

Mech2 | Fitted | BLACK POT SHAFT | | NON PCB PART | 1 | Rapid | 67-0480 | Iskra | 88 131 387

MIC1 | Fitted | AOM-4542P-R | | ECM | 1 | FEC | 1193029 | PROJECTS UNLIMITED | AOM-4542P-R

R1, R16, R23 | Fitted | 1K | | R0603 | 3

MIC1 | Fitted | R
ECM | 1 | FEC | 1193029
UNLIMITED

AOM-4542P-R

R1, R16, R23 | Fitted | 1K | | R0603 | 3
R17 | Fitted | PNZ10ZA 1M | | preset_Iskra square | 1 | Rapid | 67-0478 | Iskra | PNZ10ZA 1M
R18, R22, R31 | Fitted | 10k | | R0603 | 3
R20, R26, R27 | Fitted | 220R | | R0603 | 3
R33 | Fitted | 100k | | R0603 | 1
R8, R10 | Fitted | 1M | | R0603 | 2
U1 | Fitted | TSV6292AILT | | SOT23 8 pin | 1 | FEC | 2067873 | STMICROE LECTRONI CS | TSV6292AILT
U4 | Fitted | PIC16F527-I/SS | 5V | SSOP20 | 1 | FEC | 2301100 | MICROCHIP | PIC16F527-I/SS
C10 | Not Fitted | 47uF | 16V | CAP6.8/6.8 | 0 | FEC | 8823200 | NICHICON | UUT1C470MCL 1GS
C11, C20 | Not Fitted | 18pF | 50V | C0603 | 0 | FEC | 1414620 | KEMET | C0603C180J5 GAC
C3, C9 | Not Fitted | 10nF | 50V | C0603 | 0 | Rapid | 71-1964 | MULTICOM P | MCCA000238
C4, C5 | Not Fitted | 47nF | 16V | C0603 | 0 | FEC | 432027 | YAGEO | CC0603KRX7R 7BB473
C6 | Not Fitted | 10uF | 16V | CASE_A | 0 | FEC | 1754182 | VISHAY SPRAGUE | 293D106X901 6A2TE3
C7 | Not Fitted | 4.7uF | 16V | CASE_A | 0 | FEC | 1754181 | VISHAY SPRAGUE | 293D475X901 6A2TE3
J1 | Not Fitted | SIP 2 | | SIP2 | 0
J3, J7 | Not Fitted | N/F | | sip3 | 0
Mech1 | Not Fitted | Laser | | NON PCB PART | 0 | http://ww w .aliexpr ess.com/item/100-pcs-mini-650nm-5mW-3V-Laser-Dot-Diode-Module-Head-WL-Red/896433799.htm l | 650nm 5mW 3V Laser Dot Diode Module Head WL Red | NA | NA
PD1 | Not Fitted | VEMD2520X0 1 | | DOME LENS | 0 | | 1870779 | VISHAY | VEMD2520X01
Q1 | Not Fitted | FDN335N | | SOT-23 | 0 | FEC | 9845348RL | FAIRCHILD SEMICOND UCTOR | FDN335N
R12 | Not Fitted | 15k | | R0603 | 0
R15, R21, R24, R29 | Not Fitted | 1k | | R0603 | 0
R28 | Not Fitted | 18k | | R0603 | 0
R30 | Not Fitted | 56R | | R0603 | 0
R32 | Not Fitted | 100k | | R0603 | 0
R5, R13 | Not Fitted | 47K | | R0603 | 0
R6 | Not Fitted | 1M | R0603 | 0

R32 | Not Fitted | 100k | | R0603 | 0
R5, R13 | Not Fitted | 47K | | R0603 | 0
R6 | Not Fitted | 1M | | R0603 | 0
R7 | Not Fitted | 680K | | R0603 | 0
R9, R11, R19 | Not Fitted | 10k | | R0603 | 0
S2 | Not Fitted | MFP113D | | MFP113D | 0 | RS | 702-3634 | KNITTER-SWITCH | MFP113D
U2 | Not Fitted | TSV6295IPT | | TSSOP16 | 0 | FEC | 1842580 | STMICROE LECTRONI CS | TSV6295IPT
U3 | Not Fitted | PIR | 2V - 12V | PIR_TO-5 | 0 | FEC | 2293504 | EXCELITA S TECH | LHI_968
X1 | Not Fitted | ABM3-16.000MHZ-B2-T | | ABS10 | 0 | FEC | 1611806 | ABRACON | ABM3-16.000MHZ-B2-T

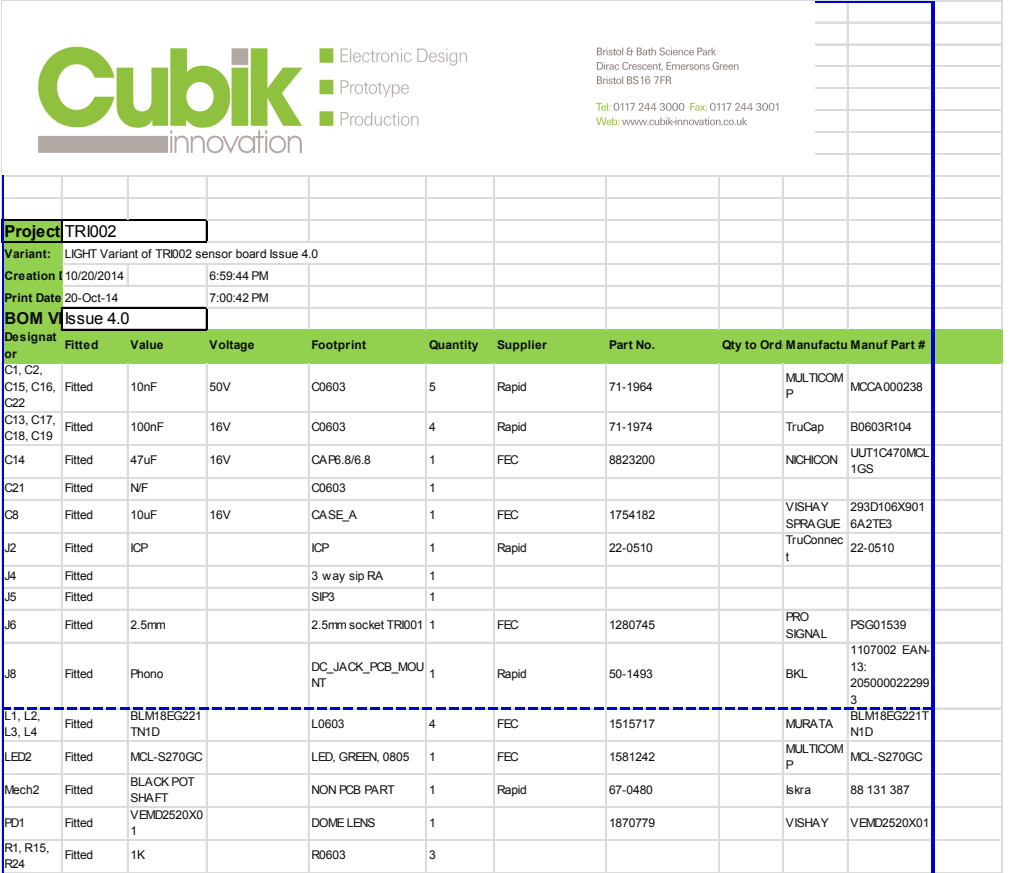
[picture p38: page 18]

Project | TRI002

Variant: Print Date | LIGHT Variant of TRI002 sensor board Issue 4.0

20-Oct-14 | 7:00:42 PM
BOM VER | Issue 4.0
Designat or Fitted Value Voltage Footprint Quantity Supplier Part No. Qty to OrdeM anufactuManuf Part #

C1, C2, C15, C16, C22 | Fitted | 10nF | 50V | C0603 | 5 | Rapid | 71-1964 | MULTICOM P | MCCA000238

C13, C17, C18, C19 | Fitted | 100nF | 16V | C0603 | 4 | Rapid | 71-1974 | TruCap | B0603R104

C14 | Fitted | 47uF | 16V | CAP6.8/6.8 | 1 | FEC | 8823200 | NICHICON | UUT1C470MCL 1GS

C21 | Fitted | N/F | | C0603 | 1
C8 | Fitted | 10uF | 16V | CASE_A | 1 | FEC | 1754182 | VISHAY SPRAGUE | 293D106X901 6A2TE3

J2 | Fitted | ICP | | ICP | 1 | Rapid | 22-0510 | TruConnec t | 22-0510

J4 | Fitted | | | 3 way sip RA | 1

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

J8 | Fitted | Phono | | DC_JACK_PCB_MOU NT | 1 | Rapid | 50-1493 | BKL | 1107002 EAN-13: 205000022299 3

L1, L2, L3, L4 | Fitted | BLM18EG221 TN1D | | L0603 | 4 | FEC | 1515717 | MURATA | BLM18EG221T N1D

LED2 | Fitted | MCL-S270GC | | LED, GREEN, 0805 | 1 | FEC | 1581242 | MULTICOM P | MCL-S270GC

Mech2 | Fitted | BLACK POT SHAFT | | NON PCB PART | 1 | Rapid | 67-0480 | Iskra | 88 131 387

PD1 | Fitted | VEMD2520X0 1 | | DOME LENS | 1 | | 1870779 | VISHAY | VEMD2520X01

R1, R15, R24 | Fitted | 1K | | R0603 | 3

PD1 | Fitted
1
DOME LENS | 1 | 1870779 | VISHAY | VEMD2520X01
R1, R15, R24 | Fitted | 1K | | R0603 | 3
R17 | Fitted | PNZ10ZA 1M | | preset_Iskra square | 1 | Rapid | 67-0478 | Iskra | PNZ10ZA 1M
R19, R22, R31 | Fitted | 10k | | R0603 | 3
R20, R26, R27 | Fitted | 220R | | R0603 | 3
R33 | Fitted | 100k | | R0603 | 1
R8, R10 | Fitted | 1M | | R0603 | 2
S2 | Fitted | MFP113D | | MFP113D | 1 | RS | 702-3634 | KNITTER-SWITCH | MFP113D
U1 | Fitted | TSV6292AILT | | SOT23 8 pin | 1 | FEC | 2067873 | STMICROE LECTRONI CS | TSV6292AILT
U4 | Fitted | PIC16F527-I/SS | 5V | SSOP20 | 1 | FEC | 2301100 | MICROCHIP | PIC16F527-I/SS
C10 | Not Fitted | 47uF | 16V | CAP6.8/6.8 | 0 | FEC | 8823200 | NICHICON | UUT1C470MCL 1GS
C11, C20 | Not Fitted | 18pF | 50V | C0603 | 0 | FEC | 1414620 | KEMET | C0603C180J5 GAC
C3, C9 | Not Fitted | 10nF | 50V | C0603 | 0 | Rapid | 71-1964 | MULTICOM P | MCCA000238
C4, C5 | Not Fitted | 47nF | 16V | C0603 | 0 | FEC | 432027 | YAGEO | CC0603KRX7R 7BB473
C6, C12 | Not Fitted | 10uF | 16V | CASE_A | 0 | FEC | 1754182 | VISHAY SPRAGUE | 293D106X901 6A2TE3
C7 | Not Fitted | 4.7uF | 16V | CASE_A | 0 | FEC | 1754181 | VISHAY SPRAGUE | 293D475X901 6A2TE3
J1 | Not Fitted | SIP 2 | | SIP2 | 0
J3, J7 | Not Fitted | N/F | | sip3 | 0
Mech1 | Not Fitted | Laser | | NON PCB PART | 0 | http://ww w .aliexpr ess.com/item/100-pcs-mini-650nm-5mW-3V-Laser-Dot-Diode-Module-Head-WL-Red/896433799.htm l | 650nm 5mW 3V Laser Dot Diode Module Head WL Red | NA | NA
MIC1 | Not Fitted | AOM-4542P-R | | ECM | 0 | FEC | 1193029 | PROJECTS UNLIMITED | AOM-4542P-R
Q1 | Not Fitted | FDN335N | | SOT-23 | 0 | FEC | 9845348RL | FAIRCHILD SEMICOND UCTOR | FDN335N
R12 | Not Fitted | 15k | | R0603 | 0
R16, R21, R23, R29 | Not Fitted | 1k | | R0603 | 0
R28 | Not Fitted | 18k | | R0603 | 0
R30 | Not Fitted | 56R | | R0603 | 0
R32 | Not Fitted | 100k | R0603 | 0

R28 | Not Fitted | 18k | R0603 | 0
R30 | Not Fitted | 56R | | R0603 | 0
R32 | Not Fitted | 100k | | R0603 | 0
R5, R13 | Not Fitted | 47K | | R0603 | 0
R6 | Not Fitted | 1M | | R0603 | 0
R7 | Not Fitted | 680K | | R0603 | 0
R9, R11, R18 | Not Fitted | 10k | | R0603 | 0
U2 | Not Fitted | TSV6295IPT | | TSSOP16 | 0 | FEC | 1842580 | STMICROE LECTRONI CS | TSV6295IPT
U3 | Not Fitted | PIR | 2V - 12V | PIR_TO-5 | 0 | FEC | 2293504 | EXCELITA S TECH | LHI_968
X1 | Not Fitted | ABM3-16.000MHZ-B2-T | | ABS10 | 0 | FEC | 1611806 | ABRACON | ABM3-16.000MHZ-B2-T

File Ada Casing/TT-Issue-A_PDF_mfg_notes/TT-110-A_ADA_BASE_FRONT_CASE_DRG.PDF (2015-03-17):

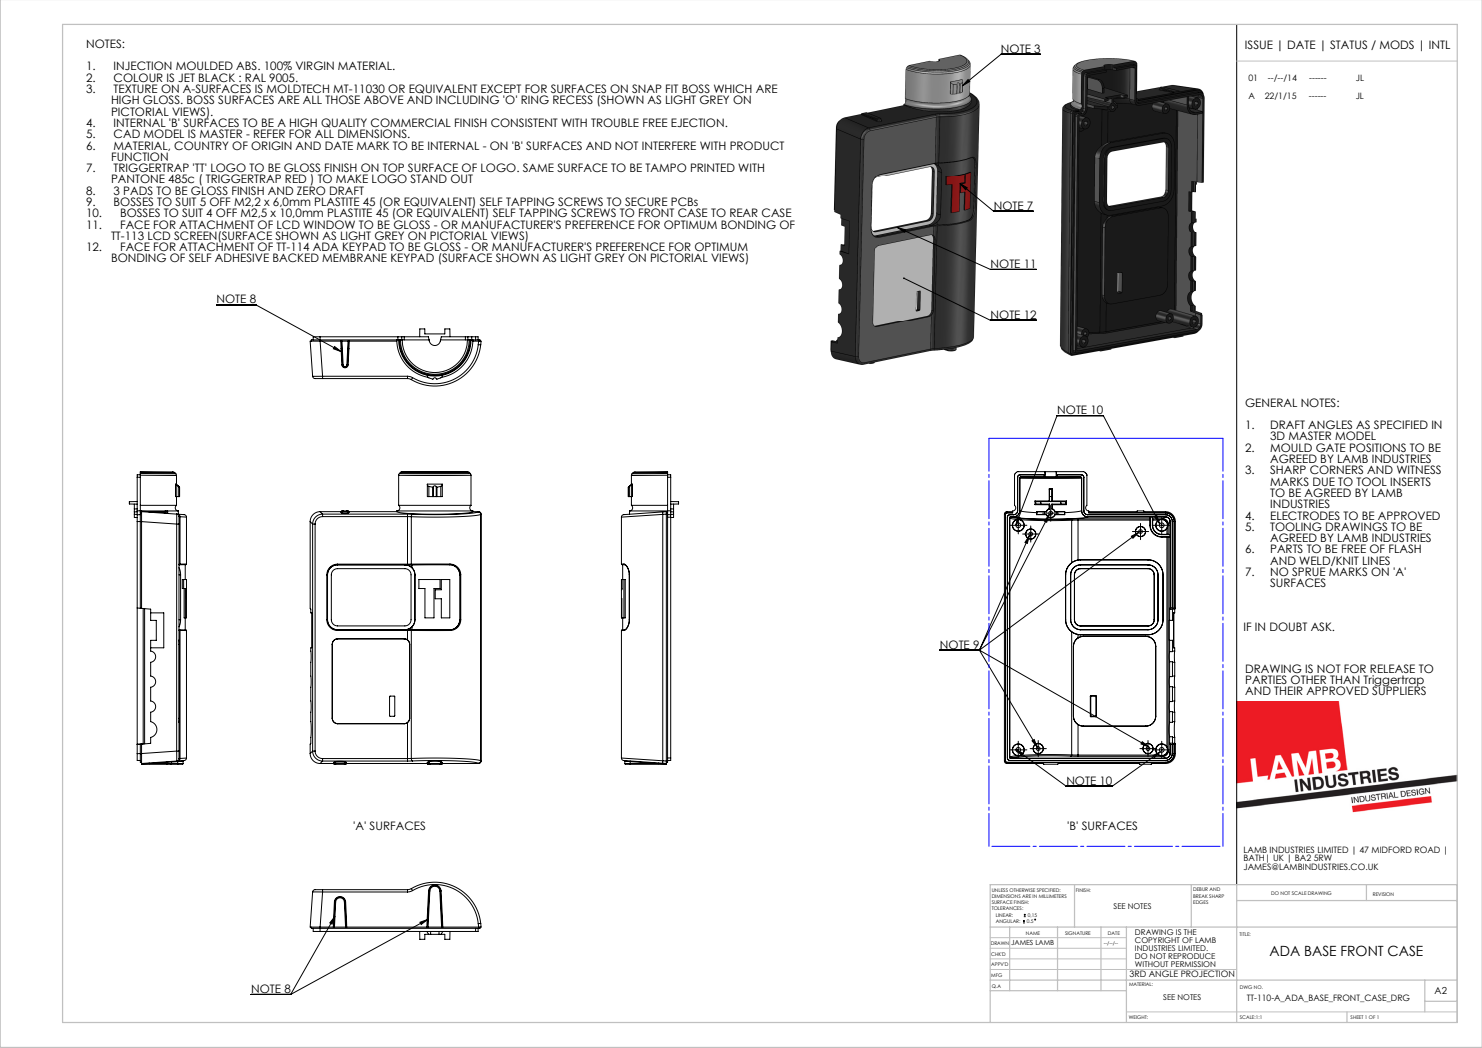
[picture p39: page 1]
NOTE 3; NOTE 11; NOTE 7; NOTE 12; NOTE 9; NOTE 10; NOTE 8; 'A' SURFACES; 'B' SURFACES; SEE NOTES; SCALE:1:1; SHEET 1 OF 1; DO NOT SCALE DRAWING; REVISION; DEBUR AND BREAK SHARP; UNLESS OTHERWISE SPECIFIED:; FINISH:

NOTES:
1. INJECTION MOULDED ABS. 100% VIRGIN MATERIAL.
2. COLOUR IS JET BLACK : RAL 9005.
3. TEXTURE ON A-SURFACES IS MOLDTECH MT-11030 OR EQUIVALENT EXCEPT FOR SURFACES ON SNAP FIT BOSS WHICH ARE
HIGH GLOSS. BOSS SURFACES ARE ALL THOSE ABOVE AND INCLUDING 'O' RING RECESS (SHOWN AS LIGHT GREY ON
PICTORIAL VIEWS).
4. INTERNAL 'B' SURFACES TO BE A HIGH QUALITY COMMERCIAL FINISH CONSISTENT WITH TROUBLE FREE EJECTION.
5. CAD MODEL IS MASTER - REFER FOR ALL DIMENSIONS.
6. MATERIAL, COUNTRY OF ORIGIN AND DATE MARK TO BE INTERNAL - ON 'B' SURFACES AND NOT INTERFERE WITH PRODUCT
FUNCTION
7. TRIGGERTRAP 'TT' LOGO TO BE GLOSS FINISH ON TOP SURFACE OF LOGO. SAME SURFACE TO BE TAMPO PRINTED WITH
PANTONE 485c ( TRIGGERTRAP RED ) TO MAKE LOGO STAND OUT
8. 3 PADS TO BE GLOSS FINISH AND ZERO DRAFT
9. BOSSES TO SUIT 5 OFF M2,2 x 6,0mm PLASTITE 45 (OR EQUIVALENT) SELF TAPPING SCREWS TO SECURE PCBs
10. BOSSES TO SUIT 4 OFF M2,5 x 10,0mm PLASTITE 45 (OR EQUIVALENT) SELF TAPPING SCREWS TO FRONT CASE TO REAR CASE
11. FACE FOR ATTACHMENT OF LCD WINDOW TO BE GLOSS - OR MANUFACTURER'S PREFERENCE FOR OPTIMUM BONDING OF
TT-113 LCD SCREEN(SURFACE SHOWN AS LIGHT GREY ON PICTORIAL VIEWS)
12. FACE FOR ATTACHMENT OF TT-114 ADA KEYPAD TO BE GLOSS - OR MANUFACTURER'S PREFERENCE FOR OPTIMUM
BONDING OF SELF ADHESIVE BACKED MEMBRANE KEYPAD (SURFACE SHOWN AS LIGHT GREY ON PICTORIAL VIEWS)

ISSUE | DATE | STATUS / MODS | INTL

GENERAL NOTES:
1. DRAFT ANGLES AS SPECIFIED IN
3D MASTER MODEL
2. MOULD GATE POSITIONS TO BE
AGREED BY LAMB INDUSTRIES
3. SHARP CORNERS AND WITNESS
MARKS DUE TO TOOL INSERTS
TO BE AGREED BY LAMB
INDUSTRIES
4. ELECTRODES TO BE APPROVED
5. TOOLING DRAWINGS TO BE
6. PARTS TO BE FREE OF FLASH
AND WELD/KNIT LINES
7. NO SPRUE MARKS ON 'A'
SURFACES

IF IN DOUBT ASK.

DRAWING IS NOT FOR RELEASE TO
PARTIES OTHER THAN Triggertrap
AND THEIR APPROVED SUPPLIERS

LAMB INDUSTRIES LIMITED | 47 MIDFORD ROAD
BATH| UK | BA2 5RW
JAMES@LAMBINDUSTRIES.CO.UK

DIMENSIONS ARE IN MILLIMETERS
SURFACE FINISH:
TOLERANCES:
ANGULAR: 0.5

NAME | SIGNATURE | DATE | DRAWING IS THE COPYRIGHT OF LAMB INDUSTRIES LIMITED. DO NOT REPRODUCE WITHOUT PERMISSION | TITLE: ADA BASE FRONT CASE

DRAWN | JAMES LAMB | | --/--/--

CHK'D
APPV'D
MFG | | | | 3RD ANGLE PROJECTION
Q.A | | | | MATERIAL: SEE NOTES | DWG NO. TT-110-A_ADA_BASE_FRONT_CASE_DRG | A2

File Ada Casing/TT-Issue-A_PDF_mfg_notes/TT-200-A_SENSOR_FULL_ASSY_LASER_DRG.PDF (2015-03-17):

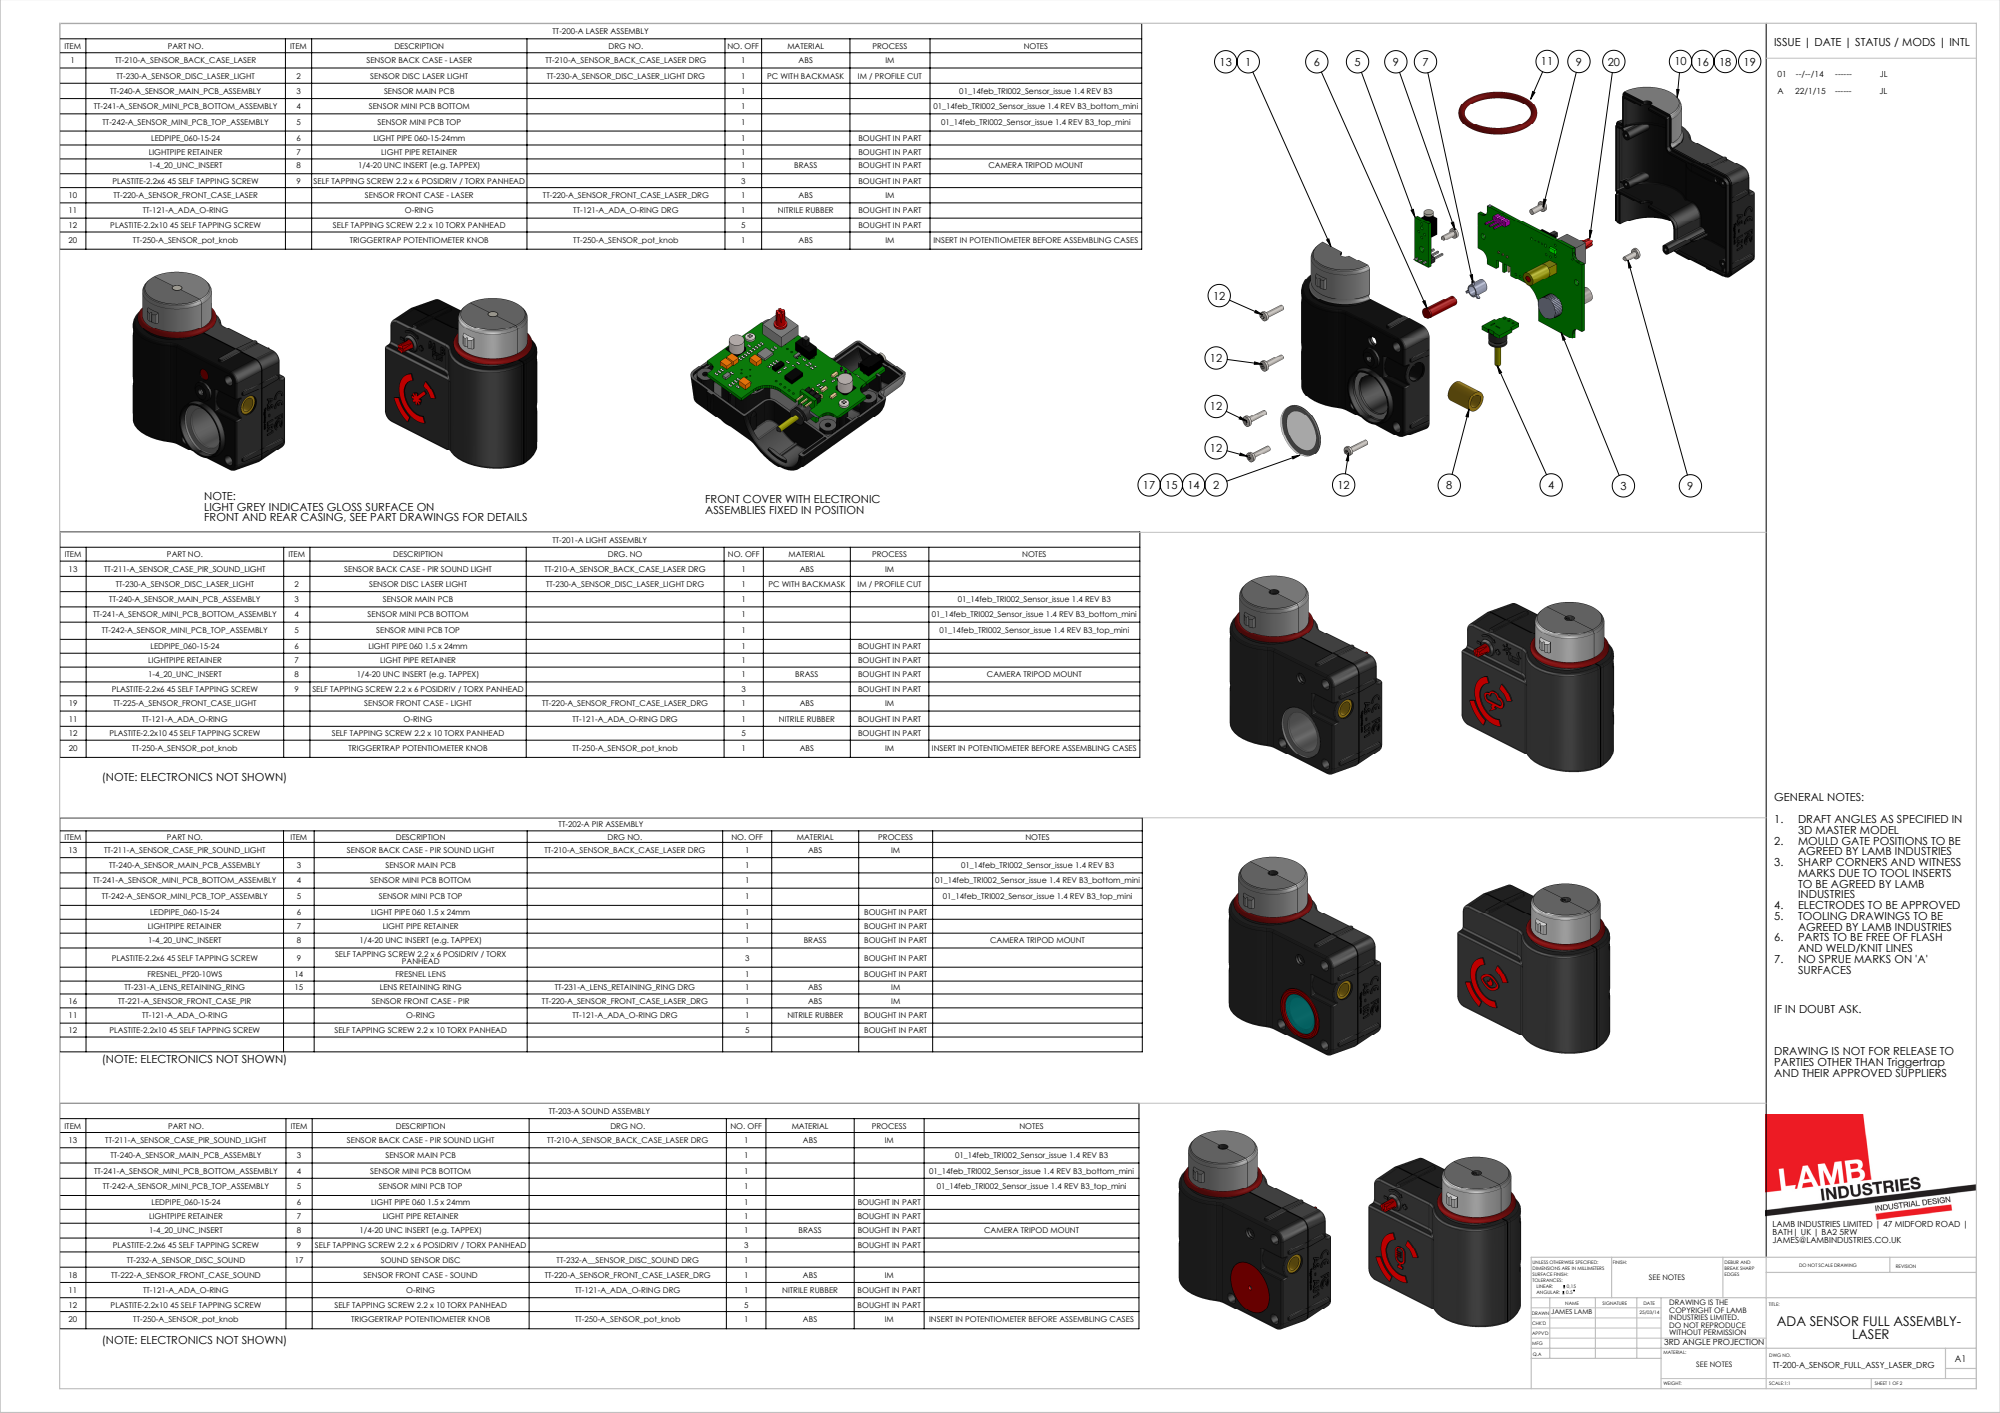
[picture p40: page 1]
PLASTITE-2.2x10 45 SELF TAPPING SCREW; SELF TAPPING SCREW 2.2 x 10 TORX PANHEAD; BOUGHT IN PART; TT-250-A_SENSOR_pot_knob; TRIGGERTRAP POTENTIOMETER KNOB; ABS; INSERT IN POTENTIOMETER BEFORE ASSEMBLING CASES; ADA SENSOR FULL ASSEMBLY-; SEE NOTES; SCALE:1:1; SHEET 1 OF 2; DO NOT SCALE DRAWING; REVISION; DEBUR AND BREAK SHARP; UNLESS OTHERWISE SPECIFIED:; FINISH:

TT-200-A LASER ASSEMBLY | | ISSUE | DATE | STATUS / MODS | INTL

ITEM | PART NO. | ITEM | DESCRIPTION | DRG NO. | NO. OFF | MATERIAL | PROCESS | NOTES
1 | TT-210-A_SENSOR_BACK_CASE_LASER | | SENSOR BACK CASE - LASER | TT-210-A_SENSOR_BACK_CASE_LASER DRG | 1 | ABS | IM

TT-230-A_SENSOR_DISC_LASER_LIGHT | 2 | SENSOR DISC LASER LIGHT | TT-230-A_SENSOR_DISC_LASER_LIGHT DRG | 1 | PC WITH BACKMASK | IM / PROFILE CUT
TT-240-A_SENSOR_MAIN_PCB_ASSEMBLY | 3 | SENSOR MAIN PCB | | 1 | | | 01_14feb_TRI002_Sensor_issue 1.4 REV B3
TT-241-A_SENSOR_MINI_PCB_BOTTOM_ASSEMBLY | 4 | SENSOR MINI PCB BOTTOM | | 1 | | | 01_14feb_TRI002_Sensor_issue 1.4 REV B3_bottom_mini
TT-242-A_SENSOR_MINI_PCB_TOP_ASSEMBLY | 5 | SENSOR MINI PCB TOP | | 1 | | | 01_14feb_TRI002_Sensor_issue 1.4 REV B3_top_mini

LEDPIPE_060-15-24 | 6 | LIGHT PIPE 060-15-24mm | | 1 | | BOUGHT IN PART
LIGHTPIPE RETAINER | 7 | LIGHT PIPE RETAINER | | 1 | | BOUGHT IN PART
1-4_20_UNC_INSERT | 8 | 1/4-20 UNC INSERT (e.g. TAPPEX) | | 1 | BRASS | BOUGHT IN PART | CAMERA TRIPOD MOUNT

PLASTITE-2.2x6 45 SELF TAPPING SCREW | 9 | SELF TAPPING SCREW 2.2 x 6 POSIDRIV / TORX PANHEAD | | 3 | | BOUGHT IN PART

10 | TT-220-A_SENSOR_FRONT_CASE_LASER | | SENSOR FRONT CASE - LASER | TT-220-A_SENSOR_FRONT_CASE_LASER_DRG | 1 | ABS | IM
11 | TT-121-A_ADA_O-RING | | O-RING | TT-121-A_ADA_O-RING DRG | 1 | NITRILE RUBBER | BOUGHT IN PART
12 | PLASTITE-2.2x10 45 SELF TAPPING SCREW | | SELF TAPPING SCREW 2.2 x 10 TORX PANHEAD | | 5 | | BOUGHT IN PART
20 | TT-250-A_SENSOR_pot_knob | | TRIGGERTRAP POTENTIOMETER KNOB | TT-250-A_SENSOR_pot_knob | 1 | ABS | IM | INSERT IN POTENTIOMETER BEFORE ASSEMBLING CASES

NOTE:
LIGHT GREY INDICATES GLOSS SURFACE ON
FRONT AND REAR CASING, SEE PART DRAWINGS FOR DETAILS

FRONT COVER WITH ELECTRONIC
ASSEMBLIES FIXED IN POSITION

TT-201-A LIGHT ASSEMBLY

ITEM | PART NO. | ITEM | DESCRIPTION | DRG. NO | NO. OFF | MATERIAL | PROCESS | NOTES
13 | TT-211-A_SENSOR_CASE_PIR_SOUND_LIGHT | | SENSOR BACK CASE - PIR SOUND LIGHT | TT-210-A_SENSOR_BACK_CASE_LASER DRG | 1 | ABS | IM

LEDPIPE_060-15-24 | 6 | LIGHT PIPE 060 1.5 x 24mm | | 1 | | BOUGHT IN PART

19 | TT-225-A_SENSOR_FRONT_CASE_LIGHT | | SENSOR FRONT CASE - LIGHT | TT-220-A_SENSOR_FRONT_CASE_LASER_DRG | 1 | ABS | IM

(NOTE: ELECTRONICS NOT SHOWN)

GENERAL NOTES:
1. DRAFT ANGLES AS SPECIFIED IN
3D MASTER MODEL
2. MOULD GATE POSITIONS TO BE
AGREED BY LAMB INDUSTRIES
3. SHARP CORNERS AND WITNESS
MARKS DUE TO TOOL INSERTS
TO BE AGREED BY LAMB
INDUSTRIES
4. ELECTRODES TO BE APPROVED
5. TOOLING DRAWINGS TO BE
6. PARTS TO BE FREE OF FLASH
AND WELD/KNIT LINES
7. NO SPRUE MARKS ON 'A'
SURFACES

TT-202-A PIR ASSEMBLY

FRESNEL_PF20-10WS | 14 | FRESNEL LENS | | 1 | | BOUGHT IN PART
TT-231-A_LENS_RETAINING_RING | 15 | LENS RETAINING RING | TT-231-A_LENS_RETAINING_RING DRG | 1 | ABS | IM

16 | TT-221-A_SENSOR_FRONT_CASE_PIR | | SENSOR FRONT CASE - PIR | TT-220-A_SENSOR_FRONT_CASE_LASER_DRG | 1 | ABS | IM

IF IN DOUBT ASK.

DRAWING IS NOT FOR RELEASE TO
PARTIES OTHER THAN Triggertrap
AND THEIR APPROVED SUPPLIERS

TT-203-A SOUND ASSEMBLY

LAMB INDUSTRIES LIMITED | 47 MIDFORD ROAD
BATH| UK | BA2 5RW
JAMES@LAMBINDUSTRIES.CO.UK

TT-232-A_SENSOR_DISC_SOUND | 17 | SOUND SENSOR DISC | TT-232-A__SENSOR_DISC_SOUND DRG | 1

DIMENSIONS ARE IN MILLIMETERS
SURFACE FINISH:
TOLERANCES:
ANGULAR: 0.5

18 | TT-222-A_SENSOR_FRONT_CASE_SOUND | | SENSOR FRONT CASE - SOUND | TT-220-A_SENSOR_FRONT_CASE_LASER_DRG | 1 | ABS | IM

DRAWING IS THE
COPYRIGHT OF LAMB
INDUSTRIES LIMITED.
DO NOT REPRODUCE
WITHOUT PERMISSION

DRAWN | JAMES LAMB | 25/03/14

CHK'D

(NOTE: ELECTRONICS NOT SHOWN) | APPV'D

MFG | | | 3RD ANGLE PROJECTION
Q.A | | | MATERIAL: SEE NOTES | DWG NO. TT-200-A_SENSOR_FULL_ASSY_LASER_DRG | A1

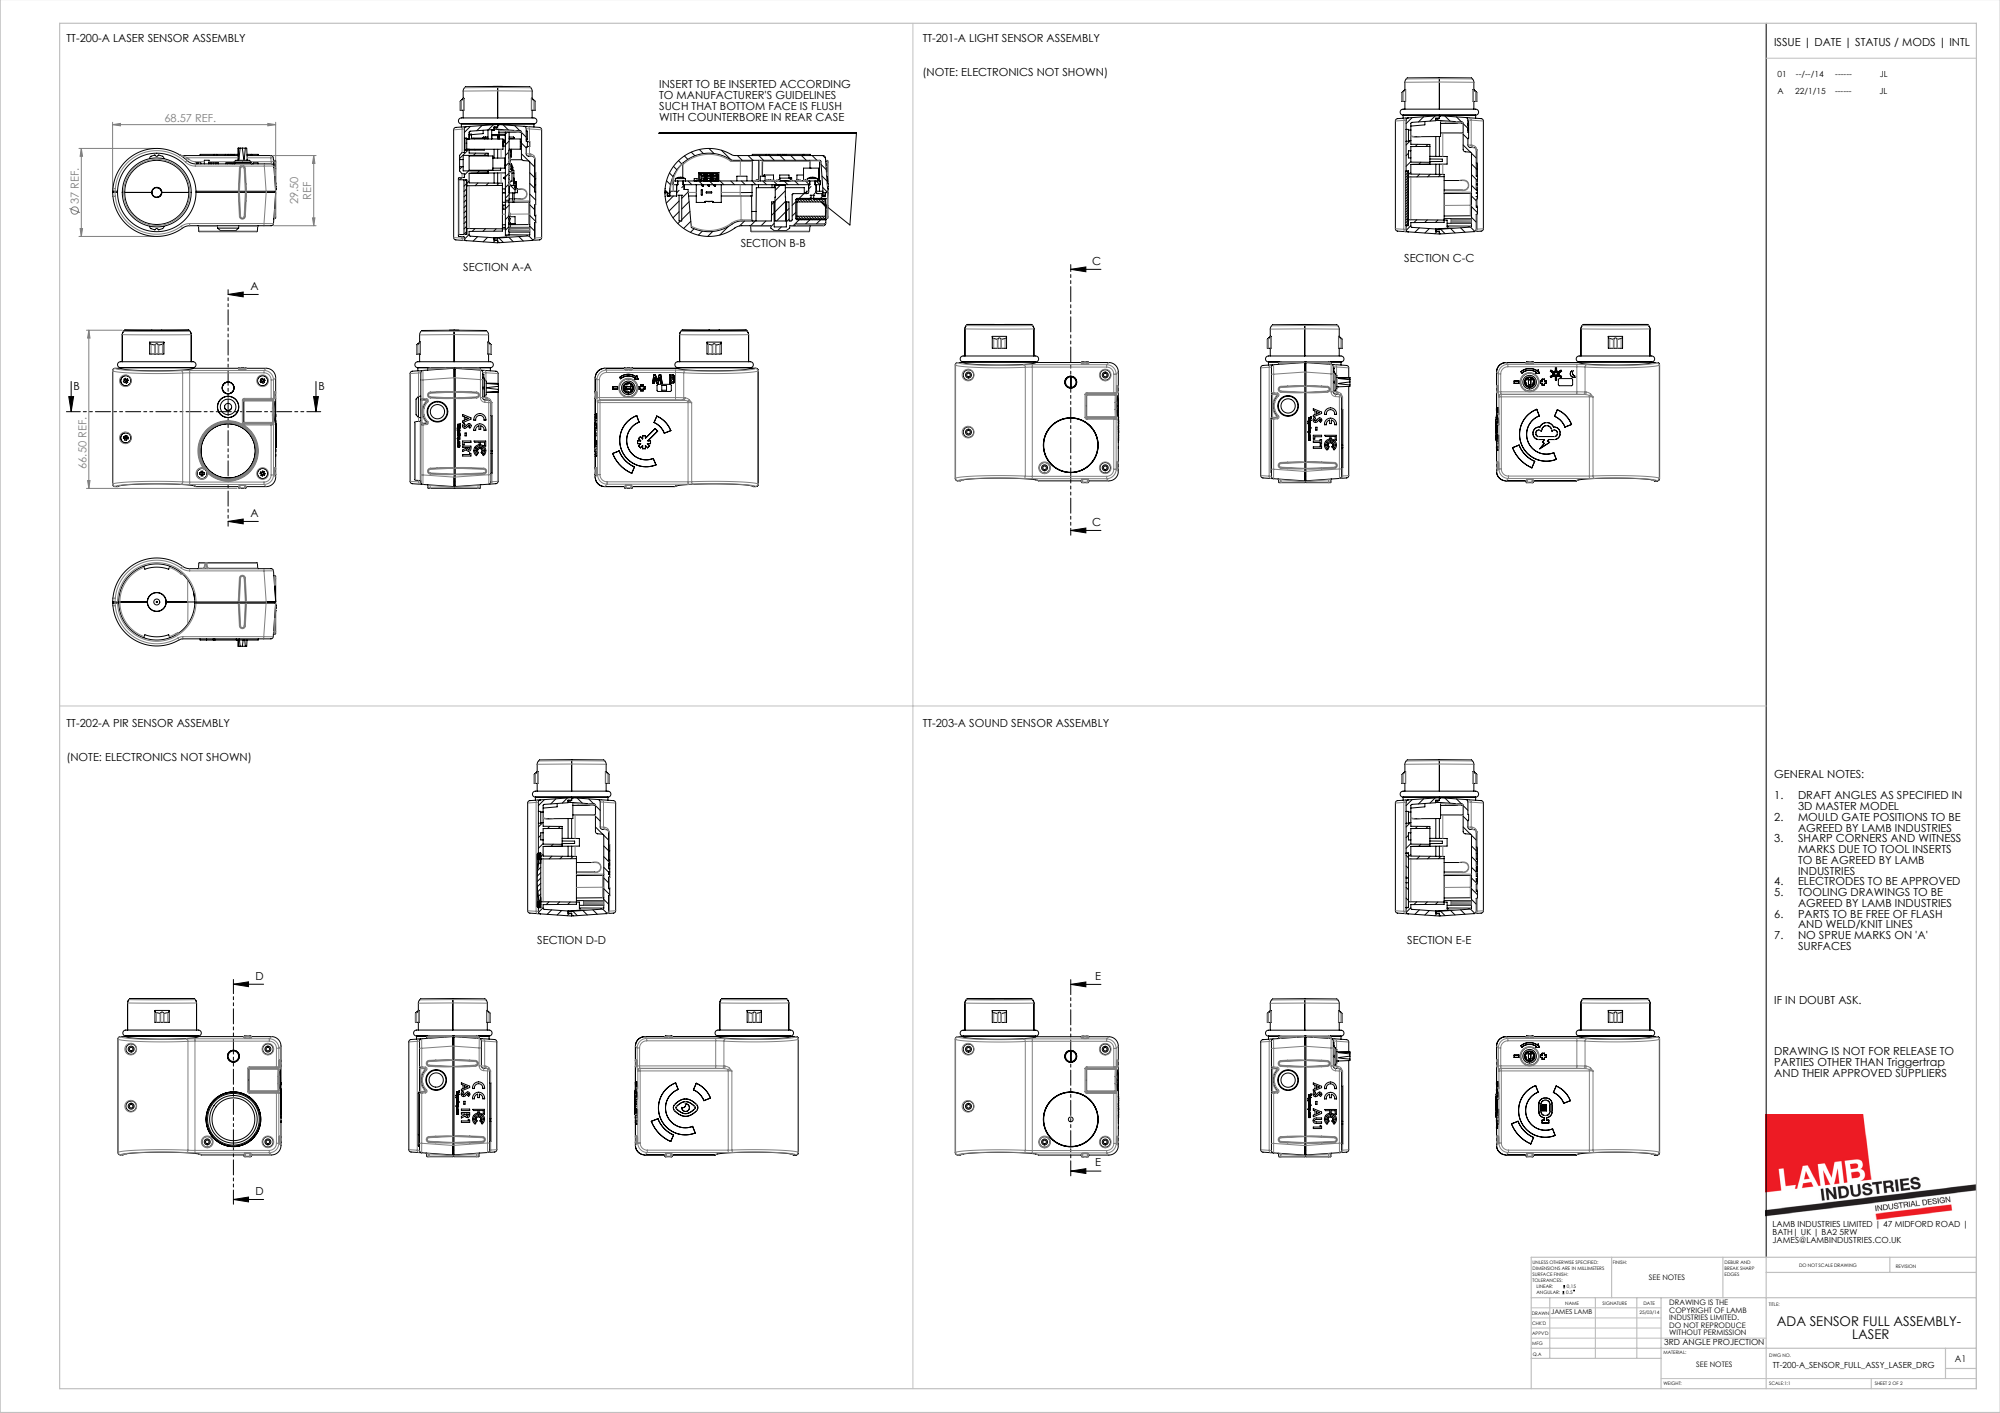
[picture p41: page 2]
66.50 REF.; 68.57 REF.; 37 REF.; SECTION A-A; SECTION B-B; SECTION C-C; SECTION D-D; SECTION E-E; TT-200-A LASER SENSOR ASSEMBLY; TT-201-A LIGHT SENSOR ASSEMBLY; TT-202-A PIR SENSOR ASSEMBLY; TT-203-A SOUND SENSOR ASSEMBLY; SEE NOTES; SCALE:1:1; SHEET 2 OF 2; DO NOT SCALE DRAWING; REVISION; DEBUR AND BREAK SHARP; UNLESS OTHERWISE SPECIFIED:; FINISH:

ISSUE | DATE | STATUS / MODS | INTL

(NOTE: ELECTRONICS NOT SHOWN)

INSERT TO BE INSERTED ACCORDING
TO MANUFACTURER'S GUIDELINES
SUCH THAT BOTTOM FACE IS FLUSH
WITH COUNTERBORE IN REAR CASE

GENERAL NOTES:
1. DRAFT ANGLES AS SPECIFIED IN
3D MASTER MODEL
2. MOULD GATE POSITIONS TO BE
AGREED BY LAMB INDUSTRIES
3. SHARP CORNERS AND WITNESS
MARKS DUE TO TOOL INSERTS
TO BE AGREED BY LAMB
INDUSTRIES
4. ELECTRODES TO BE APPROVED
5. TOOLING DRAWINGS TO BE
6. PARTS TO BE FREE OF FLASH
AND WELD/KNIT LINES
7. NO SPRUE MARKS ON 'A'
SURFACES

IF IN DOUBT ASK.

DRAWING IS NOT FOR RELEASE TO
PARTIES OTHER THAN Triggertrap
AND THEIR APPROVED SUPPLIERS

LAMB INDUSTRIES LIMITED | 47 MIDFORD ROAD
BATH| UK | BA2 5RW
JAMES@LAMBINDUSTRIES.CO.UK

DIMENSIONS ARE IN MILLIMETERS
SURFACE FINISH:
TOLERANCES:
ANGULAR: 0.5

NAME | SIGNATURE | DATE | DRAWING IS THE COPYRIGHT OF LAMB INDUSTRIES LIMITED. DO NOT REPRODUCE WITHOUT PERMISSION | TITLE: ADA SENSOR FULL ASSEMBLY-LASER

DRAWN | JAMES LAMB | | 25/03/14

CHK'D
APPV'D
MFG | | | | 3RD ANGLE PROJECTION
Q.A | | | | MATERIAL: SEE NOTES | DWG NO. TT-200-A_SENSOR_FULL_ASSY_LASER_DRG | A1

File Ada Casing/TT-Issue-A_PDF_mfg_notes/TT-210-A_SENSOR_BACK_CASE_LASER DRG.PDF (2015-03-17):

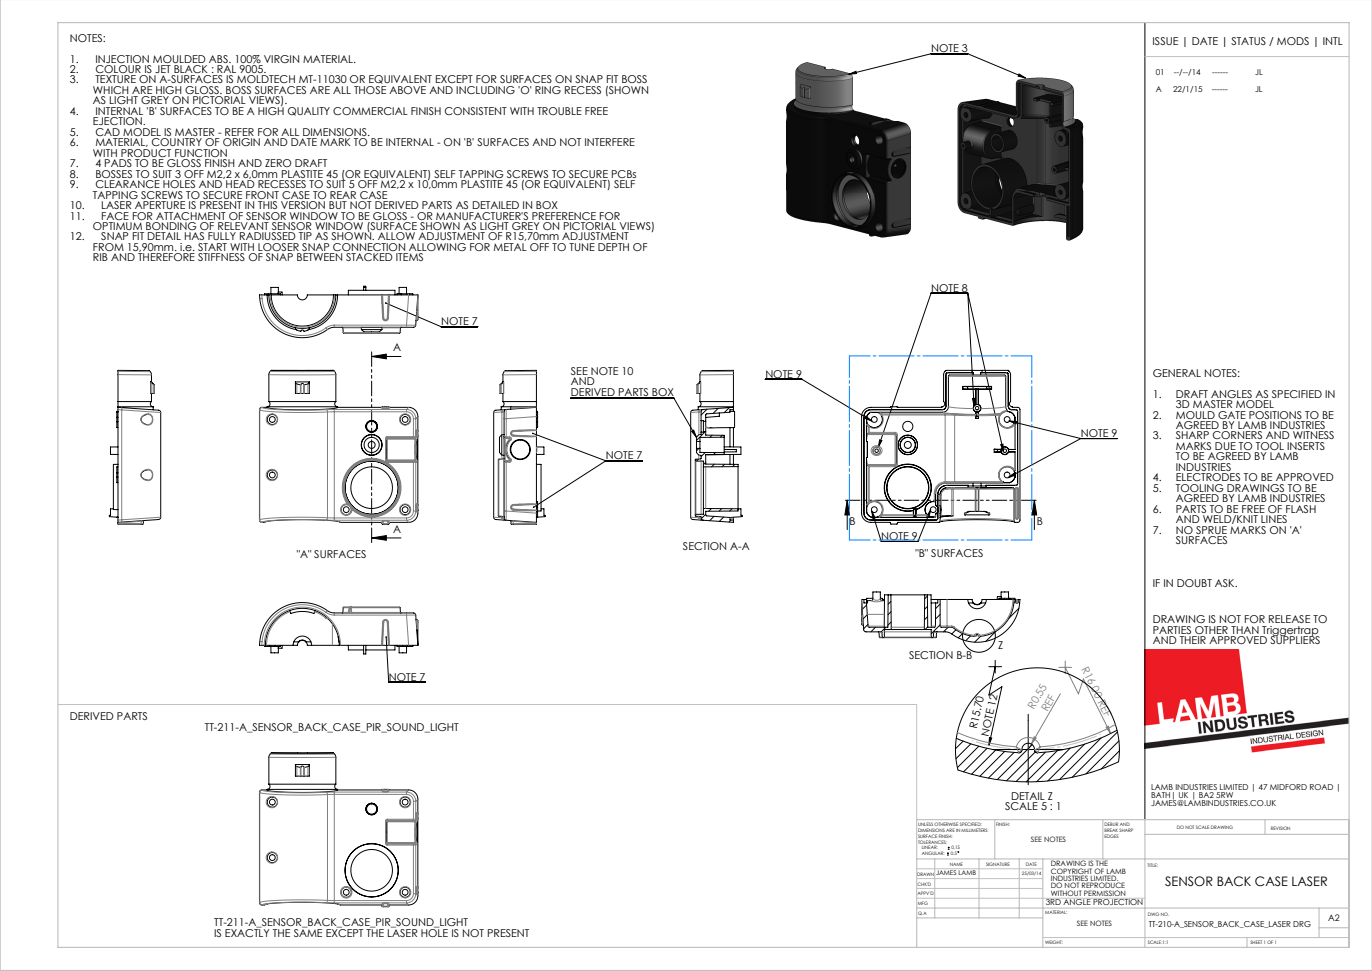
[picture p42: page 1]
"A" SURFACES; NOTE 7; "B" SURFACES; NOTE 8; NOTE 9; NOTE 3; SECTION A-A; SECTION B-B; R16.00 REF; NOTE 12; DETAIL Z SCALE 5 : 1; DERIVED PARTS; SEE NOTES; SCALE:1:1; SHEET 1 OF 1; DO NOT SCALE DRAWING; REVISION; DEBUR AND BREAK SHARP; UNLESS OTHERWISE SPECIFIED:; FINISH:

NOTES:
1. INJECTION MOULDED ABS. 100% VIRGIN MATERIAL.
2. COLOUR IS JET BLACK : RAL 9005.
3. TEXTURE ON A-SURFACES IS MOLDTECH MT-11030 OR EQUIVALENT EXCEPT FOR SURFACES ON SNAP FIT BOSS
WHICH ARE HIGH GLOSS. BOSS SURFACES ARE ALL THOSE ABOVE AND INCLUDING 'O' RING RECESS (SHOWN
AS LIGHT GREY ON PICTORIAL VIEWS).
4. INTERNAL 'B' SURFACES TO BE A HIGH QUALITY COMMERCIAL FINISH CONSISTENT WITH TROUBLE FREE
EJECTION.
5. CAD MODEL IS MASTER - REFER FOR ALL DIMENSIONS.
6. MATERIAL, COUNTRY OF ORIGIN AND DATE MARK TO BE INTERNAL - ON 'B' SURFACES AND NOT INTERFERE
WITH PRODUCT FUNCTION
7. 4 PADS TO BE GLOSS FINISH AND ZERO DRAFT
8. BOSSES TO SUIT 3 OFF M2,2 x 6,0mm PLASTITE 45 (OR EQUIVALENT) SELF TAPPING SCREWS TO SECURE PCBs
9. CLEARANCE HOLES AND HEAD RECESSES TO SUIT 5 OFF M2,2 x 10,0mm PLASTITE 45 (OR EQUIVALENT) SELF
TAPPING SCREWS TO SECURE FRONT CASE TO REAR CASE
10. LASER APERTURE IS PRESENT IN THIS VERSION BUT NOT DERIVED PARTS AS DETAILED IN BOX
11. FACE FOR ATTACHMENT OF SENSOR WINDOW TO BE GLOSS - OR MANUFACTURER'S PREFERENCE FOR
OPTIMUM BONDING OF RELEVANT SENSOR WINDOW (SURFACE SHOWN AS LIGHT GREY ON PICTORIAL VIEWS)
12. SNAP FIT DETAIL HAS FULLY RADIUSSED TIP AS SHOWN. ALLOW ADJUSTMENT OF R15,70mm ADJUSTMENT
FROM 15,90mm. i.e. START WITH LOOSER SNAP CONNECTION ALLOWING FOR METAL OFF TO TUNE DEPTH OF
RIB AND THEREFORE STIFFNESS OF SNAP BETWEEN STACKED ITEMS

ISSUE | DATE | STATUS / MODS | INTL

SEE NOTE 10
AND
DERIVED PARTS BOX

GENERAL NOTES:
1. DRAFT ANGLES AS SPECIFIED IN
3D MASTER MODEL
2. MOULD GATE POSITIONS TO BE
AGREED BY LAMB INDUSTRIES
3. SHARP CORNERS AND WITNESS
MARKS DUE TO TOOL INSERTS
TO BE AGREED BY LAMB
INDUSTRIES
4. ELECTRODES TO BE APPROVED
5. TOOLING DRAWINGS TO BE
6. PARTS TO BE FREE OF FLASH
AND WELD/KNIT LINES
7. NO SPRUE MARKS ON 'A'
SURFACES

IF IN DOUBT ASK.

DRAWING IS NOT FOR RELEASE TO
PARTIES OTHER THAN Triggertrap
AND THEIR APPROVED SUPPLIERS

LAMB INDUSTRIES LIMITED | 47 MIDFORD ROAD
BATH| UK | BA2 5RW
JAMES@LAMBINDUSTRIES.CO.UK

DIMENSIONS ARE IN MILLIMETERS
SURFACE FINISH:
TOLERANCES:
ANGULAR: 0.5

NAME | SIGNATURE | DATE | DRAWING IS THE COPYRIGHT OF LAMB INDUSTRIES LIMITED. DO NOT REPRODUCE WITHOUT PERMISSION | TITLE: SENSOR BACK CASE LASER

DRAWN | JAMES LAMB | | 25/03/14

CHK'D
APPV'D
MFG | | | | 3RD ANGLE PROJECTION
Q.A | | | | MATERIAL: SEE NOTES | DWG NO. TT-210-A_SENSOR_BACK_CASE_LASER DRG | A2

TT-211-A_SENSOR_BACK_CASE_PIR_SOUND_LIGHT
IS EXACTLY THE SAME EXCEPT THE LASER HOLE IS NOT PRESENT

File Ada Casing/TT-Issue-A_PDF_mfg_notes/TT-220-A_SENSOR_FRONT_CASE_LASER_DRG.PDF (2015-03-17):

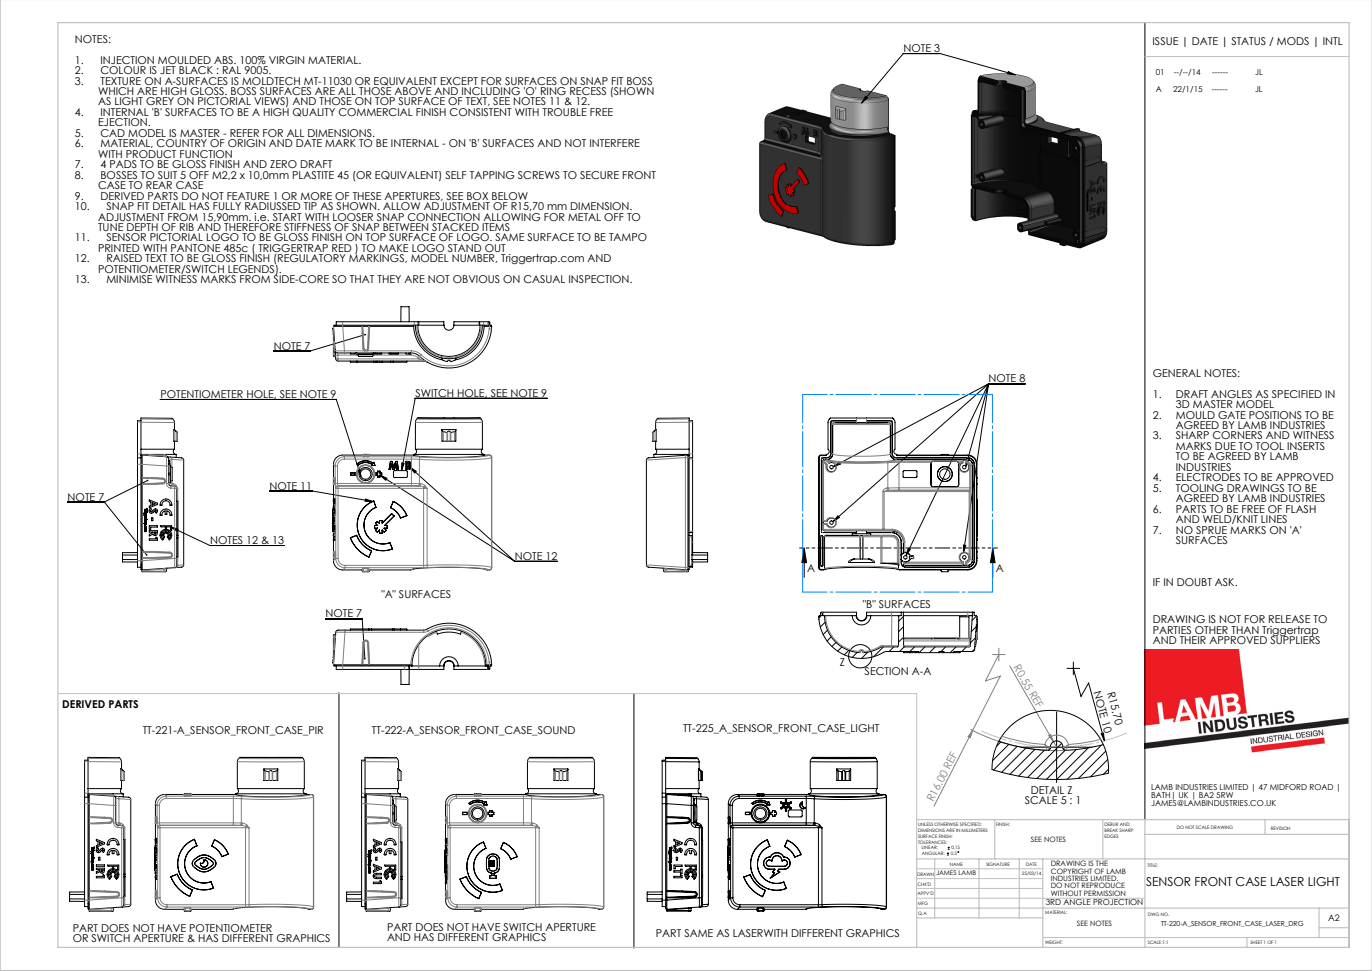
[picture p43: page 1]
"A" SURFACES; POTENTIOMETER HOLE, SEE NOTE 9; SWITCH HOLE, SEE NOTE 9; NOTE 11; NOTE 12; NOTE 7; NOTES 12 & 13; "B" SURFACES; NOTE 8; NOTE 3; SECTION A-A; R0.55 REF; R16.00 REF; NOTE 10; DETAIL Z SCALE 5 : 1; SEE NOTES; DO NOT SCALE DRAWING; REVISION; DEBUR AND BREAK SHARP; UNLESS OTHERWISE SPECIFIED:; FINISH:

NOTES:
1. INJECTION MOULDED ABS. 100% VIRGIN MATERIAL.
2. COLOUR IS JET BLACK : RAL 9005.
3. TEXTURE ON A-SURFACES IS MOLDTECH MT-11030 OR EQUIVALENT EXCEPT FOR SURFACES ON SNAP FIT BOSS
WHICH ARE HIGH GLOSS. BOSS SURFACES ARE ALL THOSE ABOVE AND INCLUDING 'O' RING RECESS (SHOWN
AS LIGHT GREY ON PICTORIAL VIEWS) AND THOSE ON TOP SURFACE OF TEXT, SEE NOTES 11 & 12.
4. INTERNAL 'B' SURFACES TO BE A HIGH QUALITY COMMERCIAL FINISH CONSISTENT WITH TROUBLE FREE
EJECTION.
5. CAD MODEL IS MASTER - REFER FOR ALL DIMENSIONS.
6. MATERIAL, COUNTRY OF ORIGIN AND DATE MARK TO BE INTERNAL - ON 'B' SURFACES AND NOT INTERFERE
WITH PRODUCT FUNCTION
7. 4 PADS TO BE GLOSS FINISH AND ZERO DRAFT
8. BOSSES TO SUIT 5 OFF M2,2 x 10,0mm PLASTITE 45 (OR EQUIVALENT) SELF TAPPING SCREWS TO SECURE FRONT
CASE TO REAR CASE
9. DERIVED PARTS DO NOT FEATURE 1 OR MORE OF THESE APERTURES, SEE BOX BELOW
10. SNAP FIT DETAIL HAS FULLY RADIUSSED TIP AS SHOWN. ALLOW ADJUSTMENT OF R15,70 mm DIMENSION.
ADJUSTMENT FROM 15,90mm. i.e. START WITH LOOSER SNAP CONNECTION ALLOWING FOR METAL OFF TO
TUNE DEPTH OF RIB AND THEREFORE STIFFNESS OF SNAP BETWEEN STACKED ITEMS
11. SENSOR PICTORIAL LOGO TO BE GLOSS FINISH ON TOP SURFACE OF LOGO. SAME SURFACE TO BE TAMPO
PRINTED WITH PANTONE 485c ( TRIGGERTRAP RED ) TO MAKE LOGO STAND OUT
12. RAISED TEXT TO BE GLOSS FINISH (REGULATORY MARKINGS, MODEL NUMBER, Triggertrap.com AND
POTENTIOMETER/SWITCH LEGENDS).
13. MINIMISE WITNESS MARKS FROM SIDE-CORE SO THAT THEY ARE NOT OBVIOUS ON CASUAL INSPECTION.

ISSUE | DATE | STATUS / MODS | INTL

GENERAL NOTES:
1. DRAFT ANGLES AS SPECIFIED IN
3D MASTER MODEL
2. MOULD GATE POSITIONS TO BE
AGREED BY LAMB INDUSTRIES
3. SHARP CORNERS AND WITNESS
MARKS DUE TO TOOL INSERTS
TO BE AGREED BY LAMB
INDUSTRIES
4. ELECTRODES TO BE APPROVED
5. TOOLING DRAWINGS TO BE
6. PARTS TO BE FREE OF FLASH
AND WELD/KNIT LINES
7. NO SPRUE MARKS ON 'A'
SURFACES

IF IN DOUBT ASK.

DRAWING IS NOT FOR RELEASE TO
PARTIES OTHER THAN Triggertrap
AND THEIR APPROVED SUPPLIERS

DERIVED PARTS TT-221-A_SENSOR_FRONT_CASE_PIR PART DOES NOT HAVE POTENTIOMETER OR SWITCH APERTURE & HAS DIFFERENT GRAPHICS | TT-222-A_SENSOR_FRONT_CASE_SOUND PART DOES NOT HAVE SWITCH APERTURE AND HAS DIFFERENT GRAPHICS | TT-225_A_SENSOR_FRONT_CASE_LIGHT PART SAME AS LASERWITH DIFFERENT GRAPHICS

LAMB INDUSTRIES LIMITED | 47 MIDFORD ROAD
BATH| UK | BA2 5RW
JAMES@LAMBINDUSTRIES.CO.UK

DIMENSIONS ARE IN MILLIMETERS
SURFACE FINISH:
TOLERANCES:
ANGULAR: 0.5

NAME | SIGNATURE | DATE | DRAWING IS THE COPYRIGHT OF LAMB INDUSTRIES LIMITED. DO NOT REPRODUCE WITHOUT PERMISSION | TITLE: SENSOR FRONT CASE LASER LIGHT

DRAWN | JAMES LAMB | | 25/03/14

CHK'D
APPV'D
MFG | | | | 3RD ANGLE PROJECTION
Q.A | | | | MATERIAL: SEE NOTES | DWG NO. TT-220-A_SENSOR_FRONT_CASE_LASER_DRG | A2

WEIGHT: | SCALE:1:1 | SHEET 1 OF 1

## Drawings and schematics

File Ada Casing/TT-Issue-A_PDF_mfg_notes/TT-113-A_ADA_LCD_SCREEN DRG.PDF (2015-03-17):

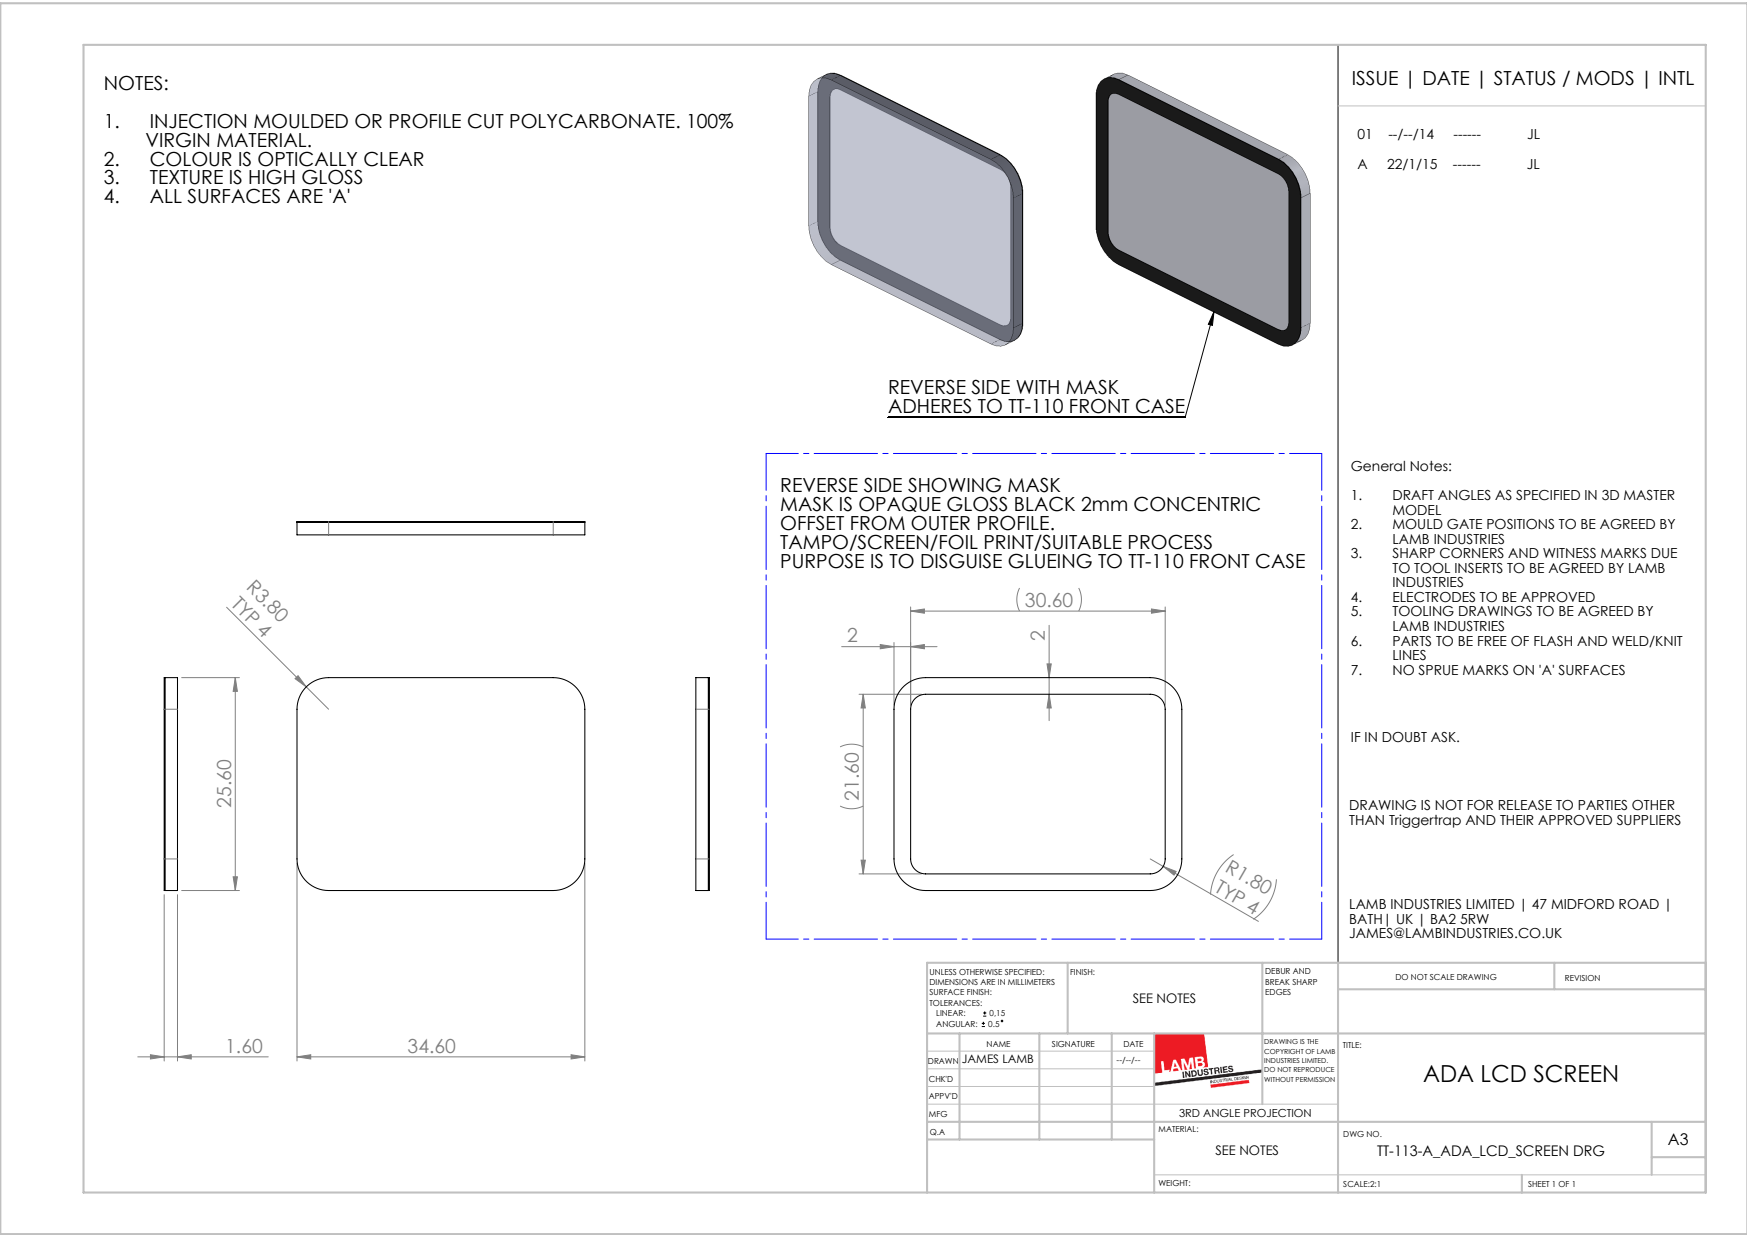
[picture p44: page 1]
TYP 4; SEE NOTES; SCALE:2:1; SHEET 1 OF 1; DO NOT SCALE DRAWING; REVISION; DEBUR AND BREAK SHARP; UNLESS OTHERWISE SPECIFIED:; FINISH:

NOTES:
1. INJECTION MOULDED OR PROFILE CUT POLYCARBONATE. 100%
VIRGIN MATERIAL.
2. COLOUR IS OPTICALLY CLEAR
3. TEXTURE IS HIGH GLOSS
4. ALL SURFACES ARE 'A'

ISSUE | DATE | STATUS / MODS | INTL

REVERSE SIDE WITH MASK
ADHERES TO TT-110 FRONT CASE

General Notes:
1. DRAFT ANGLES AS SPECIFIED IN 3D MASTER
MODEL
2. MOULD GATE POSITIONS TO BE AGREED BY
LAMB INDUSTRIES
3. SHARP CORNERS AND WITNESS MARKS DUE
TO TOOL INSERTS TO BE AGREED BY LAMB
INDUSTRIES
4. ELECTRODES TO BE APPROVED
5. TOOLING DRAWINGS TO BE AGREED BY
6. PARTS TO BE FREE OF FLASH AND WELD/KNIT
LINES
7. NO SPRUE MARKS ON 'A' SURFACES

REVERSE SIDE SHOWING MASK
MASK IS OPAQUE GLOSS BLACK 2mm CONCENTRIC
OFFSET FROM OUTER PROFILE.
TAMPO/SCREEN/FOIL PRINT/SUITABLE PROCESS
PURPOSE IS TO DISGUISE GLUEING TO TT-110 FRONT CASE

IF IN DOUBT ASK.

DRAWING IS NOT FOR RELEASE TO PARTIES OTHER
THAN Triggertrap AND THEIR APPROVED SUPPLIERS

LAMB INDUSTRIES LIMITED | 47 MIDFORD ROAD
BATH| UK | BA2 5RW
JAMES@LAMBINDUSTRIES.CO.UK

DIMENSIONS ARE IN MILLIMETERS
SURFACE FINISH:
TOLERANCES:
ANGULAR: 0.5

NAME | SIGNATURE | DATE | | DRAWING IS THE COPYRIGHT OF LAMB INDUSTRIES LIMITED. DO NOT REPRODUCE WITHOUT PERMISSION | TITLE: ADA LCD SCREEN

DRAWN | JAMES LAMB | | --/--/--

CHK'D
APPV'D
MFG | | | | 3RD ANGLE PROJECTION
Q.A | | | | MATERIAL: SEE NOTES | DWG NO. TT-113-A_ADA_LCD_SCREEN DRG | A3

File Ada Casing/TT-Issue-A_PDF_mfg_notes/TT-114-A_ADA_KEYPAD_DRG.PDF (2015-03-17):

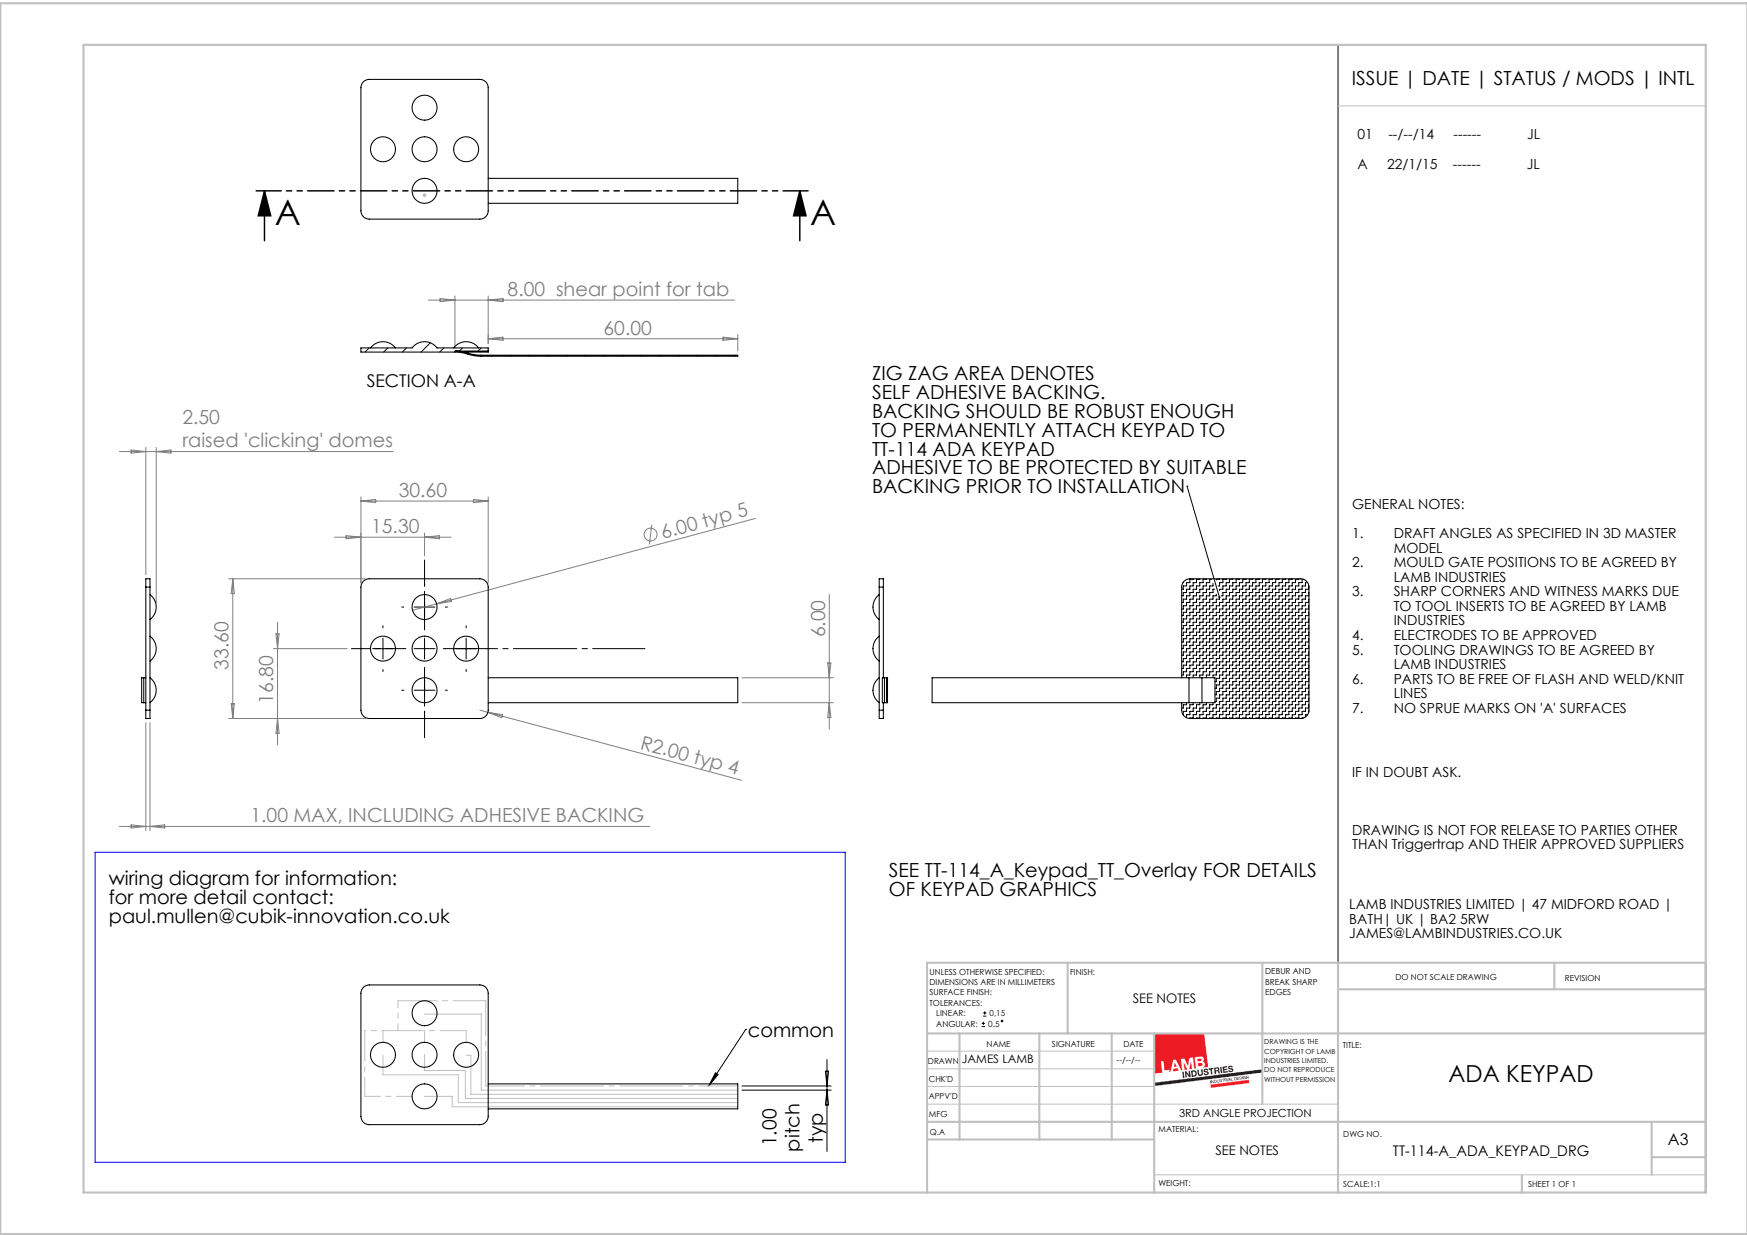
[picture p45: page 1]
R2.00 typ 4; 6.00 typ 5; SECTION A-A; ZIG ZAG AREA DENOTES; SEE NOTES; SCALE:1:1; SHEET 1 OF 1; DO NOT SCALE DRAWING; REVISION; DEBUR AND BREAK SHARP; UNLESS OTHERWISE SPECIFIED:; FINISH:

ISSUE | DATE | STATUS / MODS | INTL

8.00 shear point for tab

SELF ADHESIVE BACKING.
BACKING SHOULD BE ROBUST ENOUGH
TO PERMANENTLY ATTACH KEYPAD TO
TT-114 ADA KEYPAD
ADHESIVE TO BE PROTECTED BY SUITABLE
BACKING PRIOR TO INSTALLATION

raised 'clicking' domes

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

IF IN DOUBT ASK.

1.00 MAX, INCLUDING ADHESIVE BACKING

DRAWING IS NOT FOR RELEASE TO PARTIES OTHER
THAN Triggertrap AND THEIR APPROVED SUPPLIERS

SEE TT-114_A_Keypad_TT_Overlay FOR DETAILS
OF KEYPAD GRAPHICS

wiring diagram for information:
for more detail contact:
paul.mullen@cubik-innovation.co.uk

LAMB INDUSTRIES LIMITED | 47 MIDFORD ROAD
BATH| UK | BA2 5RW
JAMES@LAMBINDUSTRIES.CO.UK

DIMENSIONS ARE IN MILLIMETERS
SURFACE FINISH:
TOLERANCES:
ANGULAR: 0.5

NAME | SIGNATURE | DATE | | DRAWING IS THE COPYRIGHT OF LAMB INDUSTRIES LIMITED. DO NOT REPRODUCE WITHOUT PERMISSION | TITLE: ADA KEYPAD

DRAWN | JAMES LAMB | | --/--/--

CHK'D
APPV'D
MFG | | | | 3RD ANGLE PROJECTION
Q.A | | | | MATERIAL: SEE NOTES | DWG NO. TT-114-A_ADA_KEYPAD_DRG | A3

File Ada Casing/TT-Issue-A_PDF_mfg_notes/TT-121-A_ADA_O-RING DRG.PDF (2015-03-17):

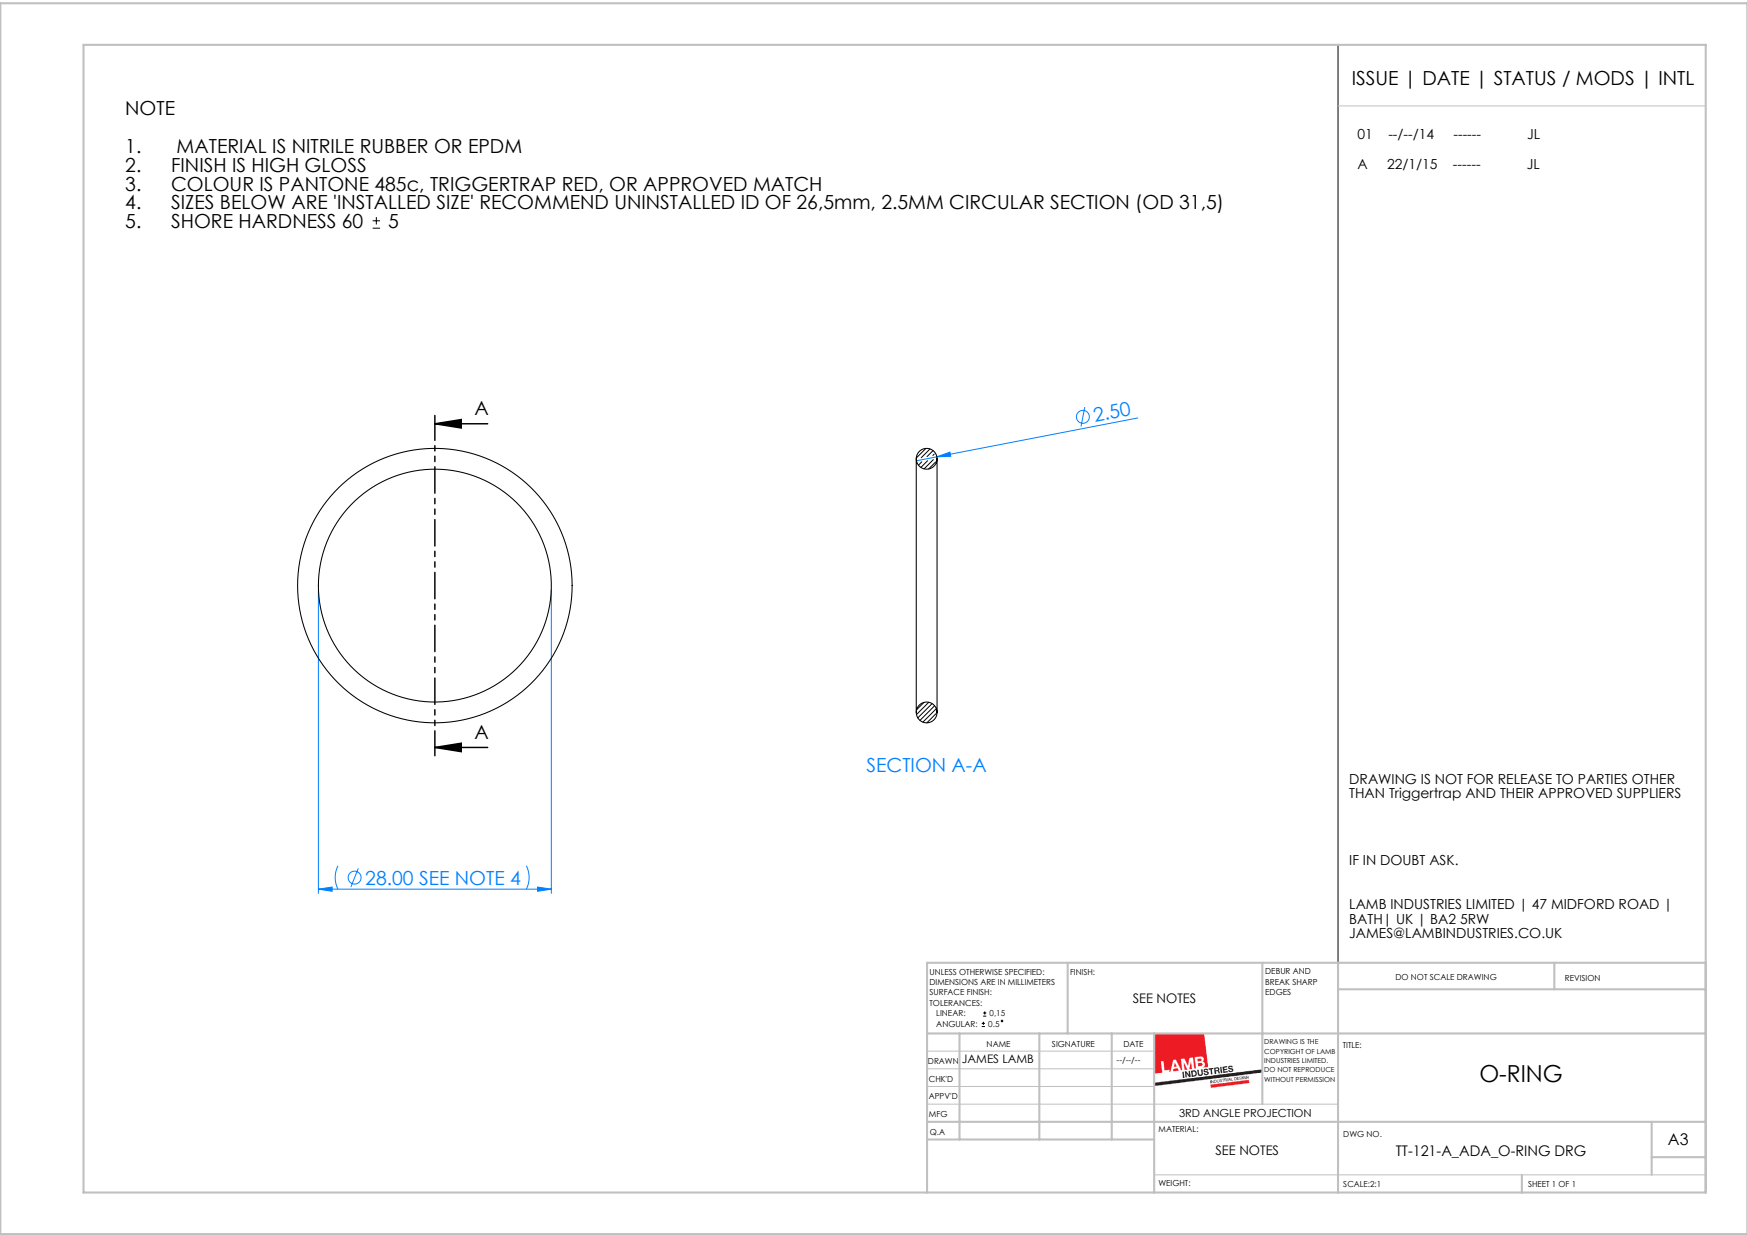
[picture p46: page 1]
28.00 SEE NOTE 4; SECTION A-A; 5. SHORE HARDNESS 60; SEE NOTES; SCALE:2:1; SHEET 1 OF 1; DO NOT SCALE DRAWING; REVISION; DEBUR AND BREAK SHARP; UNLESS OTHERWISE SPECIFIED:; FINISH:

ISSUE | DATE | STATUS / MODS | INTL

NOTE
1. MATERIAL IS NITRILE RUBBER OR EPDM
2. FINISH IS HIGH GLOSS
3. COLOUR IS PANTONE 485c, TRIGGERTRAP RED, OR APPROVED MATCH
4. SIZES BELOW ARE 'INSTALLED SIZE' RECOMMEND UNINSTALLED ID OF 26,5mm, 2.5MM CIRCULAR SECTION (OD 31,5)

DRAWING IS NOT FOR RELEASE TO PARTIES OTHER
THAN Triggertrap AND THEIR APPROVED SUPPLIERS

IF IN DOUBT ASK.

LAMB INDUSTRIES LIMITED | 47 MIDFORD ROAD
BATH| UK | BA2 5RW
JAMES@LAMBINDUSTRIES.CO.UK

DIMENSIONS ARE IN MILLIMETERS
SURFACE FINISH:
TOLERANCES:
ANGULAR: 0.5

NAME | SIGNATURE | DATE | | DRAWING IS THE COPYRIGHT OF LAMB INDUSTRIES LIMITED. DO NOT REPRODUCE WITHOUT PERMISSION | TITLE: O-RING

DRAWN | JAMES LAMB | | --/--/--

CHK'D
APPV'D
MFG | | | | 3RD ANGLE PROJECTION
Q.A | | | | MATERIAL: SEE NOTES | DWG NO. TT-121-A_ADA_O-RING DRG | A3

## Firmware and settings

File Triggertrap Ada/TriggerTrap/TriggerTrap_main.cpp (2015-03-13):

#include "pins_arduino.h"
#include <avr/sleep.h>
#include "HardwareGlobals.h"
#include "Inputs.h"
	
#include "HighSpeedFlash.h"
#include "guimenu.h"

#include "MenuDefines.h"
#include "Menu.h"
#include "EEPROM.h"
#include "eeprom_addresses.h"
#include <avr/io.h>
#include <avr/interrupt.h>
#include <util/delay.h>
#include "Wire.h"
#include <stdlib.h>
#include <avr/power.h>


extern "C" 
{
	#include "TC_driver.h"
}



void(* reset) (void) = 0;			//declare reset function at address 0
void MenuUpdate(void);
void store_default_units_value (uint8_t address, uint16_t store_value, uint8_t units);
void start_lcd (uint8_t initial_contrast);
void HighSysClock (void);
void LowSysClock (void);
void WriteEEPROMSettingsDefaults (void);

extern MENU_NEXTSTATE menu_nextstate[];
extern MENU_STATE menu_state[];

#define DEFAULT_LCD_CONTRAST		50

bool Low_Battery_Flag = false;
int MenuSelect = 0, buttonState = 0, MenuLines = 0, MenuLinesTotal = 3, Toggle = 1, Sensor_Timelapse_Flag = 0;
int SelectedStartDelay = 1, Interval = 1, SelectedCount = 2, Infinite = 0, SenDisabled = 0, TimeLapseDisabled = 0, SenTimeDisabled = 0;
int ReTriggerDelay = 1, SetupDelay = 1, TLMobileInputEnabled = 0, SMobileInputEnabled = 0, SMobileOutputEnabled = 0, TLMobileOutputEnabled = 0;
unsigned char SenTimeHourActive, SenTimeMinActive, SenTimeHourOff, SenTimeMinOff, TimeLapseHourActive, TimeLapseMinActive, TimeLapseHourOff, TimeLapseMinOff, SenHourActive, SenMinActive, SenHourOff, SenMinOff;
unsigned char GLOBFlashDelayLow, GLOBFlashDelayHigh, GLOBFocusDelayLow, GLOBFocusDelayHigh, GLOBShutterPlseDelayLow, GLOBShutterPlseDelayHigh;
unsigned int GLOBFlashPulseDelay, GLOBPreFocusDelay, GLOBShutterPulseDelay;


char input;
unsigned volatile char nextstate, state;
char (*pStateFunc)(char);
volatile int TOGGLE = 1;


	
	
int ButtonPoll(int);
void start_lcd (uint8_t initial_contrast)
{
	uint8_t Contrast_set = EEPROM.read (EEPROM_LCD_CONTRAST_SET);
	uint8_t Contrast = initial_contrast;
	
	
	guimenu_initialise (initial_contrast, get_time, set_time);
	
	while (Contrast_set == 0xFF)
	{
		guimenu_clearpage();
		guimenu_println ("ADJUST SCREEN CONTRAST");
				
		
		if (!digitalRead (UpButton))
		{
			Contrast++;
		}
		else if (!digitalRead (DownButton))
		{
			Contrast--;
		}
		else if (!digitalRead (SelectButton))
		{
			Contrast_set = 0;
			EEPROM.write (EEPROM_LCD_CONTRAST_SET, 0);
			EEPROM.write (EEPROM_LCD_CONTRAST, Contrast);
			guimenu_clearpage();
			guimenu_println ("CONTRAST SET");
			guimenu_updatepage();
			
			WriteEEPROMSettingsDefaults();
		}
		
		if (Contrast >= 100)
		{
			Contrast = 100;
		}
		else if (Contrast <= 0)
		{
			Contrast = 0;
		}

		guimenu_setcontrast (Contrast);
		guimenu_updatepage();
		delay(250);
	}
	
	Contrast = EEPROM.read(EEPROM_LCD_CONTRAST);
	guimenu_setcontrast (Contrast);
	guimenu_updatepage();
}


void WriteEEPROMSettingsDefaults (void)
{
	//timelapse defaults
	EEPROM.write(EEPROM_TIMELAPSE_COUNT_HI, 0x27);		// Defaults to INFINITE,
	EEPROM.write(EEPROM_TIMELAPSE_COUNT_LO, 0x11);		// Defaults to INFINITE,

	EEPROM.write(EEPROM_TIMELAPSE_STARTHOURS, 0x00);		// Defaults to 0
	EEPROM.write(EEPROM_TIMELAPSE_STARTMINS, 0x00);		// Defaults to 0
	EEPROM.write(EEPROM_TIMELAPSE_ENDHOURS, 0x00);		// Defaults to 0
	EEPROM.write(EEPROM_TIMELAPSE_ENDMINS, 0x00);		// Defaults to 0
	EEPROM.write(EEPROM_TIMELAPSE_INTERVAL_HI, 0x00);		//
	EEPROM.write(EEPROM_TIMELAPSE_INTERVAL_LO, 0x01);		//
	EEPROM.write(EEPROM_TIMELAPSE_INTERVAL_UNITS, GUIMENU_UNITS_S);		// Defaults to 1 sec
	EEPROM.write(EEPROM_TIMELAPSE_STARTDELAY_HI, 0x00);		// Defaults to 0
	EEPROM.write(EEPROM_TIMELAPSE_STARTDELAY_LO, 0x00);		// Defaults to 0
	EEPROM.write(EEPROM_TIMELAPSE_STARTDELAY_UNITS, GUIMENU_UNITS_S);		// Defaults to 0
	EEPROM.write(EEPROM_TIMELAPSE_ACTIVE, 0x01);		// Defaults to always

	EEPROM.write(EEPROM_TIMEWARP_WAIT_HI, 0x00);		//
	EEPROM.write(EEPROM_TIMEWARP_WAIT_LO, 0x00);		//
	EEPROM.write(EEPROM_TIMEWARP_WAIT_UNITS, GUIMENU_UNITS_M);		//

	//timewarp defaults
	EEPROM.write(EEPROM_TIMEWARP_DURATION_HI, 0x00);		//
	EEPROM.write(EEPROM_TIMEWARP_DURATION_LO, 0x01);		// Defaults to 1 hour
	EEPROM.write(EEPROM_TIMEWARP_DURATION_UNITS, GUIMENU_UNITS_H);

	EEPROM.write(EEPROM_TIMEWARP_COUNT_HI, 0x00);		// set to 0
	EEPROM.write(EEPROM_TIMEWARP_COUNT_LO, 0x64);		// set 100

	EEPROM.write(EEPROM_TIMEWARP_FUNCTION, 0x00); // Defaults to Quadratic

	EEPROM.write(EEPROM_TIMEWARP_WAIT_HI, 0x00);		// Defaults to 0
	EEPROM.write(EEPROM_TIMEWARP_WAIT_LO, 0x00);		// Defaults to 0
	EEPROM.write(EEPROM_TIMEWARP_WAIT_UNITS, GUIMENU_UNITS_M);		// Defaults to 0

	EEPROM.write(EEPROM_TIMEWARP_DIRECTION, EASE_INOUT);		// Defaults to in-out

	//settings defaults
	EEPROM.write(EEPROM_CAMERAPREFOCUS_HI, 0x00);// Defaults to 0 seconds
	EEPROM.write(EEPROM_CAMERAPREFOCUS_LO, 0x00);// Defaults to 0 seconds
	EEPROM.write(EEPROM_CAMERAPREFOCUS_UNITS,GUIMENU_UNITS_S);// Defaults to 0 seconds

	EEPROM.write(EEPROM_SHUTTERPULSE_HI, 0x00);// Defaults to 150ms
	EEPROM.write(EEPROM_SHUTTERPULSE_LO, 0x96);// Defaults to 150ms
	EEPROM.write(EEPROM_SHUTTERPULSE_UNITS, GUIMENU_UNITS_MS);// Defaults to 150ms

	EEPROM.write(EEPROM_FLASHPULSE_HI, 0x00);// Defaults to 30ms
	EEPROM.write(EEPROM_FLASHPULSE_LO, 0x1E);// Defaults to 30ms
	EEPROM.write(EEPROM_FLASHPULSE_UNITS, GUIMENU_UNITS_MS);// Defaults to 30ms

	//startrail
	EEPROM.write(EEPROM_STARTTRAIL_INTERVAL_HI, 0x00);		// Defaults to 0
	EEPROM.write(EEPROM_STARTTRAIL_INTERVAL_LO, 0x02);		// Defaults to 2
	EEPROM.write(EEPROM_STARTTRAIL_INTERVAL_UNITS, GUIMENU_UNITS_S);		// Defaults to 0

	EEPROM.write(EEPROM_STARTTRAIL_SHUTTERSPEED_HI, 0x00);		// Defaults to 0
	EEPROM.write(EEPROM_STARTTRAIL_SHUTTERSPEED_LO, 0x1E);		// Defaults to 30 sec
	EEPROM.write(EEPROM_STARTTRAIL_SHUTTERSPEED_UNITS, GUIMENU_UNITS_S);		// Defaults to seconds

	EEPROM.write(EEPROM_STARTTRAIL_COUNT_HI, 0x27);		// Defaults to INFINITE,
	EEPROM.write(EEPROM_STARTTRAIL_COUNT_LO, 0x11);		// Defaults to INFINITE,

	EEPROM.write(EEPROM_STARTTRAIL_WAIT_HI, 0x00);		// Defaults to 0
	EEPROM.write(EEPROM_STARTTRAIL_WAIT_LO, 0x00);		// Defaults to 0
	EEPROM.write(EEPROM_STARTTRAIL_WAIT_UNITS, GUIMENU_UNITS_S);		// Defaults to 0

	//HSF Defaults
	EEPROM.write(EEPROM_HSF_TRIGGERON, 0x01);			// Defaults to ANY
	EEPROM.write(EEPROM_HSF_CLOSESHUTTER, 0x00);		// Defaults to NO


	EEPROM.write(EEPROM_HSF_SHUTTERCYCLE_HI, 0);			// Defaults to 0 seconds (OFF)
	EEPROM.write(EEPROM_HSF_SHUTTERCYCLE_LO, 0);
	EEPROM.write(EEPROM_HSF_SHUTTERCYCLE_UNITS, GUIMENU_UNITS_S);


	EEPROM.write(EEPROM_HSF_FLASHDELAY_HI, 0x00);			 // Defaults to 0 milliseconds (OFF)
	EEPROM.write(EEPROM_HSF_FLASHDELAY_LO, 0x00);
	EEPROM.write(EEPROM_HSF_FLASHDELAY_UNITS, GUIMENU_UNITS_US);

	EEPROM.write(EEPROM_HSF_RESETDELAY_HI, 0);			 // Defaults to 1 second
	EEPROM.write(EEPROM_HSF_RESETDELAY_LO, 0x01);
	EEPROM.write(EEPROM_HSF_RESETDELAY_UNITS, GUIMENU_UNITS_S);

	EEPROM.write(EEPROM_HSF_START_HOURS, 0x00);		// Defaults to 0
	EEPROM.write(EEPROM_HSF_START_MINS, 0x00);		// Defaults to 0
	EEPROM.write(EEPROM_HSF_END_HOURS, 0x00);		// Defaults to 0
	EEPROM.write(EEPROM_HSF_END_MINS, 0x00);		// Defaults to 0

	EEPROM.write(EEPROM_HSF_TIMESACTIVE, 0x01);

	//BulbRamp Defaults
	EEPROM.write(EEPROM_BULBRAMP_START_EXPOSURE, 0x04);			// Defaults to 1/6
	EEPROM.write(EEPROM_BULBRAMP_END_EXPOSURE, 0x16);		// Defaults to 10

	EEPROM.write(EEPROM_BULBRAMP_STARTDELAY_HI, 0x00);			// Defaults to off
	EEPROM.write(EEPROM_BULBRAMP_STARTDELAY_LO, 0x0);		// Defaults to	off
	EEPROM.write(EEPROM_BULBRAMP_STARTDELAY_UNITS, GUIMENU_UNITS_S);

	EEPROM.write(EEPROM_BULBRAMP_COUNT_HI, 0x01);		// Defaults to 360
	EEPROM.write(EEPROM_BULBRAMP_COUNT_LO, 0x68);		// Defaults to	360

	EEPROM.write(EEPROM_BULBRAMP_DURATION_HI, 0x00);		// Defaults to 1 Hr
	EEPROM.write(EEPROM_BULBRAMP_DURATION_LO, 0x01);		// Defaults to 1 Hr
	EEPROM.write(EEPROM_BULBRAMP_DURATION_UNITS, GUIMENU_UNITS_H);		// Defaults to 1 Hr


	//LE_HDR
	EEPROM.write(EEPROM_LEHDR_MID_EXP, 0x0B);			//default 0.8
	EEPROM.write(EEPROM_LEHDR_SHOTS, 0x00);				//default 3
	EEPROM.write(EEPROM_LEHDR_EVPERSHOT, 0x02);			//default 1
	store_default_units_value (EEPROM_LEHDR_TIMELAPSE_HI, 0, GUIMENU_UNITS_S);

	//sensor
	EEPROM.write(EEPROM_SENSOR_TRIGDELAY_HI, 0x00);		// Defaults to 0
	EEPROM.write(EEPROM_SENSOR_TRIGDELAY_LO, 0x00);		// Defaults to 0
	EEPROM.write(EEPROM_SENSOR_TRIGDELAY_UNITS, GUIMENU_UNITS_MS);		// Defaults to 0
	EEPROM.write(EEPROM_SENSOR_TRIGGERON, 0x01);		// Defaults to 1
	EEPROM.write(EEPROM_SENSOR_MOBILEIP, 0x01);		// Defaults to 0
	EEPROM.write(EEPROM_SENSOR_MOBILEOP, 0x01);		// Defaults to 1
	EEPROM.write(EEPROM_SENSOR_TIMESACTIVE, 0x01);
	EEPROM.write(EEPROM_SENSOR_REST_DELAY_HI, 0x00);
	EEPROM.write(EEPROM_SENSOR_REST_DELAY_LO, 0x01);		// Defaults to 1
	EEPROM.write(EEPROM_SENSOR_RESET_UNITS, GUIMENU_UNITS_S);

	EEPROM.write(EEPROM_SENSOR_START_HOURS, 0x00);		// Defaults to 0
	EEPROM.write(EEPROM_SENSOR_START_MINS, 0x00);		// Defaults to 0
	EEPROM.write(EEPROM_SENSOR_END_HOURS, 0x00);		// Defaults to 0
	EEPROM.write(EEPROM_SENSOR_END_MINS, 0x00);		// Defaults to 0

	//sensor timelapse
	EEPROM.write(EEPROM_SENSORTLAPSE_DELAY_HI, 0x00);		// Defaults to 0
	EEPROM.write(EEPROM_SENSORTLAPSE_DELAY_LO, 0x00);		// Defaults to 0
	EEPROM.write(EEPROM_SENSORTLAPSE_DELAY_UNITS, GUIMENU_UNITS_S);		// Defaults to 0
	EEPROM.write(EEPROM_SENSORTLAPSE_INTERVAL_HI, 0x00);		// Defaults to 0
	EEPROM.write(EEPROM_SENSORTLAPSE_INTERVAL_LO, 0x01);		// Defaults to 1
	EEPROM.write(EEPROM_SENSORTLAPSE_INTERVAL_UNITS, GUIMENU_UNITS_S);
	EEPROM.write(EEPROM_SENSORTLAPSE_CONTINUE_HI, 0x00);		// Defaults to 0
	EEPROM.write(EEPROM_SENSORTLAPSE_CONTINUE_LO, 0x00);		// Defaults to 0
	EEPROM.write(EEPROM_SENSORTLAPSE_TRIGGERON, 0x01);
	EEPROM.write(EEPROM_SENSORTLAPSE_MOBILEIP, 0x01);
	EEPROM.write(EEPROM_SENSORTLAPSE_MOBILEOP, 0x01);
	EEPROM.write(EEPROM_SENSORTLAPSE_TIMESACTIVE, 0x01);		// Defaults to always
	EEPROM.write(EEPROM_SENSOR_TL_START_HOURS, 0x00);		// Defaults to 0
	EEPROM.write(EEPROM_SENSOR_TL_START_MINS, 0x00);		// Defaults to 0
	EEPROM.write(EEPROM_SENSOR_TL_END_HOURS, 0x00);		// Defaults to 0
	EEPROM.write(EEPROM_SENSOR_TL_END_MINS, 0x00);		// Defaults to 0
	EEPROM.write(EEPROM_SENSORTLAPSE_CONTINUE, 0x00);		// Defaults to 0

	//ADVANCE SENSOR
	EEPROM.write(EEPROM_ADVSENSOR_CHAN1A_DELAY_HI, 0x00);		// Defaults to 0
	EEPROM.write(EEPROM_ADVSENSOR_CHAN1A_DELAY_LO, 0x00);		// Defaults to 0
	EEPROM.write(EEPROM_ADVSENSOR_CHAN1A_DELAY_UNITS, GUIMENU_UNITS_MS);		// Defaults to 0

	EEPROM.write(EEPROM_ADVSENSOR_CHAN1B_DELAY_HI, 0x00);		// Defaults to 0
	EEPROM.write(EEPROM_ADVSENSOR_CHAN1B_DELAY_LO, 0x00);		// Defaults to 0
	EEPROM.write(EEPROM_ADVSENSOR_CHAN1B_DELAY_UNITS, GUIMENU_UNITS_MS);		// Defaults to 0

	EEPROM.write(EEPROM_ADVSENSOR_CHAN2A_DELAY_HI, 0x00);		// Defaults to 0
	EEPROM.write(EEPROM_ADVSENSOR_CHAN2A_DELAY_LO, 0x00);		// Defaults to 0
	EEPROM.write(EEPROM_ADVSENSOR_CHAN2A_DELAY_UNITS, GUIMENU_UNITS_MS);		// Defaults to 0

	EEPROM.write(EEPROM_ADVSENSOR_CHAN2B_DELAY_HI, 0x00);		// Defaults to 0
	EEPROM.write(EEPROM_ADVSENSOR_CHAN2B_DELAY_LO, 0x00);		// Defaults to 0
	EEPROM.write(EEPROM_ADVSENSOR_CHAN2B_DELAY_UNITS, GUIMENU_UNITS_MS);		// Defaults to 0

	EEPROM.write(EEPROM_ADVSENSOR_CHAN3A_DELAY_HI, 0x00);		// Defaults to 0
	EEPROM.write(EEPROM_ADVSENSOR_CHAN3A_DELAY_LO, 0x00);		// Defaults to 0
	EEPROM.write(EEPROM_ADVSENSOR_CHAN3A_DELAY_UNITS, GUIMENU_UNITS_MS);		// Defaults to 0

	EEPROM.write(EEPROM_ADVSENSOR_CHAN3B_DELAY_HI, 0x00);		// Defaults to 0
	EEPROM.write(EEPROM_ADVSENSOR_CHAN3B_DELAY_LO, 0x00);		// Defaults to 0
	EEPROM.write(EEPROM_ADVSENSOR_CHAN3B_DELAY_UNITS, GUIMENU_UNITS_MS);		// Defaults to 0

	//PULSE
	EEPROM.write(EEPROM_ADVSENSOR_CHAN1A_PULSE_HI, 0x00);
	EEPROM.write(EEPROM_ADVSENSOR_CHAN1A_PULSE_LO, 0x96);
	EEPROM.write(EEPROM_ADVSENSOR_CHAN1A_PULSE_UNITS, GUIMENU_UNITS_MS);

	EEPROM.write(EEPROM_ADVSENSOR_CHAN1B_PULSE_HI, 0x00);
	EEPROM.write(EEPROM_ADVSENSOR_CHAN1B_PULSE_LO, 0x96);
	EEPROM.write(EEPROM_ADVSENSOR_CHAN1B_PULSE_UNITS, GUIMENU_UNITS_MS);

	EEPROM.write(EEPROM_ADVSENSOR_CHAN2A_PULSE_HI, 0x00);
	EEPROM.write(EEPROM_ADVSENSOR_CHAN2A_PULSE_LO, 0x96);
	EEPROM.write(EEPROM_ADVSENSOR_CHAN2A_PULSE_UNITS, GUIMENU_UNITS_MS);

	EEPROM.write(EEPROM_ADVSENSOR_CHAN2B_PULSE_HI, 0x00);
	EEPROM.write(EEPROM_ADVSENSOR_CHAN2B_PULSE_LO, 0x96);
	EEPROM.write(EEPROM_ADVSENSOR_CHAN2B_PULSE_UNITS, GUIMENU_UNITS_MS);

	EEPROM.write(EEPROM_ADVSENSOR_CHAN3A_PULSE_HI, 0x00);
	EEPROM.write(EEPROM_ADVSENSOR_CHAN3A_PULSE_LO, 0x96);
	EEPROM.write(EEPROM_ADVSENSOR_CHAN3A_PULSE_UNITS, GUIMENU_UNITS_MS);

	EEPROM.write(EEPROM_ADVSENSOR_CHAN3B_PULSE_HI, 0x00);
	EEPROM.write(EEPROM_ADVSENSOR_CHAN3B_PULSE_LO, 0x96);
	EEPROM.write(EEPROM_ADVSENSOR_CHAN3B_PULSE_UNITS, GUIMENU_UNITS_MS);
	// THE REST
	EEPROM.write(EEPROM_ADVSENSOR_TRIGMOBILE, 0x01);
	EEPROM.write(EEPROM_ADVSENSOR_REST_DELAY_HI, 0x00);		// Defaults to 0
	EEPROM.write(EEPROM_ADVSENSOR_REST_DELAY_LO, 0x00);		// Defaults to 0
	EEPROM.write(EEPROM_ADVSENSOR_REST_DELAY_UNITS, GUIMENU_UNITS_MS);		// Defaults to 0
	EEPROM.write(EEPROM_ADVSENSOR_TRIGGER_ON, 0x01);

	//sensor video
	store_default_units_value (EEPROM_SENSORVIDEO_DELAY_HI, 0, GUIMENU_UNITS_S);
	store_default_units_value(EEPROM_SENSORVIDEO_STOPAFTER_HI, 30, GUIMENU_UNITS_S);
	EEPROM.write(EEPROM_SENSORVIDEO_TRIGGER, 0);
	EEPROM.write(EEPROM_SENSORVIDEO_TIMESACTIVE, 0);
	EEPROM.write(EEPROM_SENSORVIDEO_START_HOURS, 0x00);
	EEPROM.write(EEPROM_SENSORVIDEO_START_MINS, 0x00);
	EEPROM.write(EEPROM_SENSORVIDEO_END_HOURS, 0x00);
	EEPROM.write(EEPROM_SENSORVIDEO_END_MINS, 0x00);
	EEPROM.write(EEPROM_SENSORVIDEO_TRIGGERON, 0);

	#ifdef INCLUDE_NEWMODE
	EEPROM.write (EEPROM_NEWMODE_TRIGGERON, STACK_TRIGGER_ONLY);
	EEPROM.write (EEPROM_NEWMODE_DELAY_HI, 0x00);
	EEPROM.write (EEPROM_NEWMODE_DELAY_LO, 0x01);
	EEPROM.write (EEPROM_NEWMODE_DELAY_UNITS, GUIMENU_UNITS_S);
	#endif	
}


void setup(){
	
 pinMode(BackLight,OUTPUT);
 digitalWrite(BackLight, 0);
 	
#ifdef VERSION_THREE_HW
  pinMode(LCD_POWER, OUTPUT);
  digitalWrite(LCD_POWER, 0);
#endif
 
  pinMode(Stack,INPUT);
  pinMode(UpButton,INPUT);
  pinMode(DownButton,INPUT);
  pinMode(LeftButton,INPUT);
  pinMode(SelectButton,INPUT);
  pinMode(RightButton,INPUT);	//returns nothing
  
  pinMode(AudioRight,INPUT);
  pinMode(AudioLeft,INPUT);
  
  pinMode(Focus,OUTPUT);
  pinMode(Trigger,OUTPUT);
  pinMode(CAMERAOUT2_A,OUTPUT);		
  pinMode(CAMERAOUT2_B,OUTPUT);		
  pinMode(CAMERAOUT3_A,OUTPUT);
  pinMode(CAMERAOUT3_B,OUTPUT);

#ifndef VERSION_THREE_HW
  pinMode(BONUS_PIN,OUTPUT);
  digitalWrite(BONUS_PIN,HIGH);
#endif
  
  pinMode(MIC,OUTPUT);
  pinMode(STACK_PWR,OUTPUT);
	
  digitalWrite(CAMERAOUT2_A, 0);
  digitalWrite(CAMERAOUT2_B, 0);
  digitalWrite(CAMERAOUT3_A, 0);
  digitalWrite(CAMERAOUT3_B, 0);
  digitalWrite(Focus, 0);
  digitalWrite(Trigger, 0);
  digitalWrite(MIC, 0);
 
	//////////////////////////////////////////////////////////////////////////////////////////////////////////////////////////////////////////////////
	//
	//				8Mhz clock chosen for startup, to remain in safe operating
	//				zone during low battery conditions. Once the Boost converter has started
	//				a faster clock can be chosen
	//
	//////////////////////////////////////////////////////////////////////////////////////////////////////////////////////////////////////////////////
	
	//8MHz Clock
	OSC.CTRL |= OSC_RC32MEN_bm; // turn on 32 MHz oscillator
	CCP = CCP_IOREG_gc;
	CLK.PSCTRL = 0b0001100;
	while (!(OSC.STATUS & OSC_RC32MRDY_bm)) { }; // wait for it to start
	DFLLRC32M.CTRL = DFLL_ENABLE_bm ;				//enable calibrated clock
	CCP = CCP_IOREG_gc;
	CLK.CTRL = CLK_SCLKSEL_RC32M_gc;
 
	//Adjust timings accordingly
	
	TCF0.CTRLA    = TC_CLKSEL_DIV2_gc;			//
  
#ifndef _FASTBOOT

  if(!digitalRead(SelectButton))		//Has the user pressed the button to turn the device on?
  {
	if(EEPROM.read (EEPROM_LCD_CONTRAST_SET) != 0xFF)		//if this is the first time we power up, don't wait for 2 seconds
	{
		delay(2000);						//wait for 2 sec
	}
	
  }
  
  
  if(digitalRead(SelectButton))
  {
	PowerDownFunc(input);				//If not, then false alarm (batteries have been replaced)
  }
  
  #ifdef VERSION_THREE_HW
  pinMode(LCD_POWER, OUTPUT);
  digitalWrite(LCD_POWER, 1);
  #endif
  
  digitalWrite(BackLight, 1);
	
#endif // _FASTBOOT

  digitalWrite(STACK_PWR, 0);	//turn power to the stack off 
#ifdef VERSION_THREE_HW
  pinMode(LDO_EN,OUTPUT);
#endif
  digitalWrite(LDO_EN, 1);


		  
  PORTA_INTCTRL = 0x00;			//interrupt priority off
  

	start_lcd (DEFAULT_LCD_CONTRAST);

	
	
	
if(!digitalRead(UpButton) && !digitalRead(DownButton))		//condition for factory re-set
{
	EEPROM.write(EEPROM_LCD_CONTRAST_SET, 0xFF);

	guimenu_clearpage();
	guimenu_println("FACTORY RESET!");
	guimenu_updatepage();
	delay(2000);
	reset();
}
  

    guimenu_update();

    SetupDelay = 0;
    ReTriggerDelay = 1;
    SMobileOutputEnabled = 0;
    SMobileInputEnabled = 0;
	
	Infinite = 1;
	Interval = 1;
	SelectedStartDelay = 0;
	
	//stack defaults
	EEPROM.write(EEPROM_STACK_CONFIG,OR_CONFIG);
	
	pinMode(BATTERY_MON,INPUT);
	

	ADCB.CTRLA = ADC_ENABLE_bm ; // Enable the ADC
	ADCB.CTRLB = (1<<4); // Signed Mode
	ADCB.REFCTRL = 0; // Internal 1v ref
	ADCB.EVCTRL = 0 ; // no events
	ADCB.PRESCALER = ADC_PRESCALER_DIV64_gc ;
	delay(1);
	ADCB.CH0.CTRL = ADC_CH_INPUTMODE0_bm; // 0x01
	ADCB.CH0.MUXCTRL = ADC_CH_MUXINT0_bm;
	ADCB.CH0.INTCTRL = 0; // No interrupt
	
	
	
	
	MobileTriggerSetup();

	LowSysClock();
	
	PORTA_INTCTRL = 0x00;			//interrupt priority off
}

void store_default_units_value (uint8_t address, uint16_t store_value, uint8_t units)
{
	uint8_t hi, lo;
	
	hi = store_value >> 8;
	lo = store_value - (hi << 8);
	
	EEPROM.write(address, hi); 
	EEPROM.write((address + 1), lo);
	EEPROM.write((address + 2), units);	
}



/*****************************************************************************
*
*   Function name : LowBattery
*
*   Returns :       NIL
*
*   Parameters :
*
*   Purpose : indicates a low battery
*
*****************************************************************************/

void LowBattery (void)
{
	guimenu_clearpage();
	guimenu_println ("BATTERY DEPLETED");
	guimenu_updatepage();
	delay (3000);
	PowerDownFunc (input);
}
/*****************************************************************************
*
*   Function name : timer1
*
*   Returns :       NIL
*
*   Parameters :
*
*   Purpose : Sets up Timer 1 interrupt
*
*****************************************************************************/

void timer1(int ms){ 

	//with a 16MHz clock divided by 8 means there are 2000 ticks per millisecond 
	TC_SetPeriod(&TCC1,ms*2000); 
	TC1_SetOverflowIntLevel(&TCC1,TC_OVFINTLVL_LO_gc); 
	TC1_ConfigClockSource(&TCC1,TC_CLKSEL_DIV8_gc); 
	
}

	
/*****************************************************************************
*
*   Function name : HardwareTest
*
*   Returns :       NIL
*
*   Parameters :
*
*   Purpose : 
*
*****************************************************************************/
#ifndef _DISABLE_OLD_CODE
void HardwareTest()
{
		pinMode(MIC,OUTPUT);
		analogWrite(13, 160);
		while(1);
}


/*****************************************************************************
*
*   Function name : MIC_OUT
*
*   Returns :       NIL
*
*   Parameters :  
*
*   Purpose :      
*
*****************************************************************************/

void MIC_OUT()
{
  while(GetButton() == KEY_NULL)    //repeat until button pressed
  {
    digitalWrite(MIC,1);
    delayMicroseconds(500);
    digitalWrite(MIC,0);
    delayMicroseconds(500); 
  }
}
#endif
/*****************************************************************************
*
*   Function name : AUDIO_READ
*
*   Returns :       NIL
*
*   Parameters :  
*
*   Purpose :      
*
*****************************************************************************/

int AUDIO_READ(void)
{
  static int Value;
 
   uint8_t oldSREG = SREG;
   cli();					//disable interrupts whilst taking an analog read as otherwise the data might be corrupted by the battery monitor reading
   Value = analogRead(AudioLeft);
   SREG = oldSREG;


   if(Value >= 60)                //if above a setpoint then output. analog read returns 0 - 255
   {
     return 1;
   }
  
#ifdef _STEREO_MOBILE 

   Value = analogRead(AudioRight);    
   
   if(Value >= 60)
   {
     return 1;
   }
   
#endif   //_STEREO_MOBILE

   else
   {
     return 0;
   }
   
   
 
}
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
void loop (void)
{
	char current_menu_page = GUIMENU_TIMELAPSE_TITLE_PAGE;
  
	state = nextstate = ST_TMLPSE;
	pStateFunc = NULL;
  
	// Display Splash Screen for a certain time
	guimenu_displaypage (GUIMENU_START_PAGE);
	
	#ifndef _FASTBOOT
	delay (3000);
	#endif
	
	
	// Display Initial Menu
	guimenu_displaypage (current_menu_page);

	while(1)
	{
		
		input = GetButton();    //Check keypad situation
		  
		if (pStateFunc)
		{
			// When in this state, we must call the state function
			nextstate = pStateFunc(input);
		}
		else if (input != KEY_NULL)
		{
			// Plain menu, clock the state machine
			nextstate = StateMachine (state, input);
		}

        if (nextstate != state)
        {
			state = nextstate;
			for (current_menu_page=0; menu_state[current_menu_page].state; current_menu_page++)
            {
                if (menu_state[current_menu_page].state == state)
                {
					guimenu_displaypage (menu_state[current_menu_page].page_number);
					pStateFunc = menu_state[current_menu_page].pFunc;
					delay(250);
					break;
                }
            }
        }
	}
}
  

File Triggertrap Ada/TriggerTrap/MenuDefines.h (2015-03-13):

#ifndef DEFINES_H
#define DEFINES_H

#define TRUE						1
#define FALSE						0


#define ST_TMLPSE                			1
#define ST_LEHDR_START						2
#define ST_HSF                   			3
#define ST_LEHDR_MIDEXP_SET					4
#define ST_SEN_TL          					5
#define ST_LEHDR_SHOTS_SET					6
#define ST_SETTINGS             			7
#define ST_LEHDR_EVPERSTEP_SET				8
#define ST_LEHDR_TIMLAPSE_SET				9
#define ST_LEHDR_STOP						10
#define ST_SENSOR_START						11
#define ST_SENSOR_STOP						12
#define ST_SENSOR_TRIGGER_DELAY				13
#define ST_HSF_CLOSESHUTTER_SET				14
#define ST_HSF_SHUTTERCYCLE_SET				15
#define ST_HSF_FLASH_DELAY_SET				16
#define ST_HSF_RESETDELAY_SET				17
#define ST_HSF_OP_TACTVE					18
#define ST_SENSOR_RESET_DELAY				19
#define ST_SENSOR_TRIGGER_ON				20
#define ST_SENSOR_MOBILE_INPUT				21
#define ST_SENSOR_MOBILE_OUTPUT				22
#define ST_SENSOR_TIME_ACTIVE				23
#define ST_SENSOR_START_TIME				24
#define ST_SENSOR_STOP_TIME					25
#define ST_SETTINGS_OP_PREFOCUS				26
#define ST_SETTINGS_OP_SHTPLSE				27
#define ST_SETTINGS_OP_FLSHPLSE				28
#define ST_SETTINGS_OP_SETCLK				29
#define ST_SENSOR_CONFIG_PROGESS			30
#define ST_SEN_TL_CONFIG_PROGESS			31
#define ST_SENSORVIDEO_CONFIG_PROGESS		32
#define ST_ADVSENSOR_CONFIG_PROGESS			33
#define ST_SEN_TL_CONTINUE					34
#define ST_SEN_TL_TRIGGER					35
#define ST_SEN_TL_MOBILE_INPUT				36		
#define ST_SEN_TL_MOBILE_OUTPUT				37		
#define ST_SEN_TL_TIME_ACTIVE				38		
#define ST_SEN_TL_START_TIME				39			
#define ST_SEN								40
#define ST_SEN_RUN							41
#define ST_SEN_RUNNING						42
#define ST_OFF								43
#define ST_OFF_FUNC							44
#define ST_SEN_TL_STOP_TIME					45
#define ST_SEN_TL_CONTINUE_SET				46
#define ST_OFF_CONFIRM						47
#define ST_OFF_CANCEL						48
#define ST_UNSUPPORTED						49
#define ST_SEN_OP_TRGR						50
#define ST_SEN_STACK_AND					51
#define ST_SEN_STACK_OR						52
#define ST_SEN_STACK_OR_FUNC				53
#define ST_SEN_STACK_AND_FUNC				54
#define ST_SEN_RESET_DELAY					55
#define ST_SEN_START_DELAY					56
#define ST_SEN_RESET_DELAY_FUNC				57
#define ST_SEN_START_DELAY_FUNC				58
#define ST_SEN_TRIGGER_DELAY				59
#define ST_SEN_TRIGGER_DELAY_FUNC			60
#define ST_SEN_TL_START						66
#define ST_SEN_TL_STOP						67
#define ST_SEN_TL_DELAY						68
#define ST_SEN_TL_INTERVAL					69
#define ST_SETTINGS_OP_SETCLK_FUNC			70
#define ST_TMLPSE_OP_TACTIVE_ENABLE			71
#define ST_TMLPSE_OP_TACTIVE_START			72
#define ST_TMLPSE_OP_TACTIVE_END			73
#define ST_TMLPSE_OP_TACTIVE_START_FUNC		74
#define ST_TMLPSE_OP_TACTIVE_END_FUNC		75
#define ST_A_SENSOR_START					76
#define ST_A_SENSOR_STOP					77
#define ST_A_SENSOR_CH1A_D					78
#define ST_A_SENSOR_CH1A_P					79
#define ST_A_SENSOR_CH1B_D					80
#define ST_A_SENSOR_CH1B_P					81
#define ST_A_SENSOR_CH2A_D					82
#define ST_A_SENSOR_CH2A_P					83
#define ST_A_SENSOR_CH2B_D					84
#define ST_A_SENSOR_CH2B_P					85
#define ST_A_SENSOR_CH3A_D					86
#define ST_A_SENSOR_CH3A_P					87
#define ST_A_SENSOR_CH3B_D					88
#define ST_A_SENSOR_CH3B_P					89
#define ST_A_SENSOR_TRIGGER_MOBILE			90
#define ST_A_SENSOR_RESET_DELAY				91
#define ST_A_SENSOR_TRIGGER_ON				92
#define ST_TIMEWARP							93
#define ST_BULBRAMP							94
#define ST_STARTRAIL						95
#define ST_SENSVIDEO						96
#define ST_ADVANCESENS						97
#define ST_LEHDR							98
#define ST_HSF_OP_TRIG_AND					99
#define ST_HSF_OP_TRIG_OR					100
#define ST_HSF_STACK_AND_FUNC				101
#define ST_HSF_STACK_OR_FUNC				102
#define ST_HSF_OP_SHTRCYC_FUNC				103
#define ST_HSF_OP_FLSHDLY_FUNC				104
#define ST_HSF_OP_RSTDLY_FUNC				105
#define ST_HSF_OP_START						106
#define ST_HSF_OP_START_FUNC				107
#define ST_HSF_OP_CLSHTR_FUNC_YES			108
#define ST_HSF_OP_CLSHTR_FUNC_NO			109
#define ST_STARTRAIL_RUN					110
#define ST_STARTRAIL_INTERVAL				111
#define ST_STARTRAIL_SHTR_SPD				112
#define ST_STARTRAIL_CNT					113
#define ST_STARTRAIL_WAIT					114
#define ST_STARTRAIL_RUN_FUNC				115
#define ST_BULBRAMP_RUN_FUNC				116
#define ST_LEHDR_RUN						117
#define ST_LEHDR_RUN_FUNC					118
#define ST_TIMEWARP_RUN_FUNC				119
#define ST_SETTINGS_OP_PREFOCUS_FUNC		120
#define ST_SETTINGS_OP_SHTPLSE_FUNC			121
#define ST_SETTINGS_OP_FLSHPLSE_FUNC		122
#define ST_ADVANCESENS_1A					123
#define ST_ADVANCESENS_1A_FUNC				124
#define ST_ADVANCESENS_1B					125
#define ST_ADVANCESENS_1B_FUNC				126
// 127 seems to cause crashes
#define ST_ADVANCESENS_2A					128
#define ST_ADVANCESENS_2A_FUNC				129
#define ST_ADVANCESENS_2B					130
#define ST_ADVANCESENS_2B_FUNC				131
#define ST_ADVANCESENS_MOB					132
#define ST_ADVANCESENS_MOB_FUNC				133
#define ST_ADVANCESENS_RSTDLY				134
#define ST_ADVANCESENS_RSTDLY_FUNC			135
#define ST_ADVANCESENS_TRG					136
#define ST_ADVANCESENS_TRG_AND				137
#define ST_ADVANCESENS_TRG_OR				138
#define ST_ADVANCESENS_TRG_OR_FUNC			139
#define	ST_ADVANCESENS_TRG_AND_FUNC			140
#define ST_ADVANCESENS_1A_DELAY				141
#define ST_ADVANCESENS_1B_DELAY				142
#define ST_ADVANCESENS_2A_DELAY				143
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

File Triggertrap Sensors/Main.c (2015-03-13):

/*
 Triggertrap Ada Source - High Speed Camera Trigger and Intervalometer
 Copyright (C) 2015  Triggertrap
 
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
 You should have received a copy of the GNU General Public License
 along with this program.  If not, see <http://www.gnu.org/licenses/>.
 */

#include "main.h"
#include "pir_mic.h"
#include "light.h"
#include "laser.h"
#include "utils.h"

/* CONFIG BITS */
#ifdef LASER_SENSOR_VERSION
#pragma config FOSC = HS        // Oscillator Selection (HS oscillator and automatic 18 ms DRT (DRTEN ignored))
#else
#pragma config FOSC = INTRC_IO  // Oscillator Selection (INTRC with I/O function on OSC2/CLKOUT and 10 us startup time)
#endif

#pragma config WDTE = OFF       // Watchdog Timer Enable (WDT Disabled)
#pragma config CP = OFF         // Code Protection - User Program Memory (Code protection off)
#pragma config MCLRE = OFF      // Master Clear Enable (MCLR pin functions as MCLR)
#pragma config IOSCFS = 8MHz    // Internal Oscillator Frequency Select (8 MHz INTOSC Speed)
#pragma config CPSW = OFF       // Code Protection - Self Writable Memory (Code protection off)
#pragma config BOREN = OFF      // Brown-out Reset Enable (BOR Disabled)
#pragma config DRTEN = OFF      // Device Reset Timer Enable (DRT Disabled)

// Globals
SENSOR_INFO sensor_info;
SENSOR_CONFIG sensor_config;
unsigned int count = 0, count2 = 0;
unsigned char adc = 0;


void init (void);
void option_select (void);
void ping (void);


void main (void)
{
    init(); // initialise ports
    option_select (); // Check which sensor is connected
    RC5 = 0;
    sensor_info.low_power = 0;
    LASER = 0;
    ping (); // wait for signal from baseblock, then send signal back

    //TRISC = 0b10000100;
    STACK_OUT = 1;
    SHDN_B = 1; // Turn on opamp used for PIR
    //TRISC = 0b10000100;
    //  count=0;

    switch (sensor_info.sensor)
    {
        case PIR_SENSOR:
            pir_mic (PIR_RESET_COUNT, PIR_LOW_THRESHOLD, PIR_HIGH_THRESHOLD);
        break;

        case MIC_SENSOR:
            pir_mic (MIC_RESET_COUNT, MIC_LOW_THRESHOLD, MIC_HIGH_THRESHOLD);
        break;

        case LIGHT_SENSOR:
            light ();
        break;

        case LASER_SENSOR:
            laser ();
        break;
    }

    while (1);
}


void init (void)
{
    PORTAbits.RA1 = 1;

    TRISA = 0x28; // STACK_IN as input

    TRISC = 0x84; // SET ANA_TRIG AND SWITCH AS INPUTS

    TRISB = 0b11100000; // TEST PIN AND VOLTAGE DIVIDERS AS INPUTS

    CM2CON0bits.C2PREF2 = 1;
    CM2CON0bits.C2ON = 0;
    ANSELbits.ANS5 = 0;
}


// Selects which sensor board it is based on voltage dividers, chooses which main code to follow
void option_select (void)
{
    __delay_ms (DELAY);
    if (OPTION_SELECT1 == 0)
    {
        if (OPTION_SELECT2 == 0)
        {
            sensor_info.sensor = PIR_SENSOR;
        } 
        else
        {
            sensor_info.sensor = MIC_SENSOR;
        }
    } 
    else if (OPTION_SELECT1 == 1)
    {
        if (OPTION_SELECT2 == 0)
        {
            sensor_info.sensor = LIGHT_SENSOR;
        } 
        else
        {
            sensor_info.sensor = LASER_SENSOR;
        }
    }
}


// wait for signal from baseblock/adjacent sensor
void ping (void)
{
    unsigned int a = 0;
    ANSELbits.ANS2 = 0;
    OPTION = 11000000;
    CM1CON0bits.nC1OUTEN = 1;
    CM1CON0bits.C1ON = 0;
    PORTAbits.RA2 = 1;
    STACK_OUT = 1;
    sensor_config.Y = 0;
    count = 0;
    LED = 0;
    TRISC = 0b10000110; // switch STACK_OUT (jack) to an input
    while (sensor_config.Y == 0) // waits here for the first pulse (OR mode)
    {
        if (STACK_OUT == 0) {
            sensor_config.OR = 1;
            sensor_config.Y = 1; // OR MODE
            count = 1; // increase count to 1
            while (STACK_OUT == 0); // make sure first pulse has ended
        }
    }
    while (a < AND_PULSE_COUNT) // wait for another pulse (AND mode)
    {
        if (STACK_OUT == 0) // if a second pulse is detected
        {
            sensor_config.AND = 1;
            sensor_config.OR = 0; // AND MODE
            count = 2; // change count to 2
            a = (AND_PULSE_COUNT + 1000); // end the count
            while (STACK_OUT == 0); // make sure second pulse has ended
        }
        a++;

    }
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

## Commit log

2015-03-13 Added Ada source files.
    [TRIG.X.production.obj, l.obj]
2015-03-13 Further formatting fixes for readme
    One day I’ll get this right.
2015-03-17 Adding casings and plastics
    [TT-110-A_ADA_BASE_FRONT_CASE.STEP, TT-113-A_ADA_LCD_SCREEN.STEP, TT-120-A_ADA_BASE_BATTERY_COVER.STEP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]
2015-03-17 Adding electronics and BOMs
    [Ada - Base Block - Baseblock_issue 4.0.PcbDoc, Ada - Base Block - Bill of Materials Issue 4.0.xls, Ada - Base Block - Cover sheet Issue 4.0.SchDoc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]
2015-04-29 Missing Files
    Added Highspeedflash.h, Inputs.h, LongExposureHDR.h and Timelapse.h.
    Commented out Clock.h in wiring.c

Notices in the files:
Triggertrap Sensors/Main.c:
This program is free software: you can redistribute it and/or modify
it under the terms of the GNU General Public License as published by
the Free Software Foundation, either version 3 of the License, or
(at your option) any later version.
